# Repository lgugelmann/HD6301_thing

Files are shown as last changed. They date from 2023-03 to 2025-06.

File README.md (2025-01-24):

# Exploring the HD6301V1

I recently received a few samples of a Hitachi `HD6301V1` in a DIP-40
package. It's a 1MHz 8bit CPU derived from the Motorola 6801 with a few extra
instructions. It has an onboard mask-programmed 4k ROM, 128 bytes RAM, and 4 I/O
ports that can be used as some combination of data or address bus, or I/O
lines. It also comes with an onboard serial interface. Overall it's a really
neat chip!

- The datasheet for the HD6301v1 can be found
e.g. [here](https://pdf1.alldatasheet.com/datasheet-pdf/view/87402/HITACHI/HD6301V1.html).
- An _extensive_ handbook for the entire Hitachi 6301/6303 series of CPUs,
including copies of all datasheets, can be found on
[archive.org](https://archive.org/details/bitsavers_hitachidateriesHandbook1989_54281821).

This repository contains schematics and code to build a retro-inspired computer
around this chip. The idea is to build this off of modular components and a
shared bus so we can start small and build up piece by piece.

Currently I have a working device with Arduino-like ease of programmability, PS2
keyboard input, HDMI video output. It's complete enough for a working 'Snake'
clone that can be played over both serial console and video out.

## Getting started on a breadboard

The architecture is quite simple and similar to other 8-bit CPUs like
the 6502. There is one 16-bit address bus, one 8-bit data bus, a clock line, a
read/write line, and an interrupt line.

One way in which this chip departs from e.g. a 6502 is that it has several
different 'modes' that affect the memory layout and external buses. Mode
selection is done at startup using the first 3 lines of port 2. After startup
these lines can be reused for other purposes if desired. Mode 1
(non-multiplexed) breaks out all 16 address and 8 data lines. Mode 5 reduces the
external address bus to 8 lines. Mode 0/2/4/6 multiplex the data bus: at the
beginning of the cycle the 8 low address bits are presented, then an address
latch signal fires, then the 8 data bits are set. This frees up one 8-bit port
for I/O. Mode 7 has no external buses at all. Mode 0/5/6/7 map the internal ROM
to the top of the address space. It's inaccessible in 1/2/4. Mode 0 ('test
mode') has a special handling for the first read of the startup vector addresses
at $FFFE/$FFFF: instead of reading them from ROM (as it would in any subsequent
read) they are read over the external bus. This allows one to override the
ROM-interal startup vector while still keeping it accessible otherwise.

By selecting mode 1 at startup it's easy to get this chip to work on a
breadboard by just adding some external parallel RAM / ROM with a bit of address
decoding to select which one to access.

The chip has an internal 4x clock-divider. To get it to run at the max 1MHz you
need a 4MHz oscillator. I had no stability issues on a breadboard even at max
frequency.

The chip requires a minimum 100kHz to run (400kHz oscillator). Going below makes
it unstable.

## Random hardware notes

This is a collection of random notes about the hardware that are either
well-hidden in the datasheet or not documented at all.

- The IRQ line is not specified to be open-drain. It's likely not.
- The reset and standby pins are drawn with Schmitt-trigger inputs in the
  datasheet.
- The datasheet recommends 74'373 chips to latch the address bits in multiplexed
  mode. The '573 is probably a better choice for layout reasons as it has the
  same functionality but instead of having in/out pins next to each other it has
  all 8 inputs on one side and the 8 outputs on the other.
- P21 is not a general purpose I/O pin (even after mode selection). It is either
  a general input, or timer output.
- The mode selection / P2 multiplexing circuit in the datasheet would probably
  not work with a modern '4053 chip. The one in the datasheet has minimum
  switching times higher than the required hold times on the mode selection
  pins. Modern '4053 are faster.
- Reset and power-up are a bit finicky. The datasheet says reset must be held
  low for at least 20ms at power-on time. That's good advice. Without the wait
  time the MCU seems to start working a hair before the power rail reaches
  3V. The clock and data / address lines have their 'high' bits at that voltage
  too. At that point in time a typical 5V ROM might not even have powered up yet
  and you get all sorts of fun non-deterministic behavior. Something like a
  Diodes Inc. `APX811-46` is a great way to satisfy that requirement as it keeps
  reset low after power-up for 100-200ms.  Alternatively, the datasheet seems to
  suggest that the reset line has a Schmitt-trigger input. That would make an RC
  circuit with a long time constant also workable. Have not tried that.
- Exiting the standby mode requires holding reset low 20ms longer than STBY.

## The mask-programmed ROM

The samples I have come mask-programmed with some unknown code. The
`internal_rom` folder contains a dump of that ROM, some very preliminary
disassembly, and details on how to do such a dump using the 'test mode' of the
chip.

The ROM configures the data direction registers of all 4 I/O ports to a
combination of inputs/outputs. This suggests that it was meant to work in
single-chip mode. The MC6801 was popular in automotive applications - maybe this
one was meant to go into a car too.

## Contents of the repository

### Hardware modules

On the hardware side the repository contains
- The main CPU board. This can be used as a fully functional standalone
  single-board computer with 32kB RAM and ROM.
- A programming board to make programming the main CPU board as easy as
  programming an Arduino. This is a Raspberry Pi Pico-based board for USB
  connectivity to a host computer. It can put the main CPU into standby, take
  over the bus, and read or write to RAM/ROM as needed.
- A "video chip" board with HDMI output. This is another Pi Pico-based board
  that implements various graphical modes like a 100x40 or 100x75 text terminal
  with 6-bit color for each foreground and background. On the HDMI side it's
  800x600 pixel. On the bus it presents 64 write-only registers that implement
  various commands like setting characters, colors, or doing cursor moves.

Currently in progress are:
- An audio board based around the OPL3 FM synthesis chips.

### Software

#### HD6301 programs

The 'asm' folder contains software to run on the HD6301. There is a monitor
program for debugging, running other programs, and to provide some basic
libraries for PS2 keyboard handling and more.

There are also various test programs as well as a 'Snake' clone and a simple
audio sequencer.

See the docs in the 'asm' folder for more details.

#### Supporting software

- Much of the glue logic (address decoding, PS2 serial/parallel decoding, etc.)
  is implemented with GreenPAK SLG46826 programmable logic chips (see
  below). The 'greenpak' folder contains a simple python script to program these
  chips via i2c using an FTDI232h breakout board.
- The 'pico\_programmer' and 'pico\_graphics' folders contain the respective
  software for those those chips. The pico programmer has two parts: one to go
  onto the Pi Pico and a Python program to interface with it via serial port to
  do the actual programming.

## Bus documentation

All modules communicate over the following shared bus.

| Pin number | Function | Notes |
|---|---|---|
| 1..4 | Data bits D0..D3 | Bus users need to coordinate who's driving |
| 5 | 5V | Only one device is allowed to power this |
| 6 | GND | |
| 7..10 | Data bits D4..D7 | Bus users need to coordinate who's driving |
| 11..14 | Address bits A0..A3 | Bus users need to coordinate who's driving |
| 15 | 3.3V | Only one device is allowed to power this, optional |
| 16 | GND | |
| 17..24 | A4..A11 | Bus users need to coordinate who's driving |
| 25 | GND | |
| 26 | 3.3V | Only one device is allowed to power this, optional |
| 27..30 | A12..A15 | Bus users need to coordinate who's driving |
| 31 | RX | Serial receive as seen from a device on the bus |
| 32 | TX | Serial transmit as seen from a device on the bus |
| 33 | CLK | Bus clock |
| 34 | R/WB | Read is high |
| 35 | GND | |
| 36 | 5V | Only one device is allowed to power this |
| 37 | C1 | Control line 1, up to the exact devices on the bus to decide what this does. |
| 38 | C2 | Control line 2, up to the exact devices on the bus to decide what this does. |
| 39 | RESETB | Active low reset. Open drain. Pullup on CPU board. |
| 40 | IRQB | Active low interrupt. Open drain. Pullup on CPU board. |

This is 40 pins as it's easy to find 40pin IDC connectors and ribbon cables. The
power / GND pins are mirrored so that an upside-down connector has them in the
same place.

There are no chip select pins. Additional boards that want to fit into specific
parts of the memory map need to decode the address pins on their board and
coordinate with everyone else. Programmable GreenPAKs make this easy enough.

Pins are all push-pull unless stated otherwise. Any shared use needs to be
coordinated.

Logic levels are assumed 5V CMOS.

This is not how one designs for signal integrity - but it works well enough for
me. The user-friendliness of getting a ribbon cable to a breadboard to prototype
the next module is the overriding concern here.

### Bus details for HD6301 board

| Pin number | Function | Notes |
|---|---|---|
| 38 | STBYB | Active low standby signal. For Pico Programmer to make HD6301 let go of the bus. |

## Work log

This section contains possible projects and the state of the current in-progress
pieces of work.

### Faster SD card reads

The next goal is to get faster SD card reads as described in `asm/README.md`.
This means emulating the schematic in `io_board` in the emulator.

Tasks:

- Emulator:
  - ~~Create basic shift register output support in W65C22~~
  - ~~Figure out how to emulate clock inversion and delay~~
  - ~~Emulate a serial-in, parallel-out shift register like 74'164 series.~~
  - ~~Connect the above two pieces in-between the W65C22 and the current SPI emulation.~~
- ASM
  - ~~Update the code to use SR instead of bit-banging on a port for SPI~~
- Hardware
  - ~~Actually try the approach in real hardware~~ \[done, down to ~10ms\]
  - Write out schematics and design the board

### Documentation and repository cleanup

Any day now! This README file is badly outdated vs the state of the project. It
doesn't mention the emulator at all for example. The various hardware modules
should also be listed and better documented.

Tasks:

- Pick a standard for how to structure the individual module folders and stick to it
  - Put a README.md with each module, and document all known hardware issues.
  - I don't like the catch-all `greenpak` folder. That should go with the modules.
- Get rid of the `ft231x_programmer` stuff. It's an early idea that's now badly
  outdated.
- Rename `board` to something better.
- Add README.md to the `tools` folder.
- Update this file with a better overall description. It's very very out of date.

### General ASM improvements

Tasks:

- Define and implement a standard for error reporting. With FAT16, MIDI decoding
  etc there is some complex logic that could benefit from a standard way to pass
  around errors and refer to standard error strings for them.

### FAT16 improvements

The current FAT16 code is read-only and is limited to using only one sector of
FAT (so only 254 clusters). This is not an actual limitation yet. The APIs are a
bit wonky, the error reporting inconsistent.

Tasks:

- Implement write support
  - Goal: Snake should get persistent high scores.
- Implement support for using more than just the first FAT sector

### Expanding the programmer board to be a runtime monitor thing too

Right now the programmer board has the ability to read almost the entire bus
(data, address, IRQ), but we're not doing anything with that. An idea would be
to also plumb CLK back to the Pico and very quickly sample the bus on clock
edges. Wiring-wise this should be possible on the existing board by changing the
GreenPAK setup - the C1 pin is unused on the Pico side.

It's not clear that we can do this fast enough (easily), but it's worth trying
out. It's probably very much possible to do the hard way as we can bit-bang at
400+MHz for the DVI out using PIO.

Some math:

- The internets claim that Pico interrupt latency can be brought down to
  100-200ns. A busy-loop on the pin state ~70ns.
- The LVC245 in use take 10ns max to go from OE to data available.
- No idea how fast one can read 8 data pins - but probably tens of ns. Say 50 as
  an upper bound.

If we take some upper bounds we get 200 trigger + 3 * (10 + 50) ~= 400ns. We
have 500ns budget between clock edges so this sounds doable. Afterwards we have
500 more ns to do some data processing until the next interesting edge.

Assume we have ~100k of RAM free (total 264k, seems reasonable). If we store 3
bytes per clock cycle we get roughly 30ms of data in a buffer before we run
over. In total we generate 3MB/s. Getting those off the Pico in a continuous
fashion does not seem doable without trickery. The theoretical maximum is
12Mbit/s, or 1.5MB/sec. In practice folks seem to get somewhere between 500 and
850 KiB/sec. The minimum information needed to code the instructions would be:
instruction, address (if needed), data. A 3-byte instruction typically takes 4
cycles and would have 4 bytes of data total (1 instruction, 2 address, 1
data). We'd get a factor 3 compression here if that's the average case. It might
just barely be possible to stream things continuously.

Tasks:

- Rework the GreenPAK setup to get the clock back to a Pico input pin.
- See how fast the IRQ triggers and whether we can sample the bus on time.

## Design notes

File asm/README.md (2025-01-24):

# 6301 Software

This folder contains a monitor program and a number of 'user programs' that can
be launched from the monitor.

The `include/` directory contains a number of utilities like keyboard handling,
ps2 decoding, code to talk to the serial or graphical terminal and more.

## Assembler

The code and Makefiles here are written to use the
[AS](http://john.ccac.rwth-aachen.de:8000/as/) assembler. It's very
feature-packed, in active development, and one of the few that also supports the
4 extra instructions that the HD6301 introduced.

## Basic design

### Monitor program

The "monitor program" is responsible for basic hardware initialization, IRQ
handling, and providing various system-level routines for I/O etc. It also has
a basic [command line interface](#monitor-commands) and basic debugging functionality.

It's still called `monitor.s` because it started out as a traditional monitor
and then extended well past that. It gets to keep the name due to history.

The code is structured as a number of modules which each define
`[module_name]_init`, `[module_name]_irq` etc. as needed. These modules use
ASL's `SECTION` scoping concept that hides everything inside a section, unless
it's `PUBLIC` and/or `SHARED`. Things marked `PUBLIC` are visible to the monitor
code including them. Things that are marked as `SHARED`[^1] are also listed in a
`monitor.inc` file that's created during monitor assembly. Those are available
to "user programs" (as much as that makes sense on hardware that doesn't offer
any sort of support for such a separation).

Some modules are utility functions, some are specifically meant to initialize
various hardware boards (`sound.inc` for the OPL3 board, `midi_uart.inc` for the
MIDI board, etc.).

The `include` folder also contains a number of files defining useful constants
like e.g. register addresses, general midi instrument definitions.

Lastly it also contains a `macros.inc` that contains macros useful to coordinate
memory usage across the monitor and user programs. For example `zp_var name,
size` reserves `size` many bytes in the zero page and gives them the label
`label` guaranteeing that they won't conflict with zero page variables used by
the monitor. See that file for details.

[^1]: there is a `PUBLIC_SHARED` convenience macro that combines the two into
  one.

### User programs

"User programs" are defined in the `programs` directory. They are bundled
together by an auto-generated `programs.s` file created by the
`generate_programs_list.py` utility at build time. That file also sets up the
"program registry" which lists names and start addresses for all programs in the
ROM. That's the structure the monitor programs `list` and `run` use to do their
thing. The set of programs to be built is configurable via CMake variables.
There is also the option to make one program auto-run at reset.

By convention, and to avoid conflicts, each program has a `SECTION` named after
itself, and exports only a `program_name_start` function outside of itself.

The separation between user code and monitor code makes it possible to flash
each part independently of each other and increase iteration speed.

If you're running in a user program you exit back to the monitor via the last
`rts`. You can also issue a software interrupt (the `swi` instruction) or hit
the 'break' key to get back into the monitor at any time.

> [!WARNING] After any change to monitor code it's prudent to reflash both
> monitor and programs. Chances are high that the addresses of monitor function
> have moved around. Existing user programs might jump to the wrong location and
> crash.

## I/O

Output routines of the "standard library" like `putchar`, `putstring` etc. work
both over serial and graphical output. Input can come from both serial and
keyboard. However note that there is no "break" key over serial - that requires
a physical keyboard to be connected.

There is an attempt to keep them roughly in sync, but there are some warts. For
example, commands that move the cursor around exist only in graphics mode. That
being said: look at `programs/snake.s` for how to do cursor movement over serial
too. Maybe at some point we'll put that into the standard library too.

This "dual stack" setup makes I/O a bit slow, but it's also very convenient. To
get back speed (and to make the timings of the emulator and real hardware more
comparable) there is a variable in `include/stdio.inc` called
`__enable_serial_io` to enable or disable serial I/O.

## Monitor commands

- `reset`: Run the monitor init routine, i.e. the code pointed to by the CPU
  reset vector.
- `run [program name]`: runs the named program. Short form: `r`.
- `list`: Lists the available programs.
- `continue`: If a user program is running, get back to it. Short form: `c`.
- `print`: If a user program is running print its current condition code
   register, A, B, X registers, stack pointer, and program counter. Short form: `p`.
- `ls`: If there is a FAT16 formatted SD card available, it lists the contents
  of the current directory.
- `cd [directory]`: change working directory. Only works one directory at a
  time, i.e. `cd foo/bar` doesn't work and needs to be separate `cd foo`, `cd
  bar`.

## Memory map

See the comment at the start of `include/memory_map.inc`.

## Programming the ROM

There are three CMake targets: `monitor_prog`, `programs_prog`, and `prog`.
These will assemble either monitor, program, or both and write it at the
appropriate location in the ROM.

The monitor program goes at the end of the ROM, starting at the latest
4k-aligned block. Currently that's `$d000` (see the `org` directive in
`monitor.s`). This wastes a bit of space between monitor code and the vectors
starting at `$fff0`, but the flash chip has pages of 4k size. Until we start to
run low on storage this makes no difference to programming speed and is easier
to reason about.

The user programs are put at the start of the ROM with the program registry at
`$8000` and the user programs after that.

## TODOs and ideas for improvements

- Add graphics save / restore commands to pico graphics to use for
   entering/exiting the monitor without interfering with user programs.
- Hexdump for memory in the monitor.
- A `help` command for the monitor.
- Make I/O over graphics, serial, keyboard or all of them selectable at compile
  or runtime to avoid any speed penalties.

### Project: Making SD Card reads *fast*

SD card reads are currently relatively slow. Reading a single page currently
takes ~120ms according to the `sdbench.s` program run in the emulator and
assuming 1MHz clock. This is much slower than a theoretical target of
e.g. reading one bit per cycle, which would take 8µs * 512 = 4096µs or ~4ms.

There are multiple ways to address this, from faster software to better hardware
tricks like using a wider bus, offloading some SPI processing etc.

#### Bit-banging approach

For record keeping, the optimizations so far - in `sdbench.s` numbers - are:

- `57058 01`, baseline. That's 57058 + 65536 = 122594 cycles, or ~122ms.
- `51426 01`, saved 6ms by inlining the hot SPI byte reads.
- `30221 01`, saved 21ms by unrolling the 8 bit loop and saving `pushx`/`pulx`
  pairs.
- `22029 01`, saved 8ms by using the fact that CLK is bit 0 and `inc b` / `dec
  b` is 2 cycles shorter than two `eor b,#CLK` to raise / lower the clock.
- `25884 01`, lost 4ms again by choosing to not inline the `spi_receive_byte`
  but moving the above optimizations there. Cleaner code wins over a small speed
  bump. Total now at ~91ms, or a 25% improvement.

The current bitbang code for each bit is this:

```asm
        inc b                   ; 1 cycle
        stb IO_ORA              ; 4 cycles, raise clock
        asl a                   ; 1 cycle
        tst IO_IRA              ; 4 cycles, sets N to PA7
        bpl +                   ; 3 cycles, On 0 we don't need the 'inc a'
        inc a                   ; 1 cycle
+       dec b                   ; 1 cycle
        stb IO_ORA              ; 4 cycles, Lower clock
```

It doesn't look like it can be simplified much, and it's 19 cycles long. With a
few extra instructions for setup that's 160 cycles per byte. Assuming no extra
cost that works out to ~81ms per sector as a hard limit.

#### Shift-register approach

The W65C22 has a shift register that can work as fast as half the system
clock. That's potentially 16 cycles per byte plus code to read them. CB1 outputs
a clock signal, CB2 receives input data. The clock is high when idle, data is
supposed to be prepared on the falling edge, and the W65C22 samples it on the
rising clock edge.

The issue is that SD Cards speak SPI mode 0, which requires a clock that's low
when idle, and samples on the rising edge. Inverting the '22 clock makes it low
on idle, but the sampling happens on the wrong edge.

For communication from the '22 to the SD card one can invert the clock and delay
it by ~1 cycle to make it work.

For communication from the SD card to the '22 we can use a 74xx595 shift
register for serial to parallel conversion and connect the 8 bits to a full
port. It's clocked the same way as the write side and with a bit of glue logic
the register latch on the 595 can be triggered only once every 8 clock pulses.
This allows the previously shifted-in data to persist on a '22 port while the
next transfer is already in progress.

The CS line can be handled with CA2 for example to avoid using up an additional
pin on a port.

Sending data is then a write into the SR, and 18 cycles to clock it out (2 per
bit, and 2 cycles setup delay). Receiving data requires a write into the SR to
get the clock going, an 18 cycles delay, then a read on the port. With the '595
trick above it's possible to read the previous data *after* starting the next
transfer by ensuring that no interrupt can get in-between the write and the read
(as otherwise the previous data would be overwritten). The current code does
this in 19 cycles per byte (plus a bit of amortized overhead), which works out
to ~10ms per 512 bytes.

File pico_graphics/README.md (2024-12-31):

# Pico Graphics

## TODOs for next revision

- reset button for the pico
- figure out the powerup problems
- R/W interface + interrupts

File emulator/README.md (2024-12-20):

# HD6301-thing emulator

The goal of this emulator is to be able to run the asm code in the `asm` folder
with a reasonable degree of accuracy, including graphics, sound, and I/O.

## Features

The emulator has code for all hardware boards in the rest of this repository
with enough accuracy that it can run all current code. In particular:

- A CPU core emulating most of the HD6301V1 processor
  - I/O ports 1 and 2 are available. Port 2 is actually 8 bits instead of 5, and
    it doesn't share pins with the SCI.
  - Mode selection doesn't happen. The CPU is always in mode 2/4.
  - The SCI only implements internal clock sources, and basic rx/tx. It doesn't
    do overrun and framing checks. It doesn't implement wake-up either.
  - The timer only supports counting / overflow and none of the P2 modes.
  - Only reset, irq, SCI, and timer interrupt vectors are used.
  - A few instructions aren't implemented yet: `daa`, `slp`, `wai` and `swi`.
- A PS2 keyboard emulation. Ish, it's one way only, and it's 8 bit parallel
  connected to port1 of the CPU instead of serial (like the actual hardware).
- Full emulation for the `pico_graphics` graphics board
  - Some timing might be off. All operations in the emulator complete in one
    tick, the real hardware is a bit slower in some cases (though I never spent
    time characterizing this exactly, so who knows?)
- OPL3 chip emulation courtesy of the Nuked-OPL3 emulator.
  - Due to the way sound is generated in batches, the OPL3 commands might be
    slightly misaligned vs actual hardware.
- TL16C2550 emulation for the MIDI board. This one is really basic still and
  most of the features aren't there. Proper baud rate, buffers, etc. are not
  implemented. The second UART isn't implemented either.
- Incomplete WD65C22 VIA emulation
  - Ports A/B, some shift register output support.
- Bare-bones emulation of an SD card SPI interface attached to WD65C22 port A.

The serial interfaces can be interacted with by reading/writing on the PTYs
printed on the console when the emulator starts.

There is an optional dependency on RtMidi. If it's available, then a virtual
MIDI input port is created that makes it easier to talk to the emulated MIDI
board.

## How to compile

The emulator has a hard dependency on SDL2, and an optional one on RtMidi. It
can be built using CMake. Create a build directory somewhere, e.g.
`emulator/build`. Then in that directory run `cmake [path to CMakeList.txt]`. In
the example before that's `cmake ..`. After successfully configuring, run `make`
(or `ninja` if that's what your CMake does) to create the `emulator` binary.

Alternatively, open the project in VSCode and hit F7 (assuming you have the
CMake extensions installed - which is very likely).

NOTE: The CMake setup is not particularly great. For example it doesn't set up
  minimum versions for any libraries used.

## Creating a ROM file to run

In the `/asm` directory run `make rom` to create a combined monitor / programs
rom (called `/asm/rom.bin`). You can also create just the monitor ROM (`make
monitor`), or the programs ROM. However note that the latter can't run without
the monitor one though.

See the documentation there for the prerequisites for assembling a ROM image.

## Running the emulator

```sh
./emulator --rom_file=[rom file] --sd_image_file=[sd card image]
```

The `--sd_image_file` part is optional. The current ROM will just throw an
SD-related error at startup if you don't pass one. You can generate an image by
running the `make_fat16_sd_image.sh` command in the `../tools/` directory.

There are a few extra command line options. To see them, run `./emulator
--helpfull`. There are somewhat verbose `VLOG()` statements sprinkled in the
codebase for some debugging help, level 3 and above prints every instruction
that's being run for example. For that, add `-v 3 --stderrthreshold 0` to the
command line for example.

## Things to try

After you start the ROM file you'll see the monitor prompt like this:

```text

>
```

Try `list` to see a list of available programs. You can run them with `run` or
`r` followed by the program name. For example:

```text
> list
edi 94B7
graphics_test 9A5E
hello 9B21
keyboard_test 9B5D
midi_synth 9B80
opl3_test 9EAC
random A055
sci_echo A071
seq A2ED
serial_opl3 A5FF
snake A664
test AA2C
volume_test AA4D

> run graphics_test
```

runs a basic graphics test and drops you back into the monitor.

To get back to the monitor from any program, hit the 'Pause / Break' key on your
keyboard. You'll see a dump of the status register flags, the A, B, X registers,
the program counter, and the stack pointer, and then the familiar monitor prompt.

```text
--HINZVC  A  B    X   PC   SP
11000100 00 00 100B F89B 7DF2
>
```

To get back to the running program use the `continue` or `c` command.

Other available commands are `reset` which starts the system fresh, and `clear`
which resets the graphics. That last command may also bring back the cursor.
Some programs disable it and don't turn it back on on exit :-).

There are also basic implementations of the file system commands `ls`, `cd`, and
`cat`. They work on the SD card image.

## Profiling & sanitizer runs

### Profiling

There is some support for profiling using
[gperftools](https://github.com/gperftools/gperftools). To do so turn on the
`GPERFTOOLS_BUILD` option (e.g. by using `ccmake .` in the build folder) and
recompile.

To get a profile run the emulator with:

```sh
CPUPROFILE=cpu.profile ./emulator --rom_file=../asm/rom.bin
```

You can then examine the profile with e.g. `pprof` using:

```sh
pprof -http localhost:8080 ./emulator cpu.profile
```

### Sanitizers

To run a ThreadSanitizer build enable the `TSAN_BUILD` option (see above for
how) and rebuild.

Running the binary now prints warnings about potential threading issues.

Note: On my system TSan flags a false positive with audio buffers passing
  between SDL and Pulseaudio.

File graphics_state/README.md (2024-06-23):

# Graphics state library

This is a small library that allows sharing most of the graphics code (command
parsing, etc) between the emulator and the pico_graphics firmware.

It's heavily geared towards being easy to use in the Pico code. That's why the
color formats are weird and there are a few `inline` hints.

If the library is included in a project which also has the Pico SDK loaded and
the `PICO_COPY_TO_RAM` option set, then all functions are decorated with the
`__not_in_flash()` hint to make sure they run from RAM. Without these hints the
code is too slow.

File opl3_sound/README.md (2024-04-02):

# OPL3 sound board

## Hardware

This board contains OPL3 chips: YMF262 (the digital FM sound chip) and its
compainon YAC512 digital-analog-converter. It also has a mono amplifier for a
small speaker and a stereo one for headphones. Plugging headphones in/out
switches from spaker to headphones or back.

### Quirks and possible gotchas

- Writes are triggered on the *rising* edge of WR/CS (whichever is first)

#### Timer interrupts

The OPL3 datasheet omits to mention that when writing a 1 to the `RST` bit in
register `$04`, all other bits are ignored.

This is convenient as it allows IRQ routines to clear the interrupt without
needing to keep track of the rest of the register.

#### Hardware notes / bugs in v2

- Volume doesn't go all the way down
- Forgot pullups for i2c on GreenPAK

## Software

There is a small utility `opl3.py` to interface with the OPL3 board via serial
port. This requires the `serial_opl3` program to be running on the 6301 thing.

The most interesting functionality is probably `opl3.py play [vgm file]` which
plays a VGM file intended for OPL3 on the sound board.

The rest of the functionality is probably in various states of disrepair. It was
used for board bring-up and early testing and not maintained since.

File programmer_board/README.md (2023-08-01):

# Pi Pico programmer board

> ***WARNING***
> the 1.0 version of the board is buggy. At a minimum it requires adding
> pullups on all OE pins. The Pico does not start quickly enough to put them into
> a good state. The resulting bus contention uses enough power to render the Pico
> unable to start. For any sane current limit the '5V' rail gets drawn down to
> less than the ~1.8V needed for the Pico boost converter to start working. The
> Schematic & PCB have not been updated to fix this bug yet. It's not hard to fix
> the v1.0 board by reworking some extra resistors onto it.

A common way to program ROMs for 8-bit hobby projects are ZIF sockets. Take ROM
out, put it into programmer, program it, put it back into the ZIF socket,
run. That works, but it gets tedious _really fast_. It's also getting harder and
harder to find parallel ROMs in DIP packages at reasonable prices. The solution
is to bite the bullet and use soldered-down ROMs in smaller packages and figure
out in-circuit programming.

The goal here is to make programming the HD6301 board as easy as programming an
Arduino from a modern computer, while at the same time keeping the HD6301 board
able to work independently without this development companion.

This is accomplished by having a Pi Pico expose a serial console to receive
commands from a computer. To program the HD6301 board the Pico puts the CPU into
standby mode, takes over the bus, reads or writes to arbitrary memory locations
(which allows it to program the ROM among other things), and wakes the HD6301
back up.

This technique makes for a fairly generic interface to many 8-bit era
devices. It could work easily for a 6502-based computer as well (at least for
versions with a bus-enable line).

Programming 8k (2 sectors) of ROM takes just a few seconds.

The board itself is pretty simple. The main issue is that the Pico does not have
enough I/O lines, and that it's not 5V tolerant. This means we need both
multiplexing and voltage translation. The address and data pins are all
connected in groups of 8 pins to a pair of 74LVC245 bus buffers and 74HCT573
latches. The latch holds the output data, while the '245 does voltage
translation for inputs. It's up to the software on the Pico to correctly juggle
the various output enable pins to avoid bus contention. The remaining lines are
voltage-translated by a GreenPAK programmable logic chip that can do 3.3V on
some GPIOs and 5V, tri-state on others.

The Pico was chosen here because it's trivial to prototype with it and it makes
it easy to expose 2 serial lines on the USB side. One is used for programming,
and one to communicate with the HD6301's own serial interface.

The initial plan was to use a much dumber chip like FTDI USB interfaces and put
all the logic on the other side of the serial interface. USB latency(!) made
that plan unworkable. See below for the details.

## TODOs for the next revision

- Add pull-ups on all OE pins and D0..D7 to guarantee safe initial state
- Jumpers for all power rails to isolate the Pico
- Some solution for power rail filtering. My desktop's USB ports are
  _NOISY_. Not a problem for digital work - but the OPL3 audio board suffers
  from bad filtering here.

## In-circuit programming via USB - the gory details

## FT231x solution

At first I explored using an FTDI FT231x. It's 5V compatible and conveniently
also gets us USB serial. It has an 8-pin bitbang mode and 4 additional 'CBUS'
lines. Those can be programmed to be GPIOs, write strobes, and more.

The first solution was to use the 8bit GPIOs for data and CBUS for control
lines. Unfortunately the CBUS GPIO mode can't be used concurrently with the
bitbang mode and switching between bitbang and CBUS takes a _long_ time (think
hundreds of ms). Switching between the two for every byte makes things
unworkably slow.

Next up I turned to putting glue logic on a GreenPAK chip and using the
write-strobe mode. This works really nicely: first write puts the chip in
standby, subsequent writes latch data, address low, address high onto '74xx573
latches, and after that the GreenPAK automatically strobes clock & R/W. After a
few hundred ms without activity everything resets and the 6301 wakes back up.

This works really nicely for a write-only in-circuit programmer. There is a
tested working python-based programmer and the necessary GreenPAK glue logic in
this repo. I didn't push for performance but got to ~15 seconds to write a 32K
ROM.

Next up I tried to figure out how to implement a read-mode as well. In theory it
should be easy: put a 74'245 on the data bus, do the same latching trick as
before, but instead at the end bring OE low on the '245 and read the FT231x I/O
pins. A CBUS line can be used to put the GreenPAK into a read-mode with
different strobes / timings, but because that needs to be done only once at the
start it should be fast enough.

I got this to work - but it's sloooow because of USB latency, se below for
why. Tl;dr: switching between reading / writing on the FT231x for every byte
takes >1ms each time. This means 1 minute to read the whole address space at a
minimum. The fastest I could manage is ~3ms per byte before I gave up.

There could be possible solutions that do not require switching between reading
and writing at each byte. One option is to use a CBUS line for a read strobe and
discrete logic to increment an address counter at each strobe. You could set up
the counter at the start, then put the chip into read mode, and stream the data
back. This starts to get a bit silly and would also require futzing around with
the FT231x read buffers which seem to be particularly tricky to synchronize to
anything.

Another option is to use a synchronous bit-bang mode where a read is done on
every write and streamed back. The catch here is that you have to decide ahead
of time which pins are inputs and which are outputs. I could split the 8 bits
into 4 in / 4 out but that would also require extra glue logic that I didn't
feel like building.

### USB latency ruins the party

USB communication (before 3.0) is _always_ host-initiated. No usb device can
just decide to send data. It needs to be asked by the host whether there is
anything that it might want to send first. The fastest polling rate available
from the host side is 1ms.

This means that if switching between reading and writing requires a control
packet there is a mandatory 1ms latency hit: 1 packet with the writes (which can
be all sent bunched up into one), then a second packet with the command to
switch from read to write, then another packet to poll for the read data. On the
ft231x that's 2ms latency / byte at a minimum as we need to wait out the polling
interval twice.

### Pi Pico programmer

To avoid USB latency I need something capable of receiving a "read x bytes
starting at address y" command and then stream the data back. I have a spare Pi
Pico laying around so I went with that. It has enough I/O, has support for
multiple UARTs (so one for programming, one for comms with the HD6301), and
comes with both 5V and 3.3V rail which can be convenient. Downside: not 5V
tolerant.

The 5V issue is easy to solve: for the data output from the Pico I use
TTL-compatible '74xxT573 latches, for the data input to the Pico 3.3V '74LVHC245
buffers which are 5V tolerant. For the control lines I make use of the dual
supply feature of the _really really cool_ SLG46826 GreenPAK to have 3.3V I/O on
the Pico side and tri-state 5V I/O on the HD6301 bus side.

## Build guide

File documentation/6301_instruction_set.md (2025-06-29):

### HD6301/HD6303 Instruction Set Reference

This table provides a concise overview of the HD6301/HD6303 instruction set. It details each instruction's mnemonic, syntax, addressing mode, byte length, machine code, CPU cycles, affected condition code bits, symbolic operation, and a brief description of its function.

NOTE: The table is AI-Generated from code and other documentation. Not yet validated for correctness!

**Abbreviations and Symbols Used:**

* **Registers:**
  * `A`, `B`: Accumulator A, B.
  * `X`: Index register (16-bit).
  * `PC`: Program Counter (16-bit).
  * `SP`: Stack Pointer (16-bit).
  * `SR`: Status Register (Condition Code Register - CCR).
  * `ACCD`: Double accumulator (ACCA + ACCB, 16 bits).
  * `IXH`, `IXL`: MSB 8 bits and LSB 8 bits of the Index register, respectively.
  * `PCH`, `PCL`: MSB 8 bits and LSB 8 bits of the Program Counter, respectively.
  * `SPH`, `SPL`: MSB 8 bits and LSB 8 bits of the Stack Pointer, respectively.
* **Condition Code Register (CCR) Statuses:**
  * `C`: Carry status (Carry and borrow; bit 0).
  * `Z`: Zero status (Zero; bit 2).
  * `S`: Sign status (Negative; bit 3).
  * `O`: Overflow status (Overflow for 2's complement; bit 1).
  * `Ac`: Auxiliary Carry status (Half carry from bit 3 to bit 4; bit 5).
  * `I`: Interrupt Mask status (Interrupt mask; bit 4).
* **Symbols in the STATUSES column:**
  * **(blank) / -**: Operation does not affect status.
  * **x**: Operation affects status (sets or clears based on result).
  * **0**: Flag is cleared by the operation.
  * **1**: Flag is set by the operation.
* **Operands/Addresses:**
  * `data8`: 8-bit immediate data.
  * `data16`: 16-bit immediate data.
  * `addr8`: 8-bit direct address.
  * `addr16`: 16-bit extended address.
  * `Disp`: 8-bit signed address displacement.
  * `Rel`: 8-bit signed relative address (offset).
  * `M`: Memory address.
  * `MH`, `ML`: MSB 8 bits and LSB 8 bits of memory address.
* **Symbolic Operations:**
  * `[ ]`: Content of...
  * `[[ ]]`: Implied addressing (content of [content of...]).
  * `←`: Data is transferred in the direction of the arrow.
  * `∧`: Logical AND operation.
  * `∨`: Logical OR operation.
  * `⊻`: Logical Exclusive-OR operation.
  * `¬`: Logical NOT operation.
  * `Mi`: Bit `i` of memory location `M`.
  * `Xn`: Bit `n` of Accumulator X (A or B).

---

| MNEMO | SYNTAX | MODE | BYTES | CODE (Hex) | CYCLES | C | Z | S | O | Ac | I | SYMBOLIC OPERATION | DESCRIPTION |
| :---- | :--- | :--- | :---- | :--- | :----- | :-: | :-: | :-: | :-: | :--: | :-: | :--- | :--- |
| ABA | `ABA` | INH | 1 | `1B` | 1 | x | x | x | x | x | - | `[A] ← [A] + [B]` | **Add Accumulator B to Accumulator A.** Adds the contents of Accumulator B to Accumulator A and stores the result in Accumulator A. |
| ABX | `ABX` | INH | 1 | `3A` | 1 | - | - | - | - | - | - | `[X] ← [X] + [B]` | **Add Accumulator B to Index Register.** Adds the unsigned contents of Accumulator B to the Index Register, taking into account a carry from the low-order byte of the Index Register, and stores the result in the Index Register. |
| ADC | `A #data8` | IMM | 2 | `89 data8` | 2 | x | x | x | x | x | - | `[A] ← [A] + data8 + C` | **Add with Carry.** Adds the contents of Accumulator A, immediate data, and the Carry bit C, storing the result in Accumulator A. |
| ADC | `A addr8` | DIR | 2 | `99 addr8` | 3 | x | x | x | x | x | - | `[A] ← [A] + [addr8] + C`  | Adds the contents of Accumulator A, memory at `addr8`, and the Carry bit C, storing the result in Accumulator A. |
| ADC | `A Disp,X` | IDX | 2 | `A9 Disp`  | 4 | x | x | x | x | x | - | `[A] ← [A] + [Disp+[X]] + C` | Adds the contents of Accumulator A, memory at `Disp + [X]`, and the Carry bit C, storing the result in Accumulator A. |
| ADC | `A addr16` | EXT | 3 | `B9 MH ML` | 4 | x | x | x | x | x | - | `[A] ← [A] + [addr16] + C` | Adds the contents of Accumulator A, memory at `addr16`, and the Carry bit C, storing the result in Accumulator A. |
| ADC | `B #data8` | IMM | 2 | `C9 data8` | 2 | x | x | x | x | x | - | `[B] ← [B] + data8 + C` | Adds the contents of Accumulator B, immediate data, and the Carry bit C, storing the result in Accumulator B. |
| ADC | `B addr8` | DIR | 2 | `D9 addr8` | 3 | x | x | x | x | x | - | `[B] ← [B] + [addr8] + C`  | Adds the contents of Accumulator B, memory at `addr8`, and the Carry bit C, storing the result in Accumulator B. |
| ADC | `B Disp,X` | IDX | 2 | `E9 Disp`  | 4 | x | x | x | x | x | - | `[B] ← [B] + [Disp+[X]] + C` | Adds the contents of Accumulator B, memory at `Disp + [X]`, and the Carry bit C, storing the result in Accumulator B. |
| ADC | `B addr16` | EXT | 3 | `F9 MH ML` | 4 | x | x | x | x | x | - | `[B] ← [B] + [addr16] + C` | Adds the contents of Accumulator B, memory at `addr16`, and the Carry bit C, storing the result in Accumulator B. |
| ADD | `A #data8` | IMM | 2 | `8B data8` | 2 | x | x | x | x | x | - | `[A] ← [A] + data8` | **Add without Carry.** Adds immediate data to Accumulator A, storing the result in Accumulator A. |
| ADD | `A addr8` | DIR | 2 | `9B addr8` | 3 | x | x | x | x | x | - | `[A] ← [A] + [addr8]` | Adds contents of memory at `addr8` to Accumulator A, storing the result in Accumulator A. |
| ADD | `A Disp,X` | IDX | 2 | `AB Disp`  | 4 | x | x | x | x | x | - | `[A] ← [A] + [Disp+[X]]` | Adds contents of memory at `Disp + [X]` to Accumulator A, storing the result in Accumulator A. |
| ADD | `A addr16` | EXT | 3 | `BB MH ML` | 4 | x | x | x | x | x | - | `[A] ← [A] + [addr16]` | Adds contents of memory at `addr16` to Accumulator A, storing the result in Accumulator A. |
| ADD | `B #data8` | IMM | 2 | `CB data8` | 2 | x | x | x | x | x | - | `[B] ← [B] + data8` | Adds immediate data to Accumulator B, storing the result in Accumulator B. |
| ADD | `B addr8` | DIR | 2 | `DB addr8` | 3 | x | x | x | x | x | - | `[B] ← [B] + [addr8]` | Adds contents of memory at `addr8` to Accumulator B, storing the result in Accumulator B. |
| ADD | `B Disp,X` | IDX | 2 | `EB Disp`  | 4 | x | x | x | x | x | - | `[B] ← [B] + [Disp+[X]]` | Adds contents of memory at `Disp + [X]` to Accumulator B, storing the result in Accumulator B. |
| ADD | `B addr16` | EXT | 3 | `FB MH ML` | 4 | x | x | x | x | x | - | `[B] ← [B] + [addr16]` | Adds contents of memory at `addr16` to Accumulator B, storing the result in Accumulator B. |
| ADDD  | `#data16` | IMM | 3 | `C3 ImmH ImmL` | 3 | x | x | x | x | - | - | `[ACCD] ← [ACCD] + data16` | **Double Add without Carry.** (HD6301/HD6303 Enhancement) Adds 16-bit immediate data to the Double Accumulator (ACCD), storing the result in ACCD. |
| ADDD  | `addr8` | DIR | 2 | `D3 addr8` | 4 | x | x | x | x | - | - | `[ACCD] ← [ACCD] + [addr8:addr8+1]` | (HD6301/HD6303 Enhancement) Adds contents of memory at `addr8` and `addr8+1` (16-bit) to ACCD, storing the result in ACCD. |
| ADDD  | `Disp,X` | IDX | 2 | `E3 Disp`  | 5 | x | x | x | x | - | - | `[ACCD] ← [ACCD] + [Disp+[X]:Disp+[X]+1]` | (HD6301/HD6303 Enhancement) Adds contents of memory (16-bit) addressed by `Disp + [X]` to ACCD, storing the result in ACCD. |
| ADDD  | `addr16` | EXT | 3 | `F3 MH ML` | 5 | x | x | x | x | - | - | `[ACCD] ← [ACCD] + [addr16:addr16+1]` | (HD6301/HD6303 Enhancement) Adds contents of memory (16-bit) at `addr16` to ACCD, storing the result in ACCD. |
| AIM | `data8, addr8` | DIR | 3 | `71 data8 addr8` | 6 | - | x | x | 0 | - | - | `[addr8] ← data8 ∧ [addr8]` | **And Immediate.** (HD6301/HD6303 Enhancement) Performs a logical AND operation between immediate data and the contents of a memory location, storing the result in the memory location. |
| AIM | `data8, Disp,X`  | IDX | 3 | `61 data8 Disp` | 7 | - | x | x | 0 | - | - | `[Disp+[X]] ← data8 ∧ [Disp+[X]]` | (HD6301/HD6303 Enhancement) Performs a logical AND operation between immediate data and the contents of a memory location addressed by `Disp + [X]`, storing the result in the memory location. |
| AND | `A #data8` | IMM | 2 | `84 data8` | 2 | - | x | x | 0 | - | - | `[A] ← [A] ∧ data8` | **Logical AND.** Performs a logical AND operation between Accumulator A and immediate data, storing the result in Accumulator A. |
| AND | `A addr8` | DIR | 2 | `94 addr8` | 3 | - | x | x | 0 | - | - | `[A] ← [A] ∧ [addr8]` | Performs a logical AND operation between Accumulator A and the contents of memory at `addr8`, storing the result in Accumulator A. |
| AND | `A Disp,X` | IDX | 2 | `A4 Disp`  | 4 | - | x | x | 0 | - | - | `[A] ← [A] ∧ [Disp+[X]]` | Performs a logical AND operation between Accumulator A and the contents of memory at `Disp + [X]`, storing the result in Accumulator A. |
| AND | `A addr16` | EXT | 3 | `B4 MH ML` | 4 | - | x | x | 0 | - | - | `[A] ← [A] ∧ [addr16]` | Performs a logical AND operation between Accumulator A and the contents of memory at `addr16`, storing the result in Accumulator A. |
| AND | `B #data8` | IMM | 2 | `C4 data8` | 2 | - | x | x | 0 | - | - | `[B] ← [B] ∧ data8` | Performs a logical AND operation between Accumulator B and immediate data, storing the result in Accumulator B. |
| AND | `B addr8` | DIR | 2 | `D4 addr8` | 3 | - | x | x | 0 | - | - | `[B] ← [B] ∧ [addr8]` | Performs a logical AND operation between Accumulator B and the contents of memory at `addr8`, storing the result in Accumulator B. |
| AND | `B Disp,X` | IDX | 2 | `E4 Disp`  | 4 | - | x | x | 0 | - | - | `[B] ← [B] ∧ [Disp+[X]]` | Performs a logical AND operation between Accumulator B and the contents of memory at `Disp + [X]`, storing the result in Accumulator B. |
| AND | `B addr16` | EXT | 3 | `F4 MH ML` | 4 | - | x | x | 0 | - | - | `[B] ← [B] ∧ [addr16]` | Performs a logical AND operation between Accumulator B and the contents of memory at `addr16`, storing the result in Accumulator B. |
| ASL | `A` | ACC | 1 | `48` | 1 | x | x | x | x | - | - | `C ← [A7]; [A] ← [A] << 1; A0 ← 0` | **Arithmetic Shift Left.** Shifts Accumulator A one bit left. Bit 0 becomes 0, and Bit 7 moves into the Carry bit C. |
| ASL | `B` | ACC | 1 | `58` | 1 | x | x | x | x | - | - | `C ← [B7]; [B] ← [B] << 1; B0 ← 0` | Shifts Accumulator B one bit left. Bit 0 becomes 0, and Bit 7 moves into the Carry bit C. |
| ASL | `Disp,X` | IDX | 2 | `68 Disp`  | 6 | x | x | x | x | - | - | `C ← [M7]; [M] ← [M] << 1; M0 ← 0` | Shifts memory at `Disp + [X]` one bit left. Bit 0 becomes 0, and Bit 7 moves into the Carry bit C. |
| ASL | `addr16` | EXT | 3 | `78 MH ML` | 6 | x | x | x | x | - | - | `C ← [M7]; [M] ← [M] << 1; M0 ← 0` | Shifts memory at `addr16` one bit left. Bit 0 becomes 0, and Bit 7 moves into the Carry bit C. |
| ASLD  | `ASLD` | INH | 1 | `05` | 1 | x | x | x | x | - | - | `C ← [D15]; [ACCD] ← [ACCD] << 1; D0 ← 0` | **Arithmetic Double Shift Left.** (HD6301/HD6303 Enhancement) Shifts the Double Accumulator (ACCD) one bit left. Bit 0 becomes 0, and Bit 15 moves into the Carry bit C. |
| ASR | `A` | ACC | 1 | `47` | 1 | x | x | x | x | - | - | `C ← [A0]; A7 stays; [A] ← [A] >> 1` | **Arithmetic Shift Right.** Shifts Accumulator A one bit right. Bit 7 is unchanged, and Bit 0 moves into the Carry bit C. |
| ASR | `B` | ACC | 1 | `57` | 1 | x | x | x | x | - | - | `C ← [B0]; B7 stays; [B] ← [B] >> 1` | Shifts Accumulator B one bit right. Bit 7 is unchanged, and Bit 0 moves into the Carry bit C. |
| ASR | `Disp,X` | IDX | 2 | `67 Disp`  | 6 | x | x | x | x | - | - | `C ← [M0]; M7 stays; [M] ← [M] >> 1` | Shifts memory at `Disp + [X]` one bit right. Bit 7 is unchanged, and Bit 0 moves into the Carry bit C. |
| ASR | `addr16` | EXT | 3 | `77 MH ML` | 6 | x | x | x | x | - | - | `C ← [M0]; M7 stays; [M] ← [M] >> 1` | Shifts memory at `addr16` one bit right. Bit 7 is unchanged, and Bit 0 moves into the Carry bit C. |
| BCC | `Rel` | REL | 2 | `24 Rel` | 3/4 | - | - | - | - | - | - | `(C == 0) ? [PC] ← [PC] + Rel + 2` | **Branch if Carry Clear.** Branches if the Carry bit C is 0. (4 cycles if branch taken, 3 if not; this is a common characteristic for branches not explicitly stated for all, but typically implied). |
| BCLR  | `bit_no, addr8`  | DIR | 3 | `71 mask`  | 6 | - | x | x | 0 | - | - | `Mi ← 0` | **Bit Clear.** (HD6301/HD6303 Enhancement) Clears a specific bit (`Mi`, where `i` is `bit_no` from 0 to 7) within a memory location `addr8`. The `mask` value in the second byte is determined by `bit_no` (see Bit Mask table). |
| BCLR  | `bit_no, Disp,X` | IDX | 3 | `61 mask`  | 7 | - | x | x | 0 | - | - | `Mi ← 0` | (HD6301/HD6303 Enhancement) Clears a specific bit (`Mi`, where `i` is `bit_no` from 0 to 7) within a memory location addressed by `Disp + [X]`. The `mask` value in the second byte is determined by `bit_no` (see Bit Mask table). |
| BCS | `Rel` | REL | 2 | `25 Rel` | 3/4 | - | - | - | - | - | - | `(C == 1) ? [PC] ← [PC] + Rel + 2` | **Branch if Carry Set.** Branches if the Carry bit C is 1. |
| BEQ | `Rel` | REL | 2 | `27 Rel` | 3/4 | - | - | - | - | - | - | `(Z == 1) ? [PC] ← [PC] + Rel + 2` | **Branch if Equal.** Branches if the Zero bit Z is 1. |
| BGE | `Rel` | REL | 2 | `2C Rel` | 3/4 | - | - | - | - | - | - | `(S ⊻ O == 0) ? [PC] ← [PC] + Rel + 2` | **Branch if Greater than or Equal to Zero.** Branches if N=V (no overflow or sign change) after a signed comparison, meaning the minuend is greater than or equal to the subtracter. |
| BGT | `Rel` | REL | 2 | `2E Rel` | 3/4 | - | - | - | - | - | - | `(Z ∨ (S ⊻ O) == 0) ? [PC] ← [PC] + Rel + 2` | **Branch if Greater Than Zero.** Branches if Z=0 and N=V (not zero and no overflow or sign change) after a signed comparison, meaning the minuend is strictly greater than the subtracter. |
| BHI | `Rel` | REL | 2 | `22 Rel` | 3/4 | - | - | - | - | - | - | `(C ∨ Z == 0) ? [PC] ← [PC] + Rel + 2` | **Branch if Higher.** Branches if C=0 and Z=0 (no carry and not zero) after an unsigned comparison, meaning the minuend is strictly greater than the subtracter. |
| BIT | `A #data8` | IMM | 2 | `85 data8` | 2 | - | x | x | 0 | - | - | `[A] ∧ data8` | **Bit Test.** Performs a logical AND operation between Accumulator A and immediate data, affecting only the Condition Code Register. The operands remain unchanged. |
| BIT | `A addr8` | DIR | 2 | `95 addr8` | 3 | - | x | x | 0 | - | - | `[A] ∧ [addr8]` | Performs a logical AND operation between Accumulator A and the contents of memory at `addr8`, affecting only the Condition Code Register. The operands remain unchanged. |
| BIT | `A Disp,X` | IDX | 2 | `A5 Disp`  | 4 | - | x | x | 0 | - | - | `[A] ∧ [Disp+[X]]` | Performs a logical AND operation between Accumulator A and the contents of memory at `Disp + [X]`, affecting only the Condition Code Register. The operands remain unchanged. |
| BIT | `A addr16` | EXT | 3 | `B5 MH ML` | 4 | - | x | x | 0 | - | - | `[A] ∧ [addr16]` | Performs a logical AND operation between Accumulator A and the contents of memory at `addr16`, affecting only the Condition Code Register. The operands remain unchanged. |
| BIT | `B #data8` | IMM | 2 | `C5 data8` | 2 | - | x | x | 0 | - | - | `[B] ∧ data8` | Performs a logical AND operation between Accumulator B and immediate data, affecting only the Condition Code Register. The operands remain unchanged. |
| BIT | `B addr8` | DIR | 2 | `D5 addr8` | 3 | - | x | x | 0 | - | - | `[B] ∧ [addr8]` | Performs a logical AND operation between Accumulator B and the contents of memory at `addr8`, affecting only the Condition Code Register. The operands remain unchanged. |
| BIT | `B Disp,X` | IDX | 2 | `E5 Disp`  | 4 | - | x | x | 0 | - | - | `[B] ∧ [Disp+[X]]` | Performs a logical AND operation between Accumulator B and the contents of memory at `Disp + [X]`, affecting only the Condition Code Register. The operands remain unchanged. |
| BIT | `B addr16` | EXT | 3 | `F5 MH ML` | 4 | - | x | x | 0 | - | - | `[B] ∧ [addr16]` | Performs a logical AND operation between Accumulator B and the contents of memory at `addr16`, affecting only the Condition Code Register. The operands remain unchanged. |
| BLE | `Rel` | REL | 2 | `2F Rel` | 3/4 | - | - | - | - | - | - | `(Z ∨ (S ⊻ O) == 1) ? [PC] ← [PC] + Rel + 2` | **Branch if Less than or Equal to Zero.** Branches if Z=1 or N≠V (zero or overflow/sign change) after a signed comparison, meaning the minuend is less than or equal to the subtracter. |
| BLS | `Rel` | REL | 2 | `23 Rel` | 3/4 | - | - | - | - | - | - | `(C ∨ Z == 1) ? [PC] ← [PC] + Rel + 2` | **Branch if Lower or Same.** Branches if C=1 or Z=1 (carry or zero) after an unsigned comparison, meaning the minuend is less than or equal to the subtracter. |
| BLT | `Rel` | REL | 2 | `2D Rel` | 3/4 | - | - | - | - | - | - | `(S ⊻ O == 1) ? [PC] ← [PC] + Rel + 2` | **Branch if Less Than Zero.** Branches if N≠V (overflow or sign change) after a signed comparison, meaning the minuend is strictly less than the subtracter. |
| BMI | `Rel` | REL | 2 | `2B Rel` | 3/4 | - | - | - | - | - | - | `(S == 1) ? [PC] ← [PC] + Rel + 2` | **Branch if Minus.** Branches if the Sign (Negative) bit S is 1. |
| BNE | `Rel` | REL | 2 | `26 Rel` | 3/4 | - | - | - | - | - | - | `(Z == 0) ? [PC] ← [PC] + Rel + 2` | **Branch if Not Equal.** Branches if the Zero bit Z is 0. |
| BPL | `Rel` | REL | 2 | `2A Rel` | 3/4 | - | - | - | - | - | - | `(S == 0) ? [PC] ← [PC] + Rel + 2` | **Branch if Plus.** Branches if the Sign (Negative) bit S is 0. |
| BRA | `Rel` | REL | 2 | `20 Rel` | 3 | - | - | - | - | - | - | `[PC] ← [PC] + Rel + 2` | **Branch Always.** Unconditional branch to an address relative to the present Program Counter contents. |
| BRN | `Rel` | REL | 2 | `21 Rel` | 3 | - | - | - | - | - | - | `[PC] ← [PC] + 2` | **Branch Never.** (HD6301/HD6303 Enhancement) A two-byte, three-cycle instruction equivalent to NOP. It provides a function opposite to BRA. The second byte is arbitrary. |
| BSET  | `bit_no, addr8`  | DIR | 3 | `72 mask`  | 6 | - | x | x | 0 | - | - | `Mi ← 1` | **Bit Set.** (HD6301/HD6303 Enhancement) Sets a specific bit (`Mi`, where `i` is `bit_no` from 0 to 7) within a memory location `addr8`. The `mask` value in the second byte is determined by `bit_no` (see Bit Mask table). |
| BSET  | `bit_no, Disp,X` | IDX | 3 | `62 mask`  | 7 | - | x | x | 0 | - | - | `Mi ← 1` | (HD6301/HD6303 Enhancement) Sets a specific bit (`Mi`, where `i` is `bit_no` from 0 to 7) within a memory location addressed by `Disp + [X]`. The `mask` value in the second byte is determined by `bit_no` (see Bit Mask table). |
| BSR | `Rel` | REL | 2 | `8D Rel` | 5 | - | - | - | - | - | - | `[[SP]] ← [PC(LO)]; [[SP]-1] ← [PC(HI)]; [SP] ← [SP]-2; [PC] ← [PC] + Rel + 2` | **Branch to Subroutine.** Increments PC, saves the return address (PC) onto the stack, decrements SP, and branches to the subroutine located relative to the present Program Counter contents. Cycle count from. (Note: The symbolic operation in source shows SP decrementing by 2 after both bytes are pushed, source lists three decrements which logically means SP is decremented after each byte push). |
| BTGL  | `bit_no, addr8`  | DIR | 3 | `75 mask`  | 6 | - | x | x | 0 | - | - | `Mi ← ¬Mi` | **Bit Toggle.** (HD6301/HD6303 Enhancement) Inverts a specific bit (`Mi`, where `i` is `bit_no` from 0 to 7) within a memory location `addr8`. The `mask` value in the second byte is determined by `bit_no` (see Bit Mask table). |
| BTGL  | `bit_no, Disp,X` | IDX | 3 | `65 mask`  | 7 | - | x | x | 0 | - | - | `Mi ← ¬Mi` | (HD6301/HD6303 Enhancement) Inverts a specific bit (`Mi`, where `i` is `bit_no` from 0 to 7) within a memory location addressed by `Disp + [X]`. The `mask` value in the second byte is determined by `bit_no` (see Bit Mask table). |
| BTST  | `bit_no, addr8`  | DIR | 3 | `7B mask`  | 4 | - | x | x | 0 | - | - | `Mi ∧ 1` | **Bit Test.** (HD6301/HD6303 Enhancement) Performs a logical AND operation between a specific bit (`Mi`, where `i` is `bit_no` from 0 to 7) of a memory location `addr8` and the value "1", affecting only the Condition Code Register. The memory contents remain unchanged. The `mask` value in the second byte is determined by `bit_no` (see Bit Mask table). |
| BTST  | `bit_no, Disp,X` | IDX | 3 | `6B mask`  | 5 | - | x | x | 0 | - | - | `Mi ∧ 1` | (HD6301/HD6303 Enhancement) Performs a logical AND operation between a specific bit (`Mi`, where `i` is `bit_no` from 0 to 7) of a memory location addressed by `Disp + [X]` and the value "1", affecting only the Condition Code Register. The memory contents remain unchanged. The `mask` value in the second byte is determined by `bit_no` (see Bit Mask table). |
| BVC | `Rel` | REL | 2 | `28 Rel` | 3/4 | - | - | - | 0 | - | - | `(O == 0) ? [PC] ← [PC] + Rel + 2` | **Branch if Overflow Clear.** Branches if the Overflow bit O is 0. |
| BVS | `Rel` | REL | 2 | `29 Rel` | 3/4 | - | - | - | 1 | - | - | `(O == 1) ? [PC] ← [PC] + Rel + 2` | **Branch if Overflow Set.** Branches if the Overflow bit O is 1. |
| CBA | `CBA` | INH | 1 | `11` | 1 | x | x | x | x | - | - | `[A] - [B]` | **Compare Accumulators.** Compares the contents of Accumulator A to Accumulator B, setting condition codes. Neither accumulator is affected. |
| CLC | `CLC` | INH | 1 | `0C` | 1 | 0 | - | - | - | - | - | `C ← 0` | **Clear Carry.** Clears the Carry bit C. |
| CLI | `CLI` | INH | 1 | `0E` | 1 | - | - | - | - | - | 0 | `I ← 0` | **Clear Interrupt Mask.** Clears the Interrupt Mask bit I in the CCR, enabling maskable interrupts. |
| CLR | `A` | ACC | 1 | `4F` | 1 | 0 | 1 | 0 | 0 | - | - | `[A] ← 0` | **Clear.** Clears the contents of Accumulator A to zero. |
| CLR | `B` | ACC | 1 | `5F` | 1 | 0 | 1 | 0 | 0 | - | - | `[B] ← 0` | Clears the contents of Accumulator B to zero. |
| CLR | `Disp,X` | IDX | 2 | `6F Disp`  | 5 | 0 | 1 | 0 | 0 | - | - | `[Disp+[X]] ← 0` | Clears the contents of the memory location addressed by `Disp + [X]` to zero. |
| CLR | `addr16` | EXT | 3 | `7F MH ML` | 5 | 0 | 1 | 0 | 0 | - | - | `[addr16] ← 0` | Clears the contents of the memory location at `addr16` to zero. |
| CLV | `CLV` | INH | 1 | `0A` | 1 | - | - | - | 0 | - | - | `O ← 0` | **Clear Overflow.** Clears the Overflow bit O in the CCR. |
| CMP | `A #data8` | IMM | 2 | `81 data8` | 2 | x | x | x | x | - | - | `[A] - data8` | **Compare.** Compares Accumulator A with immediate data, setting condition codes. Neither operand is affected. |
| CMP | `A addr8` | DIR | 2 | `91 addr8` | 3 | x | x | x | x | - | - | `[A] - [addr8]` | Compares Accumulator A with the contents of memory at `addr8`, setting condition codes. Neither operand is affected. |
| CMP | `A Disp,X` | IDX | 2 | `A1 Disp`  | 4 | x | x | x | x | - | - | `[A] - [Disp+[X]]` | Compares Accumulator A with the contents of memory at `Disp + [X]`, setting condition codes. Neither operand is affected. |
| CMP | `A addr16` | EXT | 3 | `B1 MH ML` | 4 | x | x | x | x | - | - | `[A] - [addr16]` | Compares Accumulator A with the contents of memory at `addr16`, setting condition codes. Neither operand is affected. |
| CMP | `B #data8` | IMM | 2 | `C1 data8` | 2 | x | x | x | x | - | - | `[B] - data8` | Compares Accumulator B with immediate data, setting condition codes. Neither operand is affected. |
| CMP | `B addr8` | DIR | 2 | `D1 addr8` | 3 | x | x | x | x | - | - | `[B] - [addr8]` | Compares Accumulator B with the contents of memory at `addr8`, setting condition codes. Neither operand is affected. |
| CMP | `B Disp,X` | IDX | 2 | `E1 Disp`  | 4 | x | x | x | x | - | - | `[B] - [Disp+[X]]` | Compares Accumulator B with the contents of memory at `Disp + [X]`, setting condition codes. Neither operand is affected. |
| CMP | `B addr16` | EXT | 3 | `F1 MH ML` | 4 | x | x | x | x | - | - | `[B] - [addr16]` | Compares Accumulator B with the contents of memory at `addr16`, setting condition codes. Neither operand is affected. |
| COM | `A` | ACC | 1 | `43` | 1 | 1 | x | x | 0 | - | - | `[A] ← ¬[A]` | **Complement.** Takes the one's complement of each bit in Accumulator A. |
| COM | `B` | ACC | 1 | `53` | 1 | 1 | x | x | 0 | - | - | `[B] ← ¬[B]` | Takes the one's complement of each bit in Accumulator B. |
| COM | `Disp,X` | IDX | 2 | `63 Disp`  | 6 | 1 | x | x | 0 | - | - | `[Disp+[X]] ← ¬[Disp+[X]]` | Takes the one's complement of each bit in the memory location addressed by `Disp + [X]`. |
| COM | `addr16` | EXT | 3 | `73 MH ML` | 6 | 1 | x | x | 0 | - | - | `[addr16] ← ¬[addr16]` | Takes the one's complement of each bit in the memory location at `addr16`. |
| CPX | `#data16` | IMM | 3 | `8C ImmH ImmL` | 3 | x | x | x | x | - | - | `[X] - data16` | **Compare Index Register.** Compares the 16-bit Index Register with 16-bit immediate data, setting condition codes. Index Register is not affected. (Note: `CPX #data16` is used for 16-bit immediate data, not `CPX #data8` as per). |
| CPX | `addr8` | DIR | 2 | `9C addr8` | 4 | x | x | x | x | - | - | `[X] - [addr8:addr8+1]` | Compares the 16-bit Index Register with the 16-bit contents of memory at `addr8` and `addr8+1`, setting condition codes. Index Register is not affected. |
| CPX | `Disp,X` | IDX | 2 | `AC Disp`  | 5 | x | x | x | x | - | - | `[X] - [Disp+[X]:Disp+[X]+1]` | Compares the 16-bit Index Register with the 16-bit contents of memory addressed by `Disp + [X]`, setting condition codes. Index Register is not affected. |
| CPX | `addr16` | EXT | 3 | `BC MH ML` | 5 | x | x | x | x | - | - | `[X] - [addr16:addr16+1]`  | Compares the 16-bit Index Register with the 16-bit contents of memory at `addr16` and `addr16+1`, setting condition codes. Index Register is not affected. |
| DAA | `DAA` | INH | 1 | `19` | 2 | x | x | x | - | - | - | `[A] ← Decimal Adjust` | **Decimal Adjust Accumulator A.** Adjusts the contents of Accumulator A for BCD (Binary Coded Decimal) arithmetic after an addition operation. |
| DEC | `A` | ACC | 1 | `4A` | 1 | - | x | x | x | - | - | `[A] ← [A] - 1` | **Decrement.** Subtracts 1 from the contents of Accumulator A. |
| DEC | `B` | ACC | 1 | `5A` | 1 | - | x | x | x | - | - | `[B] ← [B] - 1` | Subtracts 1 from the contents of Accumulator B. |
| DEC | `Disp,X` | IDX | 2 | `6A Disp`  | 6 | - | x | x | x | - | - | `[Disp+[X]] ← [Disp+[X]] - 1` | Subtracts 1 from the contents of the memory location addressed by `Disp + [X]`. |
| DEC | `addr16` | EXT | 3 | `7A MH ML` | 6 | - | x | x | x | - | - | `[addr16] ← [addr16] - 1`  | Subtracts 1 from the contents of the memory location at `addr16`. |
| DES | `DES` | INH | 1 | `34` | 1 | - | - | - | - | - | - | `[SP] ← [SP] - 1` | **Decrement Stack Pointer.** Subtracts 1 from the Stack Pointer. |
| DEX | `DEX` | INH | 1 | `09` | 1 | - | x | - | - | - | - | `[X] ← [X] - 1` | **Decrement Index Register.** Subtracts 1 from the Index Register X. |
| EIM | `data8, addr8` | DIR | 3 | `75 data8 addr8` | 6 | - | x | x | 0 | - | - | `[addr8] ← data8 ⊻ [addr8]` | **Exclusive-OR Immediate.** (HD6301/HD6303 Enhancement) Performs a logical Exclusive-OR operation between immediate data and the contents of a memory location, storing the result in the memory location. |
| EIM | `data8, Disp,X`  | IDX | 3 | `65 data8 Disp` | 7 | - | x | x | 0 | - | - | `[Disp+[X]] ← data8 ⊻ [Disp+[X]]` | (HD6301/HD6303 Enhancement) Performs a logical Exclusive-OR operation between immediate data and the contents of a memory location addressed by `Disp + [X]`, storing the result in the memory location. |
| EOR | `A #data8` | IMM | 2 | `88 data8` | 2 | - | x | x | 0 | - | - | `[A] ← [A] ⊻ data8` | **Exclusive OR.** Performs a logical Exclusive-OR operation between Accumulator A and immediate data, storing the result in Accumulator A. |
| EOR | `A addr8` | DIR | 2 | `98 addr8` | 3 | - | x | x | 0 | - | - | `[A] ← [A] ⊻ [addr8]` | Performs a logical Exclusive-OR operation between Accumulator A and the contents of memory at `addr8`, storing the result in Accumulator A. |
| EOR | `A Disp,X` | IDX | 2 | `A8 Disp`  | 4 | - | x | x | 0 | - | - | `[A] ← [A] ⊻ [Disp+[X]]` | Performs a logical Exclusive-OR operation between Accumulator A and the contents of memory at `Disp + [X]`, storing the result in Accumulator A. |
| EOR | `A addr16` | EXT | 3 | `B8 MH ML` | 4 | - | x | x | 0 | - | - | `[A] ← [A] ⊻ [addr16]` | Performs a logical Exclusive-OR operation between Accumulator A and the contents of memory at `addr16`, storing the result in Accumulator A. |
| EOR | `B #data8` | IMM | 2 | `C8 data8` | 2 | - | x | x | 0 | - | - | `[B] ← [B] ⊻ data8` | Performs a logical Exclusive-OR operation between Accumulator B and immediate data, storing the result in Accumulator B. |
| EOR | `B addr8` | DIR | 2 | `D8 addr8` | 3 | - | x | x | 0 | - | - | `[B] ← [B] ⊻ [addr8]` | Performs a logical Exclusive-OR operation between Accumulator B and the contents of memory at `addr8`, storing the result in Accumulator B. |
| EOR | `B Disp,X` | IDX | 2 | `E8 Disp`  | 4 | - | x | x | 0 | - | - | `[B] ← [B] ⊻ [Disp+[X]]` | Performs a logical Exclusive-OR operation between Accumulator B and the contents of memory at `Disp + [X]`, storing the result in Accumulator B. |
| EOR | `B addr16` | EXT | 3 | `F8 MH ML` | 4 | - | x | x | 0 | - | - | `[B] ← [B] ⊻ [addr16]` | Performs a logical Exclusive-OR operation between Accumulator B and the contents of memory at `addr16`, storing the result in Accumulator B. |
| INC | `A` | ACC | 1 | `4C` | 1 | - | x | x | x | - | - | `[A] ← [A] + 1` | **Increment.** Adds 1 to the contents of Accumulator A. |
| INC | `B` | ACC | 1 | `5C` | 1 | - | x | x | x | - | - | `[B] ← [B] + 1` | Adds 1 to the contents of Accumulator B. |
| INC | `Disp,X` | IDX | 2 | `6C Disp`  | 6 | - | x | x | x | - | - | `[Disp+[X]] ← [Disp+[X]] + 1` | Adds 1 to the contents of the memory location addressed by `Disp + [X]`. |
| INC | `addr16` | EXT | 3 | `7C MH ML` | 6 | - | x | x | x | - | - | `[addr16] ← [addr16] + 1`  | Adds 1 to the contents of the memory location at `addr16`. |
| INS | `INS` | INH | 1 | `31` | 1 | - | - | - | - | - | - | `[SP] ← [SP] + 1` | **Increment Stack Pointer.** Adds 1 to the Stack Pointer. |
| INX | `INX` | INH | 1 | `08` | 1 | - | x | - | - | - | - | `[X] ← [X] + 1` | **Increment Index Register.** Adds 1 to the Index Register X. |
| JMP | `Disp,X` | IDX | 2 | `6E Disp`  | 3 | - | - | - | - | - | - | `[PC] ← Disp + [X]` | **Jump.** Branches to the instruction at the address specified by `Disp + [X]`. |
| JMP | `addr16` | EXT | 3 | `7E MH ML` | 3 | - | - | - | - | - | - | `[PC] ← addr16` | Branches to the instruction at the absolute address `addr16`. |
| JSR | `Disp,X` | IDX | 2 | `AD Disp`  | 5 | - | - | - | - | - | - | `[[SP]] ← [PC(LO)]; [[SP]-1] ← [PC(HI)]; [SP] ← [SP]-2; [PC] ← Disp + [X]` | **Jump to Subroutine.** Increments PC, saves the return address onto the stack, decrements SP, and branches to the subroutine located by `Disp + [X]`. |
| JSR | `addr16` | EXT | 3 | `BD MH ML` | 6 | - | - | - | - | - | - | `[[SP]] ← [PC(LO)]; [[SP]-1] ← [PC(HI)]; [SP] ← [SP]-2; [PC] ← addr16` | Increments PC, saves the return address onto the stack, decrements SP, and branches to the subroutine located at `addr16`. |
| JSR | `addr8` | DIR | 2 | `9D addr8` | 5 | - | - | - | - | - | - | `[[SP]] ← [PC(LO)]; [[SP]-1] ← [PC(HI)]; [SP] ← [SP]-2; [PC] ← addr8` | Increments PC, saves the return address onto the stack, decrements SP, and branches to the subroutine located at `addr8`. This is specific to HD6301/HD6303 as the original 6800 doesn't have JSR Direct. |
| LDA | `A #data8` | IMM | 2 | `86 data8` | 2 | - | x | x | 0 | - | - | `[A] ← data8` | **Load Accumulator.** Loads 8-bit immediate data into Accumulator A. |
| LDA | `A addr8` | DIR | 2 | `96 addr8` | 3 | - | x | x | 0 | - | - | `[A] ← [addr8]` | Loads the contents of memory at `addr8` into Accumulator A. |
| LDA | `A Disp,X` | IDX | 2 | `A6 Disp`  | 4 | - | x | x | 0 | - | - | `[A] ← [Disp+[X]]` | Loads the contents of memory addressed by `Disp + [X]` into Accumulator A. |
| LDA | `A addr16` | EXT | 3 | `B6 MH ML` | 4 | - | x | x | 0 | - | - | `[A] ← [addr16]` | Loads the contents of memory at `addr16` into Accumulator A. |
| LDA | `B #data8` | IMM | 2 | `C6 data8` | 2 | - | x | x | 0 | - | - | `[B] ← data8` | Loads 8-bit immediate data into Accumulator B. |
| LDA | `B addr8` | DIR | 2 | `D6 addr8` | 3 | - | x | x | 0 | - | - | `[B] ← [addr8]` | Loads the contents of memory at `addr8` into Accumulator B. |
| LDA | `B Disp,X` | IDX | 2 | `E6 Disp`  | 4 | - | x | x | 0 | - | - | `[B] ← [Disp+[X]]` | Loads the contents of memory addressed by `Disp + [X]` into Accumulator B. |
| LDA | `B addr16` | EXT | 3 | `F6 MH ML` | 4 | - | x | x | 0 | - | - | `[B] ← [addr16]` | Loads the contents of memory at `addr16` into Accumulator B. |
| LDD | `#data16` | IMM | 3 | `CC ImmH ImmL` | 3 | - | x | x | 0 | - | - | `[ACCD] ← data16` | **Double Load Accumulator A:B.** (HD6301/HD6303 Enhancement) Loads 16-bit immediate data into the Double Accumulator (ACCD). |
| LDD | `addr8` | DIR | 2 | `DC addr8` | 4 | - | x | x | 0 | - | - | `[ACCD] ← [addr8:addr8+1]` | (HD6301/HD6303 Enhancement) Loads the 16-bit contents of memory at `addr8` and `addr8+1` into ACCD. |
| LDD | `Disp,X` | IDX | 2 | `EC Disp`  | 5 | - | x | x | 0 | - | - | `[ACCD] ← [Disp+[X]:Disp+[X]+1]` | (HD6301/HD6303 Enhancement) Loads the 16-bit contents of memory addressed by `Disp + [X]` into ACCD. |
| LDD | `addr16` | EXT | 3 | `FC MH ML` | 5 | - | x | x | 0 | - | - | `[ACCD] ← [addr16:addr16+1]` | (HD6301/HD6303 Enhancement) Loads the 16-bit contents of memory at `addr16` and `addr16+1` into ACCD. |
| LDS | `#data16` | IMM | 3 | `8E ImmH ImmL` | 3 | - | x | x | 0 | - | - | `[SP] ← data16` | **Load Stack Pointer.** Loads 16-bit immediate data into the Stack Pointer. |
| LDS | `addr8` | DIR | 2 | `9E addr8` | 4 | - | x | x | 0 | - | - | `[SP] ← [addr8:addr8+1]` | Loads the 16-bit contents of memory at `addr8` and `addr8+1` into the Stack Pointer. |
| LDS | `Disp,X` | IDX | 2 | `AE Disp`  | 5 | - | x | x | 0 | - | - | `[SP] ← [Disp+[X]:Disp+[X]+1]` | Loads the 16-bit contents of memory addressed by `Disp + [X]` into the Stack Pointer. |
| LDS | `addr16` | EXT | 3 | `BE MH ML` | 5 | - | x | x | 0 | - | - | `[SP] ← [addr16:addr16+1]` | Loads the 16-bit contents of memory at `addr16` and `addr16+1` into the Stack Pointer. |
| LDX | `#data16` | IMM | 3 | `CE ImmH ImmL` | 3 | - | x | x | 0 | - | - | `[X] ← data16` | **Load Index Register.** Loads 16-bit immediate data into the Index Register. |
| LDX | `addr8` | DIR | 2 | `DE addr8` | 4 | - | x | x | 0 | - | - | `[X] ← [addr8:addr8+1]` | Loads the 16-bit contents of memory at `addr8` and `addr8+1` into the Index Register. |
| LDX | `Disp,X` | IDX | 2 | `EE Disp`  | 5 | - | x | x | 0 | - | - | `[X] ← [Disp+[X]:Disp+[X]+1]` | Loads the 16-bit contents of memory addressed by `Disp + [X]` into the Index Register. |
| LDX | `addr16` | EXT | 3 | `FE MH ML` | 5 | - | x | x | 0 | - | - | `[X] ← [addr16:addr16+1]`  | Loads the 16-bit contents of memory at `addr16` and `addr16+1` into the Index Register. |
| LSR | `A` | ACC | 1 | `44` | 1 | x | x | 0 | x | - | - | `C ← [A0]; A7 ← 0; [A] ← [A] >> 1` | **Logical Shift Right.** Shifts Accumulator A one bit right. Bit 7 becomes 0, and Bit 0 moves into the Carry bit C. |
| LSR | `B` | ACC | 1 | `54` | 1 | x | x | 0 | x | - | - | `C ← [B0]; B7 ← 0; [B] ← [B] >> 1` | Shifts Accumulator B one bit right. Bit 7 becomes 0, and Bit 0 moves into the Carry bit C. |
| LSR | `Disp,X` | IDX | 2 | `64 Disp`  | 6 | x | x | 0 | x | - | - | `C ← [M0]; M7 ← 0; [M] ← [M] >> 1` | Shifts memory at `Disp + [X]` one bit right. Bit 7 becomes 0, and Bit 0 moves into the Carry bit C. |
| LSR | `addr16` | EXT | 3 | `74 MH ML` | 6 | x | x | 0 | x | - | - | `C ← [M0]; M7 ← 0; [M] ← [M] >> 1` | Shifts memory at `addr16` one bit right. Bit 7 becomes 0, and Bit 0 moves into the Carry bit C. |
| LSRD  | `LSRD` | INH | 1 | `04` | 1 | x | x | 0 | x | - | - | `C ← [D0]; D15 ← 0; [ACCD] ← [ACCD] >> 1` | **Logical Double Shift Right A:B.** (HD6301/HD6303 Enhancement) Shifts the Double Accumulator (ACCD) one bit right. Bit 15 becomes 0, and Bit 0 moves into the Carry bit C. |
| MUL | `MUL` | INH | 1 | `3D` | 7 | - | x | x | - | - | - | `[ACCD] ← [A] * [B]` | **Multiply Unsigned.** (HD6301/HD6303 Enhancement) Multiplies the unsigned contents of Accumulator A by Accumulator B, storing the 16-bit result in the Double Accumulator (ACCD). |
| NEG | `A` | ACC | 1 | `40` | 1 | x | x | x | x | - | - | `[A] ← 0 - [A]` | **Negate.** Takes the two's complement of the contents of Accumulator A. |
| NEG | `B` | ACC | 1 | `50` | 1 | x | x | x | x | - | - | `[B] ← 0 - [B]` | Takes the two's complement of the contents of Accumulator B. |
| NEG | `Disp,X` | IDX | 2 | `60 Disp`  | 6 | x | x | x | x | - | - | `[Disp+[X]] ← 0 - [Disp+[X]]` | Takes the two's complement of the contents of the memory location addressed by `Disp + [X]`. |
| NEG | `addr16` | EXT | 3 | `70 MH ML` | 6 | x | x | x | x | - | - | `[addr16] ← 0 - [addr16]`  | Takes the two's complement of the contents of the memory location at `addr16`. |
| NOP | `NOP` | INH | 1 | `01` | 1 | - | - | - | - | - | - | `No Operation` | **No Operation.** Updates the Program Counter only and has no effect on other registers. |
| OIM | `data8, addr8` | DIR | 3 | `72 data8 addr8` | 6 | - | x | x | 0 | - | - | `[addr8] ← data8 ∨ [addr8]` | **Or Immediate.** (HD6301/HD6303 Enhancement) Performs a logical OR operation between immediate data and the contents of a memory location, storing the result in the memory location. |
| OIM | `data8, Disp,X`  | IDX | 3 | `62 data8 Disp` | 7 | - | x | x | 0 | - | - | `[Disp+[X]] ← data8 ∨ [Disp+[X]]` | (HD6301/HD6303 Enhancement) Performs a logical OR operation between immediate data and the contents of a memory location addressed by `Disp + [X]`, storing the result in the memory location. |
| ORA | `A #data8` | IMM | 2 | `8A data8` | 2 | - | x | x | 0 | - | - | `[A] ← [A] ∨ data8` | **Inclusive OR.** Performs a logical OR operation between Accumulator A and immediate data, storing the result in Accumulator A. |
| ORA | `A addr8` | DIR | 2 | `9A addr8` | 3 | - | x | x | 0 | - | - | `[A] ← [A] ∨ [addr8]` | Performs a logical OR operation between Accumulator A and the contents of memory at `addr8`, storing the result in Accumulator A. |
| ORA | `A Disp,X` | IDX | 2 | `AA Disp`  | 4 | - | x | x | 0 | - | - | `[A] ← [A] ∨ [Disp+[X]]` | Performs a logical OR operation between Accumulator A and the contents of memory at `Disp + [X]`, storing the result in Accumulator A. |
| ORA | `A addr16` | EXT | 3 | `BA MH ML` | 4 | - | x | x | 0 | - | - | `[A] ← [A] ∨ [addr16]` | Performs a logical OR operation between Accumulator A and the contents of memory at `addr16`, storing the result in Accumulator A. |
| ORA | `B #data8` | IMM | 2 | `CA data8` | 2 | - | x | x | 0 | - | - | `[B] ← [B] ∨ data8` | Performs a logical OR operation between Accumulator B and immediate data, storing the result in Accumulator B. |
| ORA | `B addr8` | DIR | 2 | `DA addr8` | 3 | - | x | x | 0 | - | - | `[B] ← [B] ∨ [addr8]` | Performs a logical OR operation between Accumulator B and the contents of memory at `addr8`, storing the result in Accumulator B. |
| ORA | `B Disp,X` | IDX | 2 | `EA Disp`  | 4 | - | x | x | 0 | - | - | `[B] ← [B] ∨ [Disp+[X]]` | Performs a logical OR operation between Accumulator B and the contents of memory at `Disp + [X]`, storing the result in Accumulator B. |
| ORA | `B addr16` | EXT | 3 | `FA MH ML` | 4 | - | x | x | 0 | - | - | `[B] ← [B] ∨ [addr16]` | Performs a logical OR operation between Accumulator B and the contents of memory at `addr16`, storing the result in Accumulator B. |
| PSH | `A` | ACC | 1 | `36` | 4 | - | - | - | - | - | - | `[[SP]] ← [A]; [SP] ← [SP] - 1` | **Push Data onto Stack.** Pushes the contents of Accumulator A onto the stack and decrements the Stack Pointer by one. |
| PSH | `B` | ACC | 1 | `37` | 4 | - | - | - | - | - | - | `[[SP]] ← [B]; [SP] ← [SP] - 1` | Pushes the contents of Accumulator B onto the stack and decrements the Stack Pointer by one. |
| PSHX  | `PSHX` | INH | 1 | `3C` | 5 | - | - | - | - | - | - | `[[SP]] ← [IXL]; [[SP]-1] ← [IXH]; [SP] ← [SP] - 2` | **Push Index Register onto Stack.** (HD6301/HD6303 Enhancement) Pushes the 16-bit Index Register onto the stack, decrementing the Stack Pointer by two. |
| PUL | `A` | ACC | 1 | `32` | 3 | - | - | - | - | - | - | `[SP] ← [SP] + 1; [A] ← [[SP]]` | **Pull Data from Stack.** Increments the Stack Pointer by one and pulls data from the stack into Accumulator A. |
| PUL | `B` | ACC | 1 | `33` | 3 | - | - | - | - | - | - | `[SP] ← [SP] + 1; [B] ← [[SP]]` | Increments the Stack Pointer by one and pulls data from the stack into Accumulator B. |
| PULX  | `PULX` | INH | 1 | `38` | 4 | - | - | - | - | - | - | `[SP] ← [SP] + 1; [IXH] ← [[SP]]; [SP] ← [SP] + 1; [IXL] ← [[SP]]` | **Pull Index Register from Stack.** (HD6301/HD6303 Enhancement) Pulls the 16-bit Index Register from the stack, incrementing the Stack Pointer by two in total. |
| ROL | `A` | ACC | 1 | `49` | 1 | x | x | x | x | - | - | `C ← [A7]; [A0] ← C; [A] ← [A] << 1` | **Rotate Left.** Rotates Accumulator A left through the Carry bit C. Bit 0 takes the value of C, and Bit 7 moves into C. |
| ROL | `B` | ACC | 1 | `59` | 1 | x | x | x | x | - | - | `C ← [B7]; [B0] ← C; [B] ← [B] << 1` | Rotates Accumulator B left through the Carry bit C. Bit 0 takes the value of C, and Bit 7 moves into C. |
| ROL | `Disp,X` | IDX | 2 | `69 Disp`  | 6 | x | x | x | x | - | - | `C ← [M7]; [M0] ← C; [M] ← [M] << 1` | Rotates memory at `Disp + [X]` left through the Carry bit C. Bit 0 takes the value of C, and Bit 7 moves into C. |
| ROL | `addr16` | EXT | 3 | `79 MH ML` | 6 | x | x | x | x | - | - | `C ← [M7]; [M0] ← C; [M] ← [M] << 1` | Rotates memory at `addr16` left through the Carry bit C. Bit 0 takes the value of C, and Bit 7 moves into C. |
| ROR | `A` | ACC | 1 | `46` | 1 | x | x | x | x | - | - | `C ← [A0]; [A7] ← C; [A] ← [A] >> 1` | **Rotate Right.** Rotates Accumulator A right through the Carry bit C. Bit 7 takes the value of C, and Bit 0 moves into C. |
| ROR | `B` | ACC | 1 | `56` | 1 | x | x | x | x | - | - | `C ← [B0]; [B7] ← C; [B] ← [B] >> 1` | Rotates Accumulator B right through the Carry bit C. Bit 7 takes the value of C, and Bit 0 moves into C. |
| ROR | `Disp,X` | IDX | 2 | `66 Disp`  | 6 | x | x | x | x | - | - | `C ← [M0]; [M7] ← C; [M] ← [M] >> 1` | Rotates memory at `Disp + [X]` right through the Carry bit C. Bit 7 takes the value of C, and Bit 0 moves into C. |
| ROR | `addr16` | EXT | 3 | `76 MH ML` | 6 | x | x | x | x | - | - | `C ← [M0]; [M7] ← C; [M] ← [M] >> 1` | Rotates memory at `addr16` right through the Carry bit C. Bit 7 takes the value of C, and Bit 0 moves into C. |
| RTI | `RTI` | INH | 1 | `3B` | 10 | x | x | x | x | x | x | `[SR] ← [[SP]+1]; [B] ← [[SP]+2]; [A] ← [[SP]+3]; [IXH] ← [[SP]+4]; [IXL] ← [[SP]+5]; [PCH] ← [[SP]+6]; [PCL] ← [[SP]+7]; [SP] ← [SP] + 7` | **Return from Interrupt.** Pulls Condition Code Register, Accumulator B, Accumulator A, Index Register (high/low), and Program Counter (high/low) from the stack, restoring processor state, and increments the Stack Pointer. (Note: SP is incremented after each byte is pulled). |
| RTS | `RTS` | INH | 1 | `39` | 5 | - | - | - | - | - | - | `[PCH] ← [[SP]+1]; [PCL] ← [[SP]+2]; [SP] ← [SP] + 2` | **Return from Subroutine.** Pulls the Program Counter (return address) from the stack and increments the Stack Pointer. |
| SBA | `SBA` | INH | 1 | `10` | 1 | x | x | x | x | - | - | `[A] ← [A] - [B]` | **Subtract Accumulators.** Subtracts the contents of Accumulator B from Accumulator A, storing the result in Accumulator A. Accumulator B is not affected. |
| SBC | `A #data8` | IMM | 2 | `82 data8` | 2 | x | x | x | x | - | - | `[A] ← [A] - data8 - C` | **Subtract with Carry.** Subtracts immediate data and the Carry bit C from Accumulator A, storing the result in Accumulator A. |
| SBC | `A addr8` | DIR | 2 | `92 addr8` | 3 | x | x | x | x | - | - | `[A] ← [A] - [addr8] - C`  | Subtracts the contents of memory at `addr8` and the Carry bit C from Accumulator A, storing the result in Accumulator A. |
| SBC | `A Disp,X` | IDX | 2 | `A2 Disp`  | 4 | x | x | x | x | - | - | `[A] ← [A] - [Disp+[X]] - C` | Subtracts the contents of memory at `Disp + [X]` and the Carry bit C from Accumulator A, storing the result in Accumulator A. |
| SBC | `A addr16` | EXT | 3 | `B2 MH ML` | 4 | x | x | x | x | - | - | `[A] ← [A] - [addr16] - C` | Subtracts the contents of memory at `addr16` and the Carry bit C from Accumulator A, storing the result in Accumulator A. |
| SBC | `B #data8` | IMM | 2 | `C2 data8` | 2 | x | x | x | x | - | - | `[B] ← [B] - data8 - C` | Subtracts immediate data and the Carry bit C from Accumulator B, storing the result in Accumulator B. |
| SBC | `B addr8` | DIR | 2 | `D2 addr8` | 3 | x | x | x | x | - | - | `[B] ← [B] - [addr8] - C`  | Subtracts the contents of memory at `addr8` and the Carry bit C from Accumulator B, storing the result in Accumulator B. |
| SBC | `B Disp,X` | IDX | 2 | `E2 Disp`  | 4 | x | x | x | x | - | - | `[B] ← [B] - [Disp+[X]] - C` | Subtracts the contents of memory at `Disp + [X]` and the Carry bit C from Accumulator B, storing the result in Accumulator B. |
| SBC | `B addr16` | EXT | 3 | `F2 MH ML` | 4 | x | x | x | x | - | - | `[B] ← [B] - [addr16] - C` | Subtracts the contents of memory at `addr16` and the Carry bit C from Accumulator B, storing the result in Accumulator B. |
| SEC | `SEC` | INH | 1 | `0D` | 1 | 1 | - | - | - | - | - | `C ← 1` | **Set Carry.** Sets the Carry bit C in the CCR. |
| SEI | `SEI` | INH | 1 | `0F` | 1 | - | - | - | - | - | 1 | `I ← 1` | **Set Interrupt Mask.** Sets the Interrupt Mask bit I in the CCR, inhibiting maskable interrupts. |
| SEV | `SEV` | INH | 1 | `0B` | 1 | - | - | - | 1 | - | - | `O ← 1` | **Set Overflow.** Sets the Overflow bit O in the CCR. |
| SLP | `SLP` | INH | 1 | `1A` | 4 | - | - | - | - | - | - | `CPU Halt` | **Sleep.** (HD6301/HD6303 Enhancement) Halts the CPU to reduce power consumption, maintaining internal register states. The CPU resumes execution upon an interrupt request. |
| STA | `A addr8` | DIR | 2 | `97 addr8` | 3 | - | x | x | 0 | - | - | `[addr8] ← [A]` | **Store Accumulator.** Stores the contents of Accumulator A into memory at `addr8`. Accumulator A is not affected. |
| STA | `A Disp,X` | IDX | 2 | `A7 Disp`  | 4 | - | x | x | 0 | - | - | `[Disp+[X]] ← [A]` | Stores the contents of Accumulator A into memory addressed by `Disp + [X]`. Accumulator A is not affected. |
| STA | `A addr16` | EXT | 3 | `B7 MH ML` | 4 | - | x | x | 0 | - | - | `[addr16] ← [A]` | Stores the contents of Accumulator A into memory at `addr16`. Accumulator A is not affected. |
| STA | `B addr8` | DIR | 2 | `D7 addr8` | 3 | - | x | x | 0 | - | - | `[addr8] ← [B]` | Stores the contents of Accumulator B into memory at `addr8`. Accumulator B is not affected. |
| STA | `B Disp,X` | IDX | 2 | `E7 Disp`  | 4 | - | x | x | 0 | - | - | `[Disp+[X]] ← [B]` | Stores the contents of Accumulator B into memory addressed by `Disp + [X]`. Accumulator B is not affected. |
| STA | `B addr16` | EXT | 3 | `F7 MH ML` | 4 | - | x | x | 0 | - | - | `[addr16] ← [B]` | Stores the contents of Accumulator B into memory at `addr16`. Accumulator B is not affected. |
| STD | `addr8` | DIR | 2 | `DD addr8` | 4 | - | x | x | 0 | - | - | `[addr8:addr8+1] ← [ACCD]` | **Double Store Accumulator A:B.** (HD6301/HD6303 Enhancement) Stores the 16-bit contents of the Double Accumulator (ACCD) into memory at `addr8` and `addr8+1`. ACCD is not affected. |
| STD | `Disp,X` | IDX | 2 | `ED Disp`  | 5 | - | x | x | 0 | - | - | `[Disp+[X]:Disp+[X]+1] ← [ACCD]` | (HD6301/HD6303 Enhancement) Stores the 16-bit contents of ACCD into memory addressed by `Disp + [X]`. ACCD is not affected. |
| STD | `addr16` | EXT | 3 | `FD MH ML` | 5 | - | x | x | 0 | - | - | `[addr16:addr16+1] ← [ACCD]` | (HD6301/HD6303 Enhancement) Stores the 16-bit contents of ACCD into memory at `addr16` and `addr16+1`. ACCD is not affected. |
| STS | `addr8` | DIR | 2 | `9F addr8` | 4 | - | x | x | 0 | - | - | `[addr8] ← [SP(HI)]; [addr8+1] ← [SP(LO)]` | **Store Stack Pointer.** Stores the 16-bit Stack Pointer into memory at `addr8` and `addr8+1`. Stack Pointer is not affected. |
| STS | `Disp,X` | IDX | 2 | `AF Disp`  | 5 | - | x | x | 0 | - | - | `[Disp+[X]] ← [SP(HI)]; [Disp+[X]+1] ← [SP(LO)]` | Stores the 16-bit Stack Pointer into memory addressed by `Disp + [X]`. Stack Pointer is not affected. |
| STS | `addr16` | EXT | 3 | `BF MH ML` | 5 | - | x | x | 0 | - | - | `[addr16] ← [SP(HI)]; [addr16+1] ← [SP(LO)]` | Stores the 16-bit Stack Pointer into memory at `addr16`. Stack Pointer is not affected. |
| STX | `addr8` | DIR | 2 | `DF addr8` | 4 | - | x | x | 0 | - | - | `[addr8] ← [X(HI)]; [addr8+1] ← [X(LO)]` | **Store Index Register.** Stores the 16-bit Index Register into memory at `addr8` and `addr8+1`. Index Register is not affected. |
| STX | `Disp,X` | IDX | 2 | `EF Disp`  | 5 | - | x | x | 0 | - | - | `[Disp+[X]] ← [X(HI)]; [Disp+[X]+1] ← [X(LO)]` | Stores the 16-bit Index Register into memory addressed by `Disp + [X]`. Index Register is not affected. |
| STX | `addr16` | EXT | 3 | `FF MH ML` | 5 | - | x | x | 0 | - | - | `[addr16] ← [X(HI)]; [addr16+1] ← [X(LO)]` | Stores the 16-bit Index Register into memory at `addr16`. Index Register is not affected. |
| SUB | `A #data8` | IMM | 2 | `80 data8` | 2 | x | x | x | x | - | - | `[A] ← [A] - data8` | **Subtract.** Subtracts immediate data from Accumulator A, storing the result in Accumulator A. |
| SUB | `A addr8` | DIR | 2 | `90 addr8` | 3 | x | x | x | x | - | - | `[A] ← [A] - [addr8]` | Subtracts the contents of memory at `addr8` from Accumulator A, storing the result in Accumulator A. |
| SUB | `A Disp,X` | IDX | 2 | `A0 Disp`  | 4 | x | x | x | x | - | - | `[A] ← [A] - [Disp+[X]]` | Subtracts the contents of memory at `Disp + [X]` from Accumulator A, storing the result in Accumulator A. |
| SUB | `A addr16` | EXT | 3 | `B0 MH ML` | 4 | x | x | x | x | - | - | `[A] ← [A] - [addr16]` | Subtracts the contents of memory at `addr16` from Accumulator A, storing the result in Accumulator A. |
| SUB | `B #data8` | IMM | 2 | `C0 data8` | 2 | x | x | x | x | - | - | `[B] ← [B] - data8` | Subtracts immediate data from Accumulator B, storing the result in Accumulator B. |
| SUB | `B addr8` | DIR | 2 | `D0 addr8` | 3 | x | x | x | x | - | - | `[B] ← [B] - [addr8]` | Subtracts the contents of memory at `addr8` from Accumulator B, storing the result in Accumulator B. |
| SUB | `B Disp,X` | IDX | 2 | `E0 Disp`  | 4 | x | x | x | x | - | - | `[B] ← [B] - [Disp+[X]]` | Subtracts the contents of memory at `Disp + [X]` from Accumulator B, storing the result in Accumulator B. |
| SUB | `B addr16` | EXT | 3 | `F0 MH ML` | 4 | x | x | x | x | - | - | `[B] ← [B] - [addr16]` | Subtracts the contents of memory at `addr16` from Accumulator B, storing the result in Accumulator B. |
| SUBD  | `#data16` | IMM | 3 | `83 ImmH ImmL` | 3 | x | x | x | x | - | - | `[ACCD] ← [ACCD] - data16` | **Double Subtract without Carry.** (HD6301/HD6303 Enhancement) Subtracts 16-bit immediate data from the Double Accumulator (ACCD), storing the result in ACCD. |
| SUBD  | `addr8` | DIR | 2 | `93 addr8` | 4 | x | x | x | x | - | - | `[ACCD] ← [ACCD] - [addr8:addr8+1]` | (HD6301/HD6303 Enhancement) Subtracts the contents of memory at `addr8` and `addr8+1` (16-bit) from ACCD, storing the result in ACCD. |
| SUBD  | `Disp,X` | IDX | 2 | `A3 Disp`  | 5 | x | x | x | x | - | - | `[ACCD] ← [ACCD] - [Disp+[X]:Disp+[X]+1]` | (HD6301/HD6303 Enhancement) Subtracts the contents of memory (16-bit) addressed by `Disp + [X]` from ACCD, storing the result in ACCD. |
| SUBD  | `addr16` | EXT | 3 | `B3 MH ML` | 5 | x | x | x | x | - | - | `[ACCD] ← [ACCD] - [addr16:addr16+1]` | (HD6301/HD6303 Enhancement) Subtracts the contents of memory (16-bit) at `addr16` from ACCD, storing the result in ACCD. |
| SWI | `SWI` | INH | 1 | `3F` | 12 | - | - | - | - | - | 1 | `Push PC, X, A, B, SR to stack; [SP] ← [SP]-7; [PC] ← [$FFFA]` | **Software Interrupt.** Increments PC, pushes processor registers (PC, X, A, B, SR) onto the stack, decrements SP, sets Interrupt Mask (I) bit, and loads the interrupt vector address (from $FFFA/$FFFB) into PC. (Note: PC is incremented by 1 before being pushed, SP is decremented by 1 after each byte push for a total of 7 bytes). |
| TAB | `TAB` | INH | 1 | `16` | 1 | - | x | x | 0 | - | - | `[B] ← [A]` | **Transfer A to B.** Transfers the contents of Accumulator A to Accumulator B. Accumulator A is not affected. |
| TAP | `TAP` | INH | 1 | `06` | 1 | x | x | x | x | x | x | `[SR] ← [A]` | **Transfer A to Processor Condition Codes Register.** Transfers bits 0 through 5 of Accumulator A to the corresponding bits of the Condition Code Register. Accumulator A is not affected. |
| TBA | `TBA` | INH | 1 | `17` | 1 | - | x | x | 0 | - | - | `[A] ← [B]` | **Transfer B to A.** Transfers the contents of Accumulator B to Accumulator A. Accumulator B is not affected. |
| TIM | `data8, addr8` | DIR | 3 | `7B data8 addr8` | 4 | - | x | x | 0 | - | - | `data8 ∧ [addr8]` | **Test Immediate.** (HD6301/HD6303 Enhancement) Performs a logical AND operation between immediate data and the contents of a memory location, affecting only the Condition Code Register. Both operands remain unchanged. |
| TIM | `data8, Disp,X`  | IDX | 3 | `6B data8 Disp` | 5 | - | x | x | 0 | - | - | `data8 ∧ [Disp+[X]]` | (HD6301/HD6303 Enhancement) Performs a logical AND operation between immediate data and the contents of a memory location addressed by `Disp + [X]`, affecting only the Condition Code Register. Both operands remain unchanged. |
| TPA | `TPA` | INH | 1 | `07` | 1 | - | - | - | - | - | - | `[A] ← [SR]` | **Transfer Processor Condition Codes Register to A.** Transfers bits 0 through 5 of the Condition Code Register to the corresponding bits of Accumulator A. The CCR is not affected. |
| TST | `A` | ACC | 1 | `4D` | 1 | 0 | x | x | 0 | - | - | `[A] - 0` | **Test.** Sets the Zero (Z) and Sign (S/N) bits of the CCR according to the contents of Accumulator A. Accumulator A is not affected. |
| TST | `B` | ACC | 1 | `5D` | 1 | 0 | x | x | 0 | - | - | `[B] - 0` | Sets the Zero (Z) and Sign (S/N) bits of the CCR according to the contents of Accumulator B. Accumulator B is not affected. |
| TST | `Disp,X` | IDX | 2 | `6D Disp`  | 4 | 0 | x | x | 0 | - | - | `[Disp+[X]] - 0` | Sets the Zero (Z) and Sign (S/N) bits of the CCR according to the contents of the memory location addressed by `Disp + [X]`. The memory location is not affected. |
| TST | `addr16` | EXT | 3 | `7D MH ML` | 4 | 0 | x | x | 0 | - | - | `[addr16] - 0` | Sets the Zero (Z) and Sign (S/N) bits of the CCR according to the contents of the memory location at `addr16`. The memory location is not affected. |
| TSX | `TSX` | INH | 1 | `30` | 1 | - | - | - | - | - | - | `[X] ← [SP] + 1` | **Transfer Stack Pointer to Index Register.** Increments the contents of the Stack Pointer by one and loads the result into the Index Register. The Stack Pointer is not affected. |
| TXS | `TXS` | INH | 1 | `35` | 1 | - | - | - | - | - | - | `[SP] ← [X] - 1` | **Transfer Index Register to Stack Pointer.** Decrements the contents of the Index Register by one and loads the result into the Stack Pointer. The Index Register is not affected. |
| WAI | `WAI` | INH | 1 | `3E` | 9 | - | - | - | - | - | x | `Push PC, X, A, B, SR to stack; [SP] ← [SP]-7; Wait for Interrupt` | **Wait for Interrupt.** Increments PC, pushes processor registers (PC, X, A, B, SR) onto the stack, decrements SP, and then halts

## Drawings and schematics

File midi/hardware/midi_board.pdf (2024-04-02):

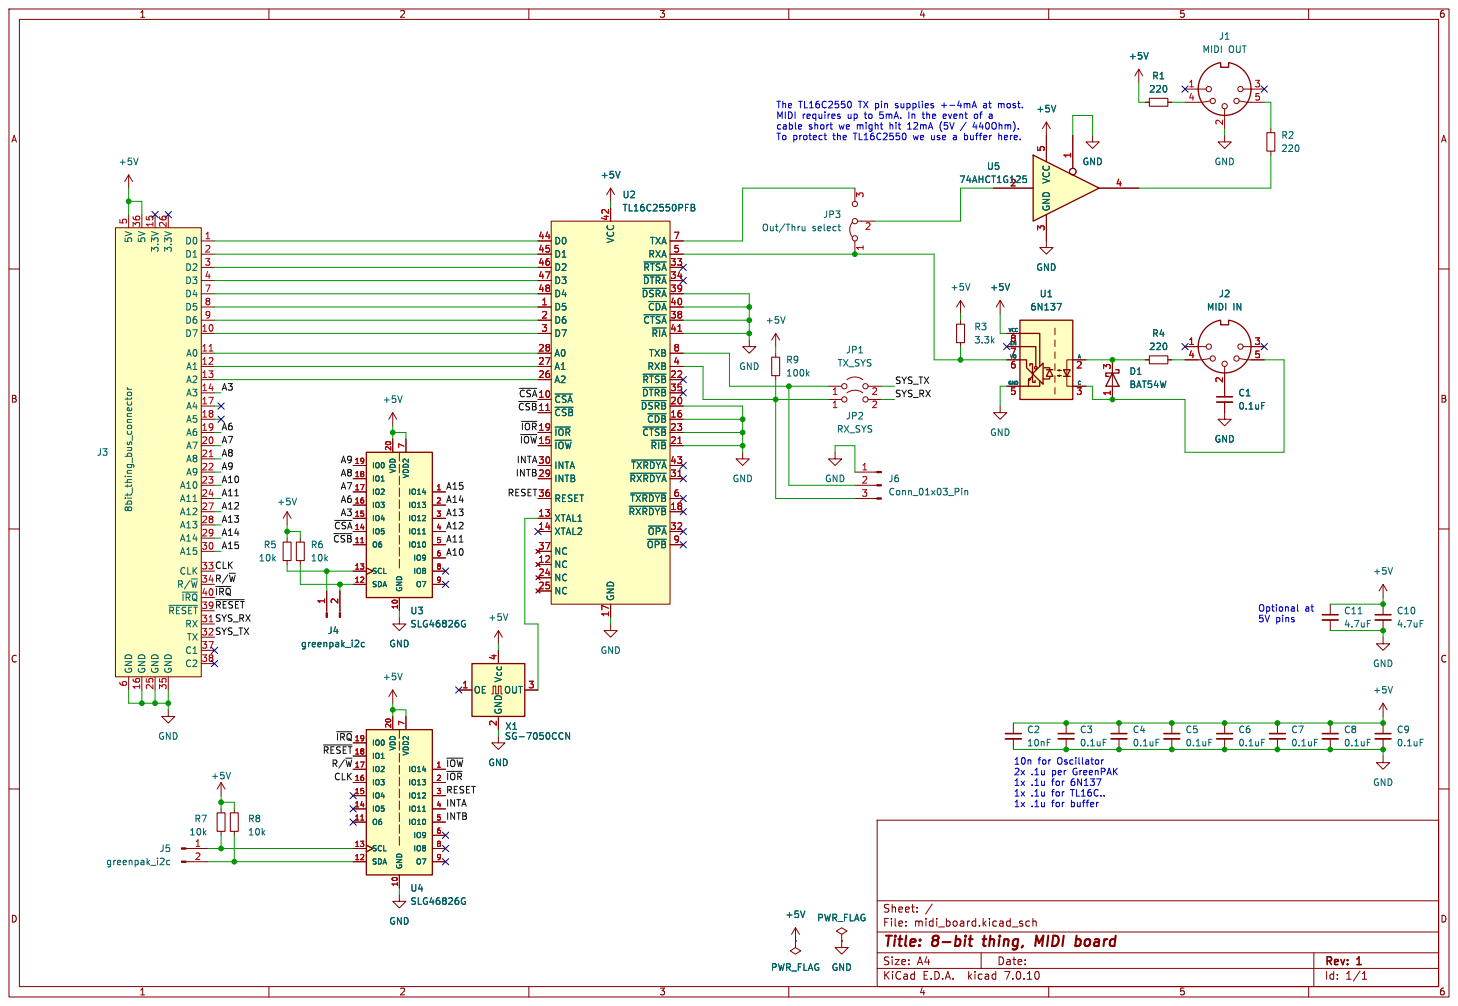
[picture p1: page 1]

cable short we might hit 12mA (5V / 440Ohm). To protect the TL16C2550 we use a buffer here.
INTB 29 D7 3

2 OUT 3 Vcc 4 X1SG-7050CCN GND GND

10n for Oscillator 2x .1u per GreenPAK

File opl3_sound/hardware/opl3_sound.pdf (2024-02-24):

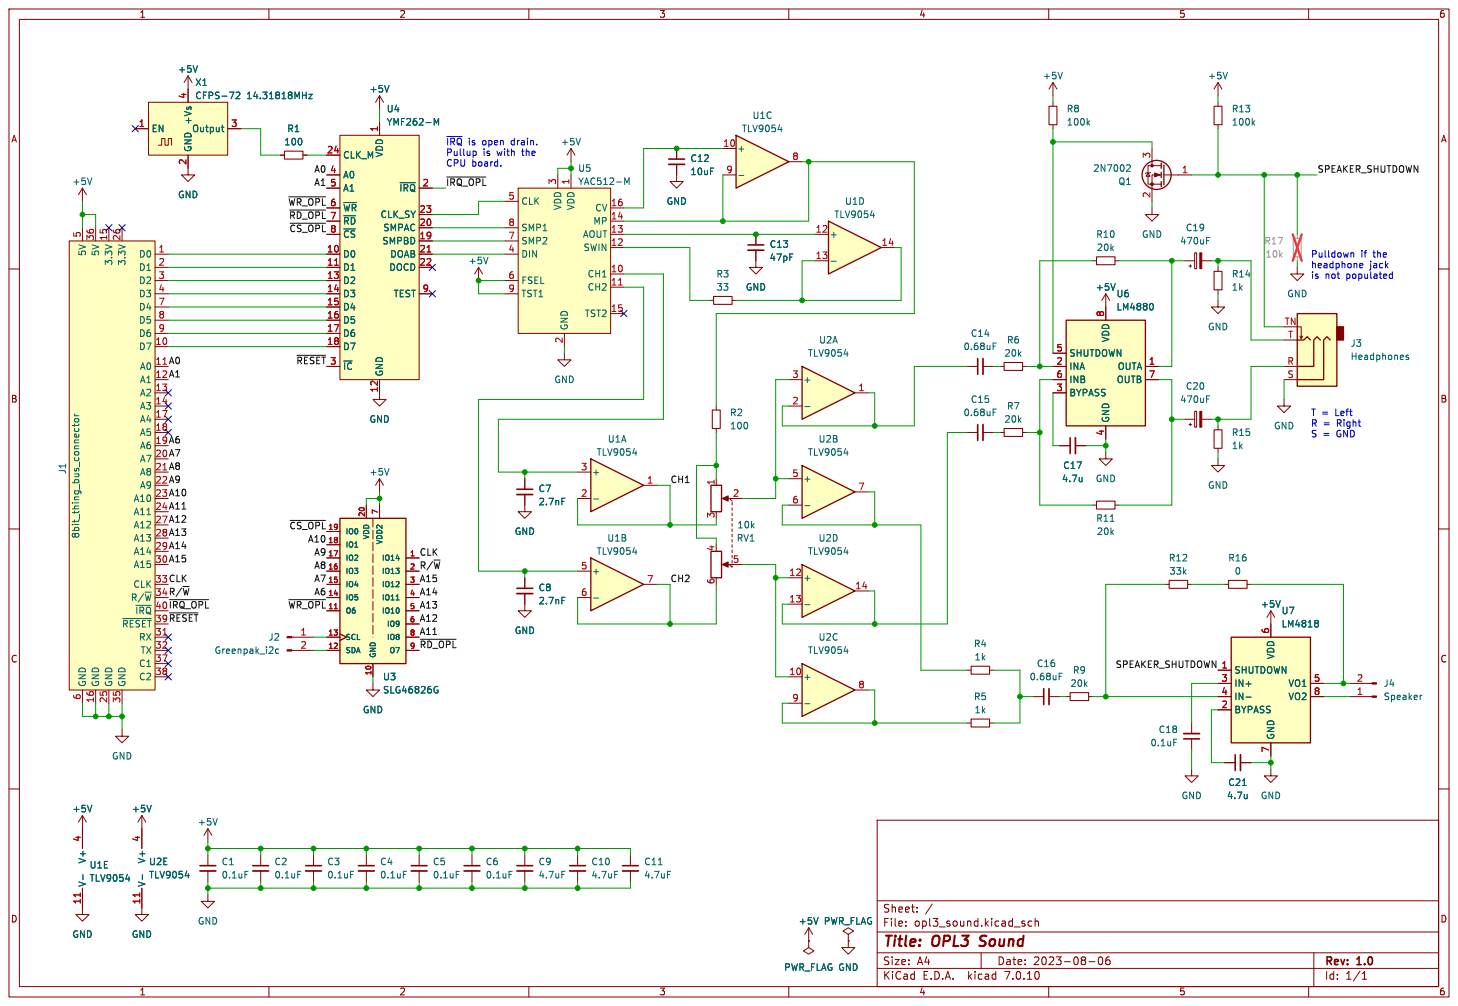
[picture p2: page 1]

1 D0 10 D1 11 GND 12 D2 13 D3 14 D4 15 D5 16 D6 17 D7 18 SMPBD 19 ~{IRQ}2 SMPAC 20 DOAB 21 DOCD 22 CLK_SY 23 CLK_M 24 ~{IC} 3 A0 4 A1 5 ~{WR} 6 ~{RD} 7 ~{CS} 8 TEST 9 U4YMF262-M

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

1 CH1 10 CH2 11 SWIN 12 AOUT 13 MP 14 TST2 15 CV 16 GND

is not populated GND

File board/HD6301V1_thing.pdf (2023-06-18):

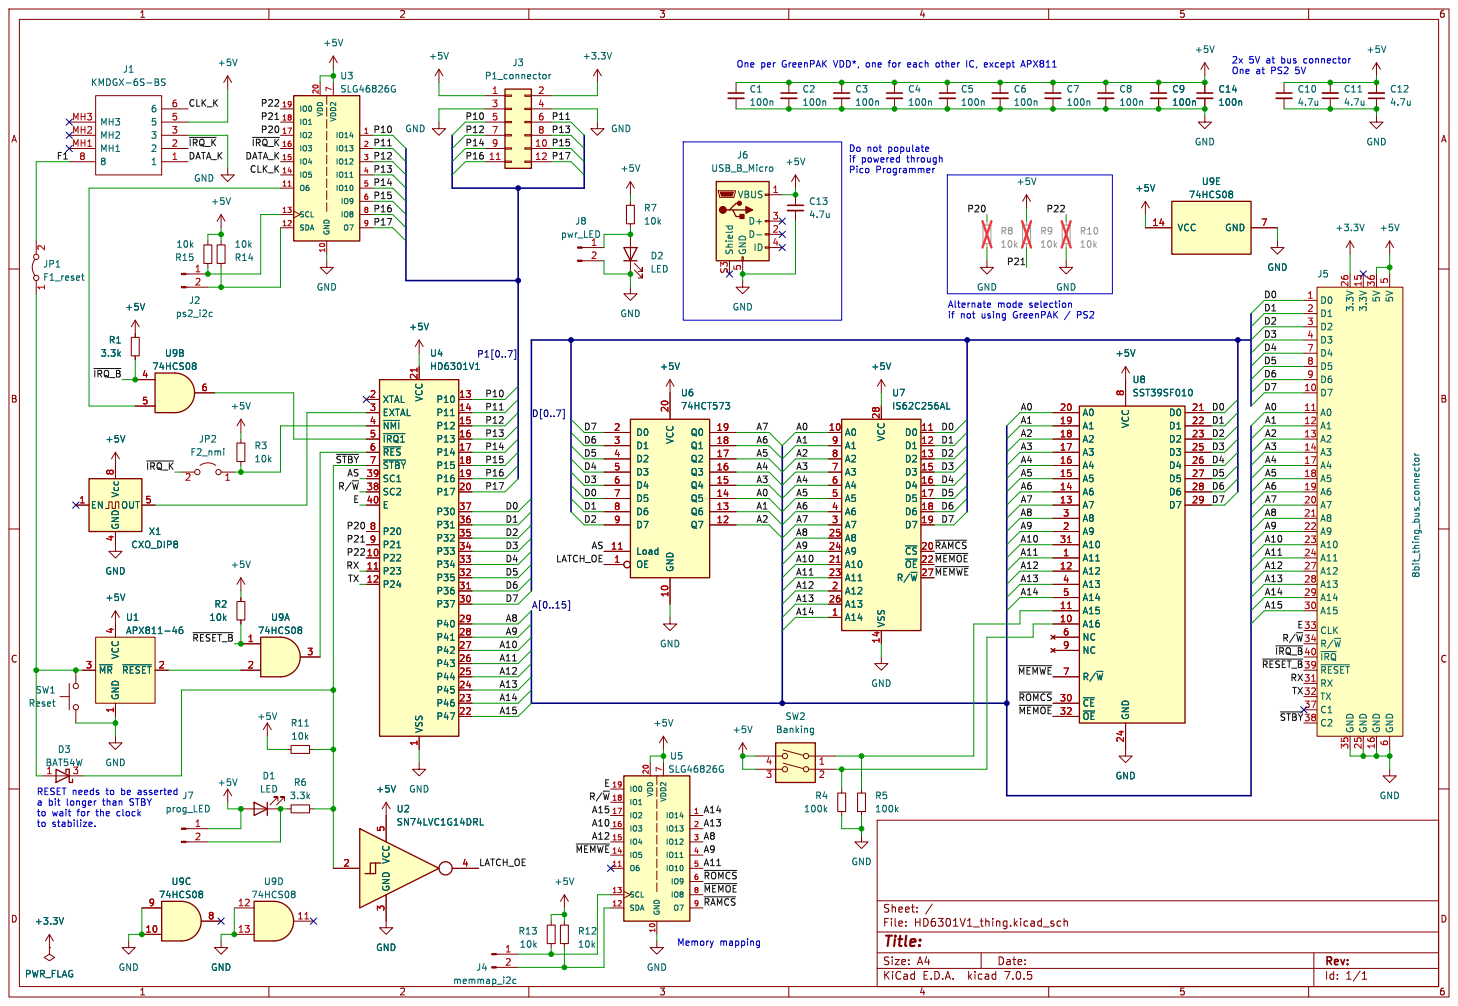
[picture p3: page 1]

2x 5V at bus connector One at PS2 5V

1 P22 10 P23 11 P24 12 P10 13 P11 14 P12 15 P13 16 P14 17 P15 18 P16 19 XTAL 2 P17 20 VCC 21 P47 22 P46 23 P45 24 P44 25 P43 26 P42 27 P41 28 P40 29 EXTAL 3 P37 30 P36 31 P35 32 P34 33 P33 34 P32 35 P31 36 P30 37 SC2 38 SC1 39 ~{NMI} 4 E

Memory mapping RESET needs to be asserted
a bit longer than STBY
to wait for the clock
to stabilize.

Id: 1/1 Title: File: HD6301V1_thing.kicad_sch Sheet: / R4

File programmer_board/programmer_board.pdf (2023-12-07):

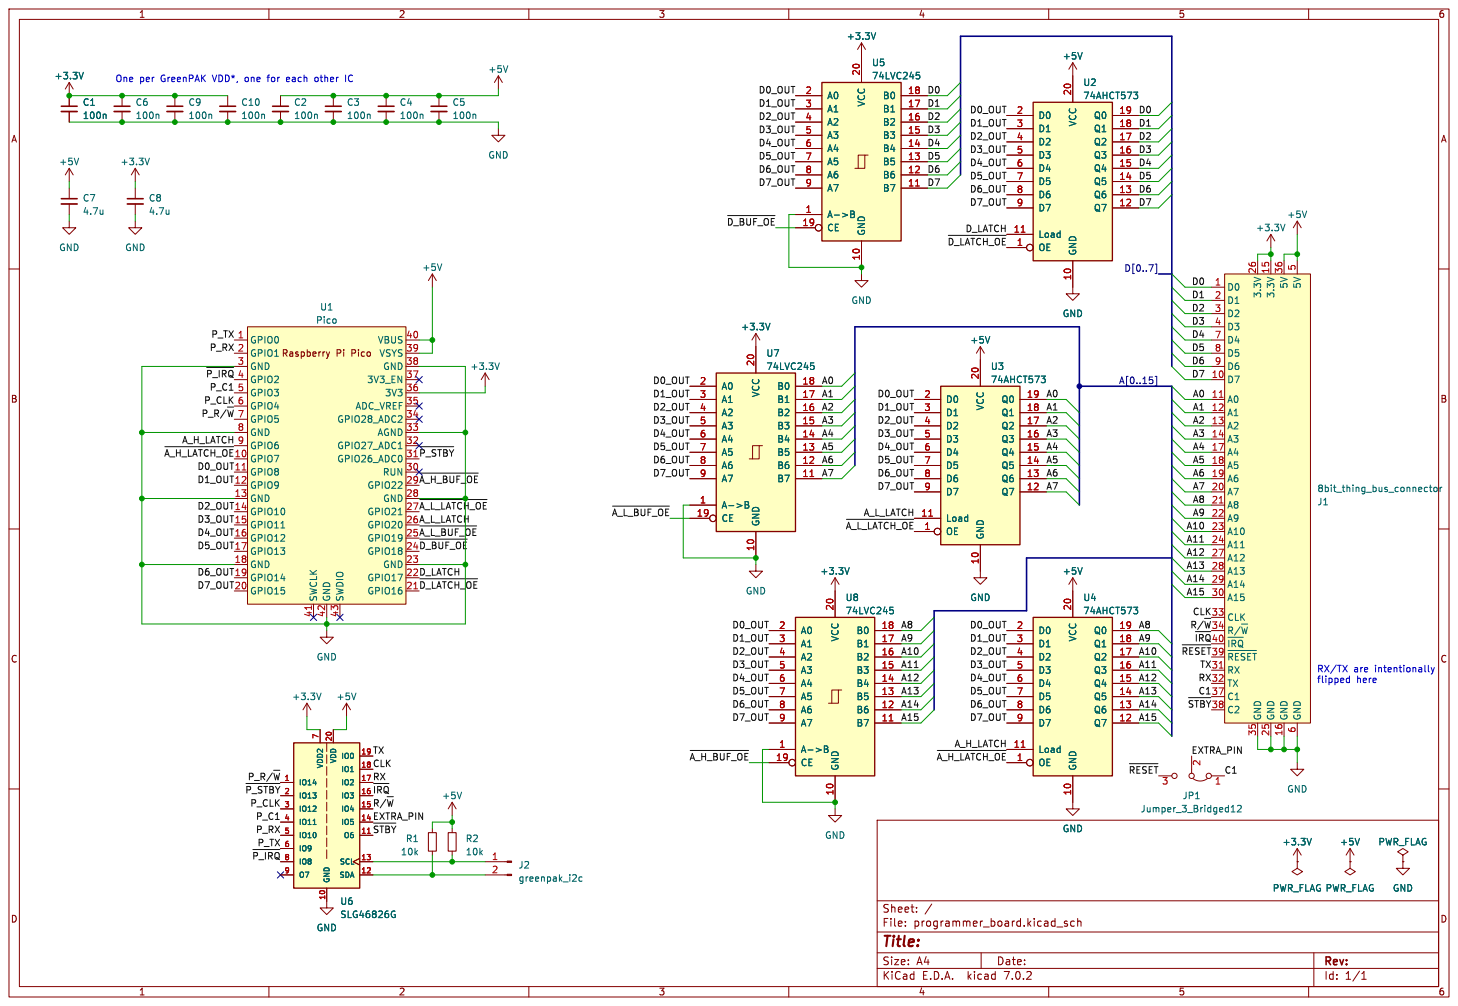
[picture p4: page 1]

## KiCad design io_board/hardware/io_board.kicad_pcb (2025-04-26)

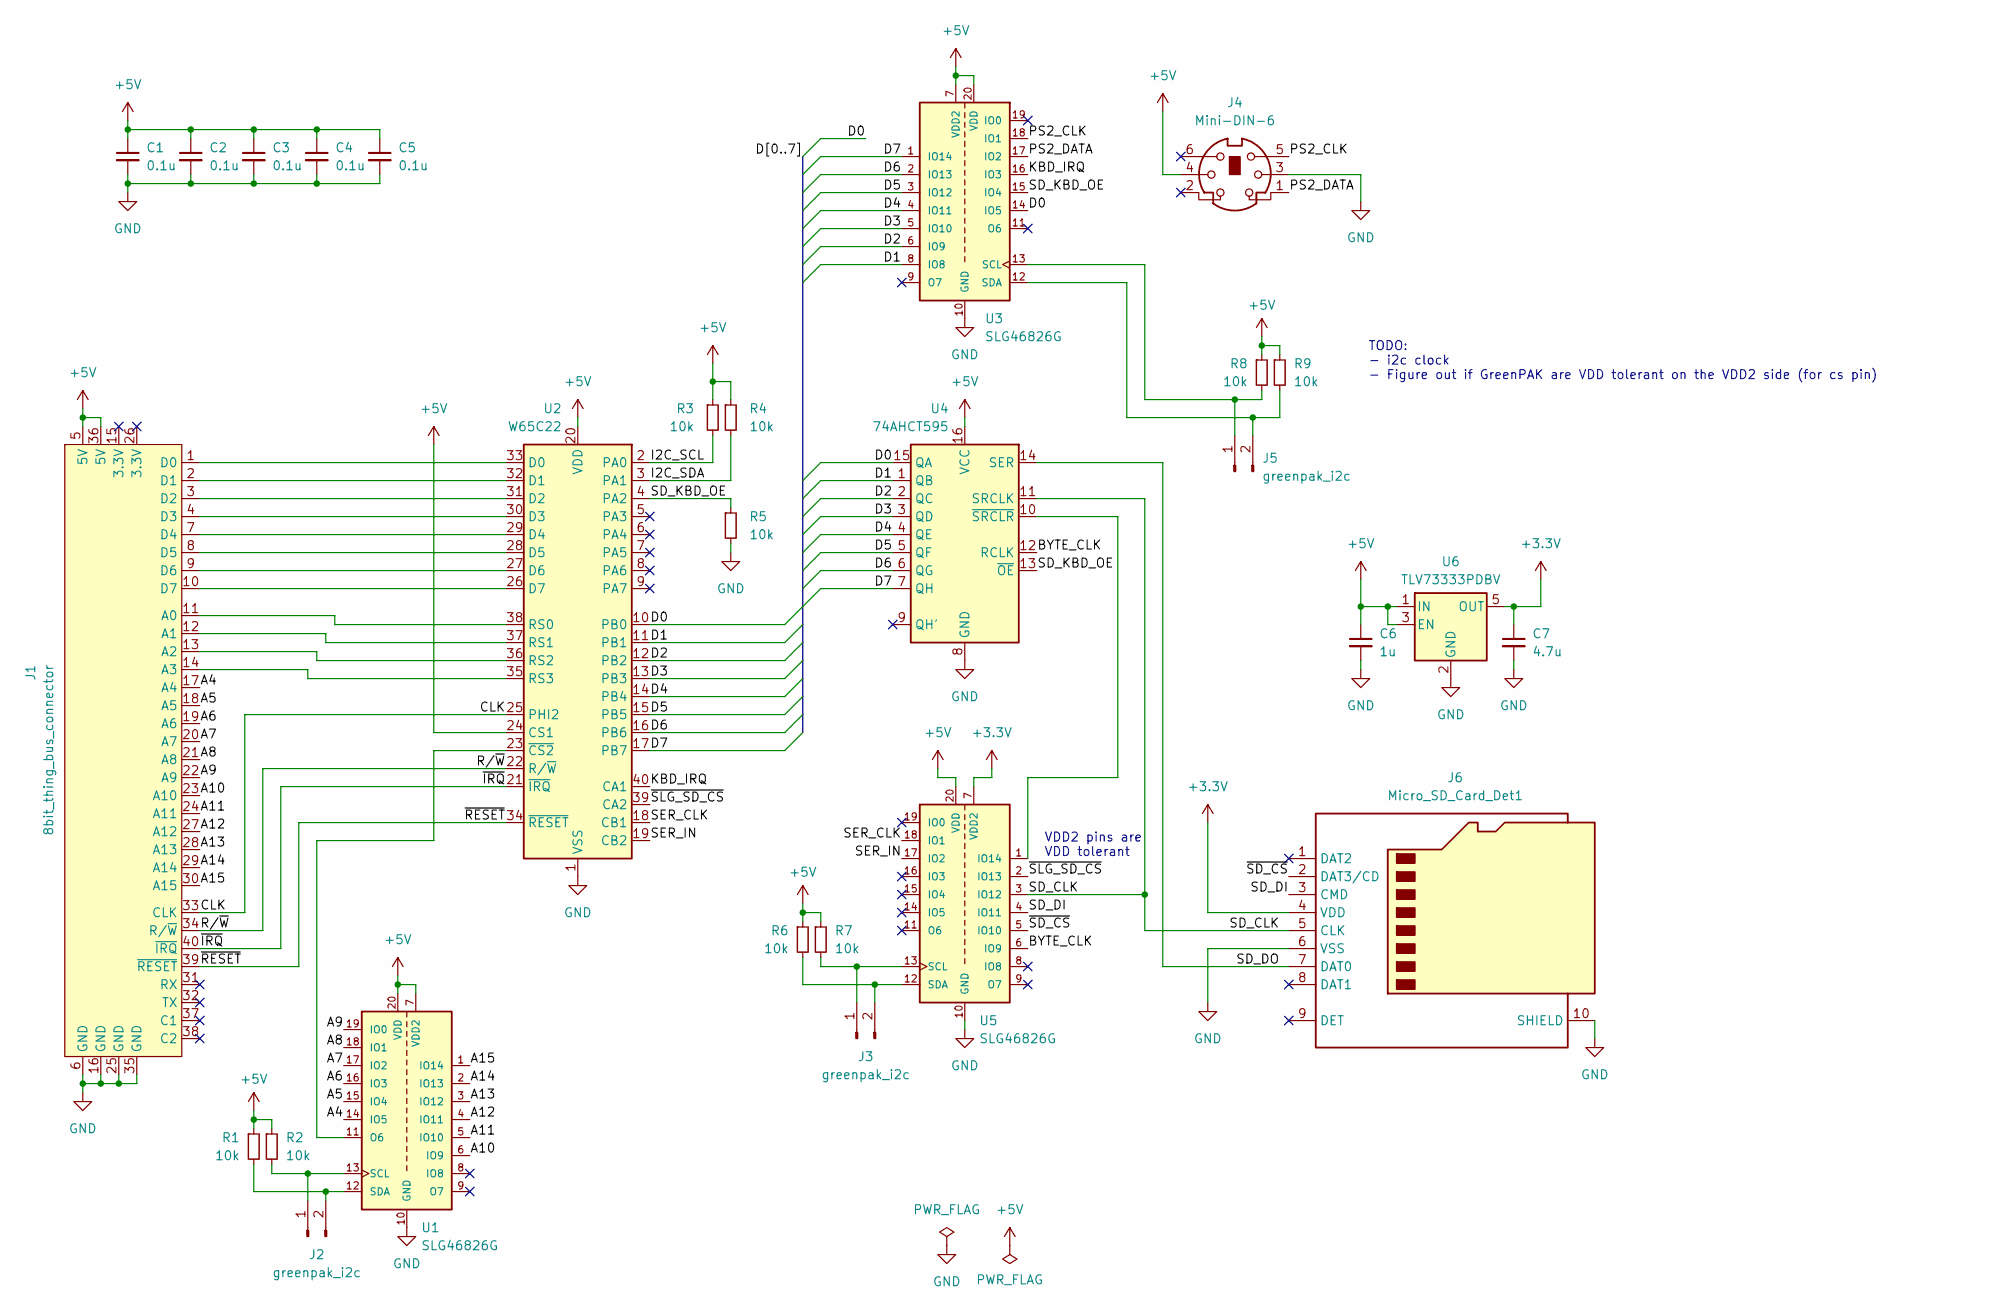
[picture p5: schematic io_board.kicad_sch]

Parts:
C1, C2, C3, C4, C5: 0.1u; C_0805_2012Metric_Pad1.18x1.45mm_HandSolder
C6: 1u; C_0805_2012Metric_Pad1.18x1.45mm_HandSolder
C7: 4.7u; C_0805_2012Metric_Pad1.18x1.45mm_HandSolder
J1: 8bit_thing_bus_connector; IDC-Header_2x20_P2.54mm_Horizontal
J2, J3, J5: greenpak_i2c; PinHeader_1x02_P2.54mm_Vertical_minimal
J4: Mini-DIN-6; KMDGX6SBS
J6: Micro_SD_Card_Det1; microSD_HC_Hirose_DM3D-SF
R1, R2, R3, R4, R5, R6, R7, R8, R9: 10k; R_0805_2012Metric_Pad1.20x1.40mm_HandSolder
U1, U3, U5: SLG46826G; SOP65P640X120-20N; PARTREV 3.10
U2: W65C22; DIP-40_W15.24mm
U4: 74AHCT595; TSSOP-16_4.4x5mm_P0.65mm
U6: TLV73333PDBV; SOT-23-5

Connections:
+3.3V: C7.1, J6.4 (VDD), U5.7 (VDD2), U6.5 (OUT)
+5V: C1.1, C2.1, C3.1, C4.1, C5.1, C6.1, J1.5 (5V), J1.36 (5V), J4.4, R1.1, R2.1, R3.1, R4.1, R6.1, R7.1, R8.1, R9.1, U1.7 (VDD2), U1.20 (VDD), U2.20 (VDD), U2.24 (CS1), U3.7 (VDD2), U3.20 (VDD), U4.16 (VCC), U5.20 (VDD), U6.1 (IN), U6.3 (EN)
/A4: J1.17 (A4), U1.14 (IO5)
/A5: J1.18 (A5), U1.15 (IO4)
/A6: J1.19 (A6), U1.16 (IO3)
/A7: J1.20 (A7), U1.17 (IO2)
/A8: J1.21 (A8), U1.18 (IO1)
/A9: J1.22 (A9), U1.19 (IO0)
/A10: J1.23 (A10), U1.6 (IO9)
/A11: J1.24 (A11), U1.5 (IO10)
/A12: J1.27 (A12), U1.4 (IO11)
/A13: J1.28 (A13), U1.3 (IO12)
/A14: J1.29 (A14), U1.2 (IO13)
/A15: J1.30 (A15), U1.1 (IO14)
/BYTE_CLK: U4.12 (RCLK), U5.6 (IO9)
/CLK: J1.33 (CLK), U2.25 (PHI2)
/D0: U2.10 (PB0), U3.14 (IO5), U4.15 (QA)
/D1: U2.11 (PB1), U3.8 (IO8), U4.1 (QB)
/D2: U2.12 (PB2), U3.6 (IO9), U4.2 (QC)
/D3: U2.13 (PB3), U3.5 (IO10), U4.3 (QD)
/D4: U2.14 (PB4), U3.4 (IO11), U4.4 (QE)
/D5: U2.15 (PB5), U3.3 (IO12), U4.5 (QF)
/D6: U2.16 (PB6), U3.2 (IO13), U4.6 (QG)
/D7: U2.17 (PB7), U3.1 (IO14), U4.7 (QH)
/I2C_SCL: R3.2, U2.2 (PA0)
/I2C_SDA: R4.2, U2.3 (PA1)
/KBD_IRQ: U2.40 (CA1), U3.16 (IO3)
/PS2_CLK: J4.5, U3.18 (IO1)
/PS2_DATA: J4.1, U3.17 (IO2)
/R/~W: J1.34 (R/~W), U2.22 (R/~W)
/SD_CLK: J6.5 (CLK), U4.11 (SRCLK), U5.3 (IO12)
/SD_DI: J6.3 (CMD), U5.4 (IO11)
/SD_DO: J6.7 (DAT0), U4.14 (SER)
/SD_KBD_OE: R5.1, U2.4 (PA2), U3.15 (IO4), U4.13 (~OE)
/SER_CLK: U2.18 (CB1), U5.18 (IO1)
/SER_IN: U2.19 (CB2), U5.17 (IO2)
/~IRQ: J1.40 (~IRQ), U2.21 (~IRQ)
/~RESET: J1.39 (~RESET), U2.34 (~RESET)
/~SD_CS: J6.2 (DAT3/CD), U5.5 (IO10)
/~SLG_SD_CS: U2.39 (CA2), U5.2 (IO13)
GND: C1.2, C2.2, C3.2, C4.2, C5.2, C6.2, C7.2, J1.6 (GND), J1.16 (GND), J1.25 (GND), J1.35 (GND), J4.3, J6.6 (VSS), J6.10 (SHIELD), R5.2, U1.10 (GND), U2.1 (VSS), U3.10 (GND), U4.8 (GND), U5.10 (GND), U6.2 (GND)
unnamed: J1.11 (A0), U2.38 (RS0)
unnamed: J1.12 (A1), U2.37 (RS1)
unnamed: J1.13 (A2), U2.36 (RS2)
unnamed: J1.14 (A3), U2.35 (RS3)
unnamed: J1.1 (D0), U2.33 (D0)
unnamed: J1.2 (D1), U2.32 (D1)
unnamed: J1.3 (D2), U2.31 (D2)
unnamed: J1.4 (D3), U2.30 (D3)
unnamed: J1.7 (D4), U2.29 (D4)
unnamed: J1.8 (D5), U2.28 (D5)
unnamed: J1.9 (D6), U2.27 (D6)
unnamed: J1.10 (D7), U2.26 (D7)
unnamed: J2.1, R2.2, U1.13 (SCL)
unnamed: J2.2, R1.2, U1.12 (SDA)
unnamed: J3.1, R7.2, U5.13 (SCL)
unnamed: J3.2, R6.2, U5.12 (SDA)
unnamed: J5.1, R8.2, U3.13 (SCL)
unnamed: J5.2, R9.2, U3.12 (SDA)
unnamed: U1.11 (O6), U2.23 (~CS2)
unnamed: U4.10 (~SRCLR), U5.1 (IO14)

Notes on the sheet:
TODO: - i2c clock - Figure out if GreenPAK are VDD tolerant on the VDD2 side (for cs pin)
VDD2 pins are VDD tolerant

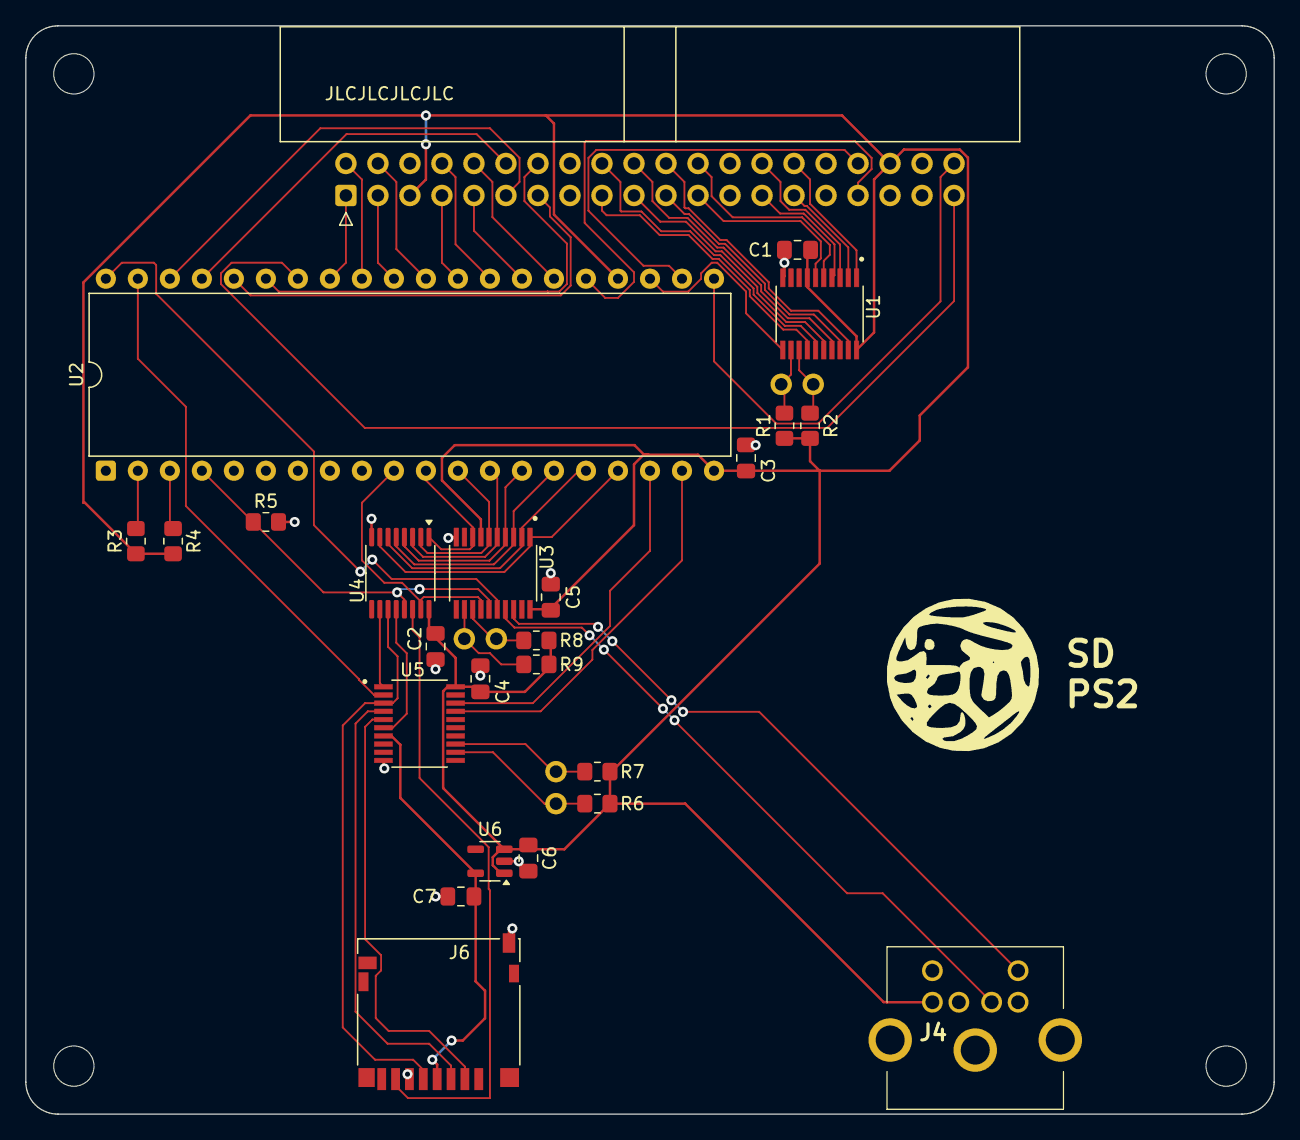
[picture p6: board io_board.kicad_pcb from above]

Board: 2 copper layers, 99.1 x 86.4 mm, 28 parts (0 on the bottom side), 61 nets.

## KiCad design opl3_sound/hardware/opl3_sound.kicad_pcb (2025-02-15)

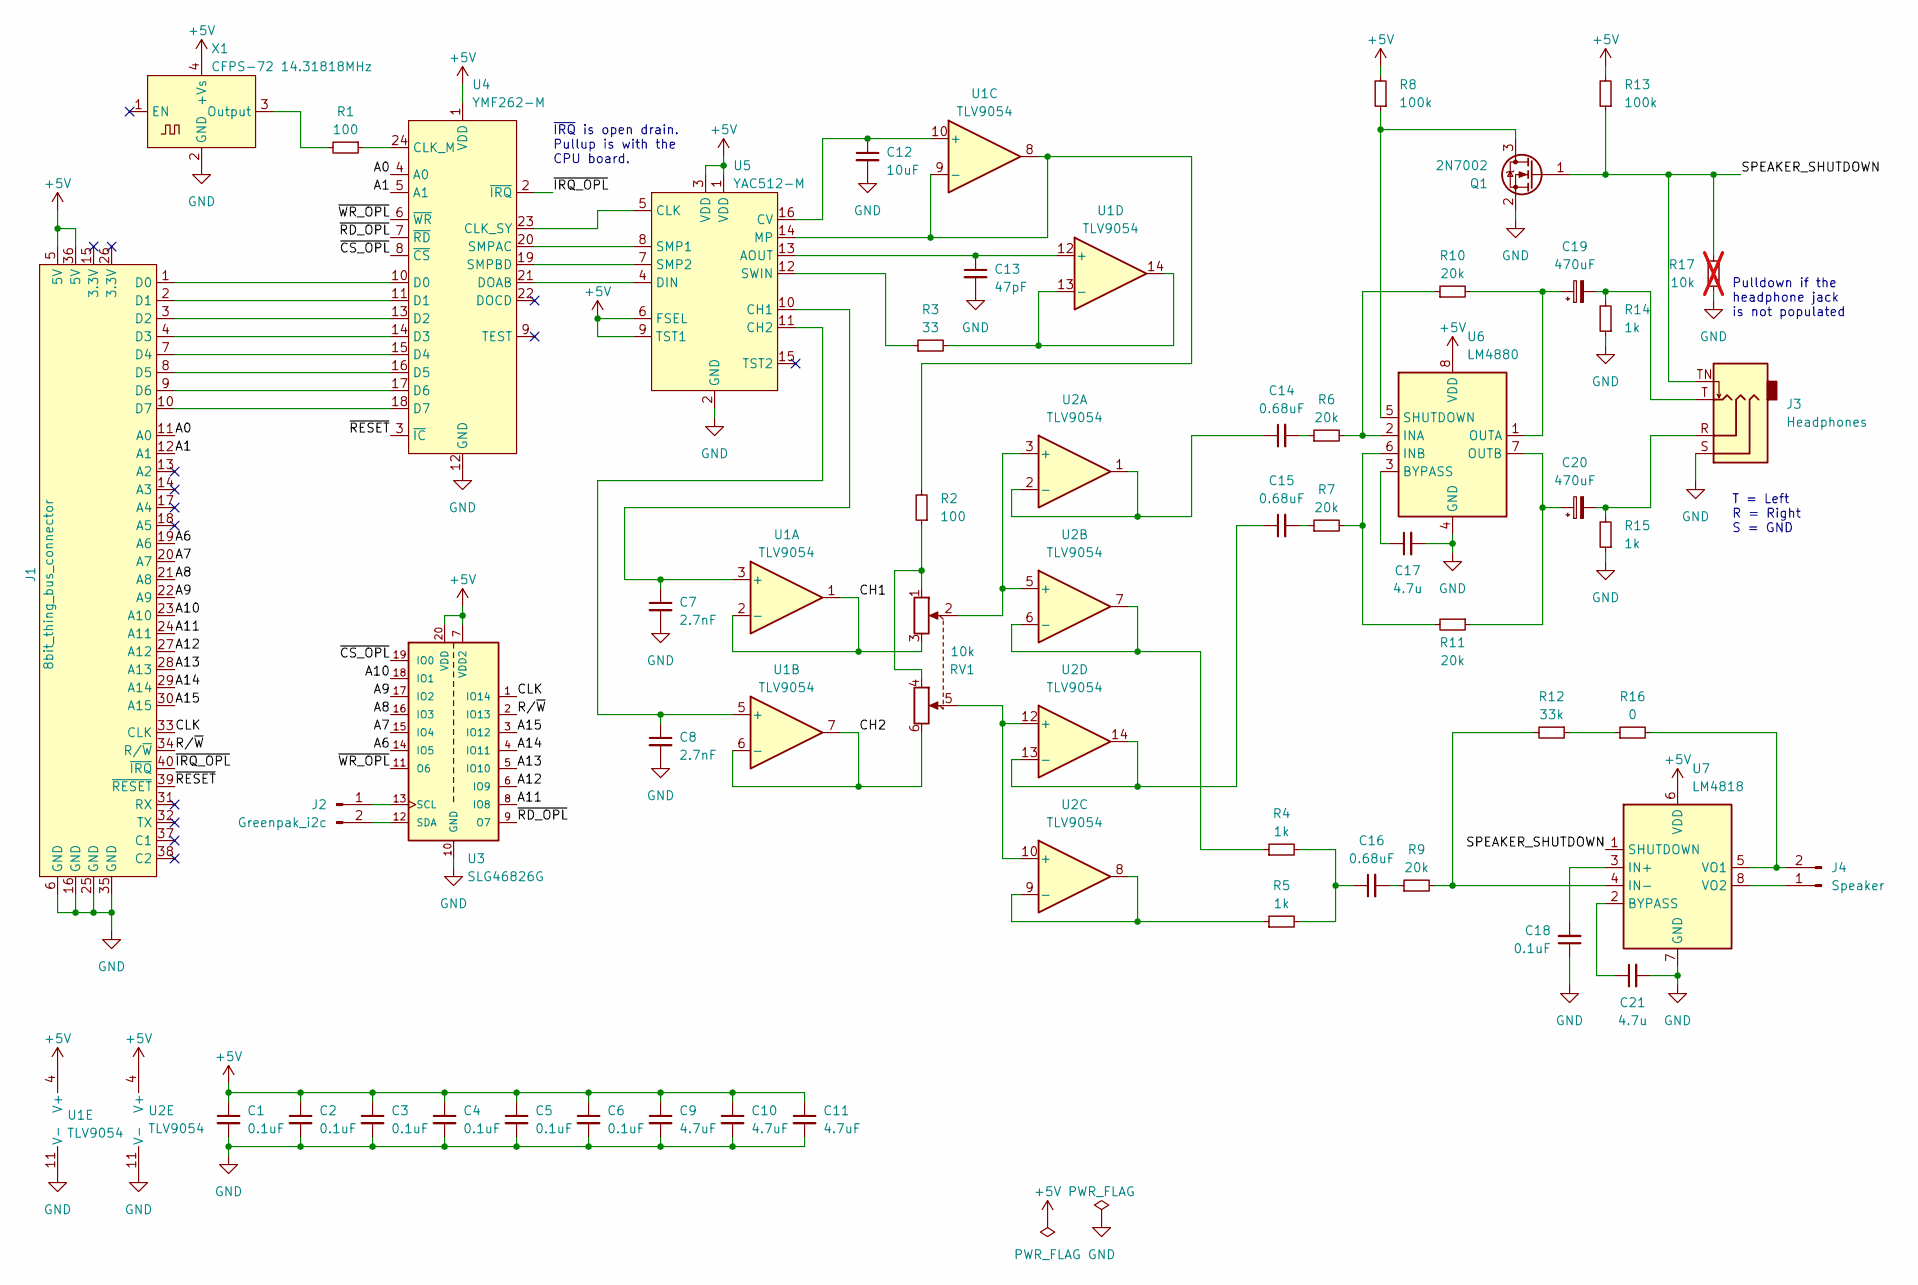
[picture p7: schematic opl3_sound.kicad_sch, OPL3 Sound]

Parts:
C1, C2, C3, C4, C5, C6, C18: 0.1uF; C_0805_2012Metric_Pad1.18x1.45mm_HandSolder
C7, C8: 2.7nF; C_0805_2012Metric_Pad1.18x1.45mm_HandSolder
C9, C10, C11: 4.7uF; C_0805_2012Metric_Pad1.18x1.45mm_HandSolder
C12: 10uF; C_0805_2012Metric_Pad1.18x1.45mm_HandSolder
C13: 47pF; C_0805_2012Metric_Pad1.18x1.45mm_HandSolder
C14, C15, C16: 0.68uF; C_Rect_L7.2mm_W4.5mm_P5.00mm_FKS2_FKP2_MKS2_MKP2
C17, C21: 4.7u; C_0805_2012Metric_Pad1.18x1.45mm_HandSolder
C19, C20: 470uF; CP_Radial_D8.0mm_P3.50mm
J1: 8bit_thing_bus_connector; IDC-Header_2x20_P2.54mm_Horizontal
J2: Greenpak_i2c; PinHeader_1x02_P2.54mm_Vertical_minimal
J3: Headphones; Jack_3.5mm_CUI_SJ-3524-SMT_Horizontal
J4: Speaker; PinHeader_1x02_P2.54mm_Horizontal
Q1: 2N7002; SOT-23_Handsoldering
R1, R2: 100; R_0805_2012Metric_Pad1.20x1.40mm_HandSolder
R3: 33; R_0805_2012Metric_Pad1.20x1.40mm_HandSolder
R4, R5, R14, R15: 1k; R_0805_2012Metric_Pad1.20x1.40mm_HandSolder
R6, R7, R9, R10, R11: 20k; R_0805_2012Metric_Pad1.20x1.40mm_HandSolder
R8, R13: 100k; R_0805_2012Metric_Pad1.20x1.40mm_HandSolder
R12: 33k; R_0805_2012Metric_Pad1.20x1.40mm_HandSolder
R16: 0; R_0805_2012Metric_Pad1.20x1.40mm_HandSolder
R17: 10k; R_0805_2012Metric_Pad1.20x1.40mm_HandSolder; not fitted
RV1: 10k; PTD9022015KA104
U1, U2: TLV9054; SOIC-14_3.9x8.7mm_P1.27mm
U3: SLG46826G; SOP65P640X120-20N; PARTREV 3.10
U4: YMF262-M; SOP-24_8.4x15.5mm_P1.27mm
U5: YAC512-M; SOIC-16W_5.3x10.2mm_P1.27mm
U6: LM4880; SOIC-8_3.9x4.9mm_P1.27mm
U7: LM4818; SOIC-8_3.9x4.9mm_P1.27mm
X1: CFPS-72 14.31818MHz; Oscillator_SMD_IQD_IQXO70-4Pin_7.5x5.0mm_HandSoldering

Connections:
+5V: C1.1, C2.1, C3.1, C4.1, C5.1, C6.1, C9.1, C10.1, C11.1, J1.5 (5V), J1.36 (5V), R8.2, R13.2, U1.4 (V+), U2.4 (V+), U3.7 (VDD2), U3.20 (VDD), U4.1 (VDD), U5.1 (VDD), U5.3 (VDD), U5.6 (FSEL), U5.9 (TST1), U6.8 (VDD), U7.6 (VDD), X1.4 (+Vs)
/A0: J1.11 (A0), U4.4 (A0)
/A1: J1.12 (A1), U4.5 (A1)
/A6: J1.19 (A6), U3.14 (IO5)
/A7: J1.20 (A7), U3.15 (IO4)
/A8: J1.21 (A8), U3.16 (IO3)
/A9: J1.22 (A9), U3.17 (IO2)
/A10: J1.23 (A10), U3.18 (IO1)
/A11: J1.24 (A11), U3.8 (IO8)
/A12: J1.27 (A12), U3.6 (IO9)
/A13: J1.28 (A13), U3.5 (IO10)
/A14: J1.29 (A14), U3.4 (IO11)
/A15: J1.30 (A15), U3.3 (IO12)
/CH1: RV1.3, U1.1, U1.2 (-)
/CH2: RV1.6, U1.6 (-), U1.7
/CLK: J1.33 (CLK), U3.1 (IO14)
/R/~W: J1.34 (R/~W), U3.2 (IO13)
/SPEAKER_SHUTDOWN: J3.TN, Q1.1 (G), R13.1, R17.1, U7.1 (SHUTDOWN)
/~CS_OPL: U3.19 (IO0), U4.8 (~CS)
/~IRQ_OPL: J1.40 (~IRQ), U4.2 (~IRQ)
/~RD_OPL: U3.9 (O7), U4.7 (~RD)
/~RESET: J1.39 (~RESET), U4.3 (~IC)
/~WR_OPL: U3.11 (O6), U4.6 (~WR)
GND: C1.2, C2.2, C3.2, C4.2, C5.2, C6.2, C7.2, C8.2, C9.2, C10.2, C11.2, C12.2, C13.2, C17.2, C18.1, C21.2, J1.6 (GND), J1.16 (GND), J1.25 (GND), J1.35 (GND), J3.S, Q1.2 (S), R14.1, R15.1, R17.2, U1.11 (V-), U2.11 (V-), U3.10 (GND), U4.12 (GND), U5.2 (GND), U6.4 (GND), U7.7 (GND), X1.2 (GND)
unnamed: C14.2, R6.1
unnamed: C15.2, R7.1
unnamed: C16.1, R4.2, R5.2
unnamed: C16.2, R9.1
unnamed: C19.2, J3.T, R14.2
unnamed: C20.2, J3.R, R15.2
unnamed: J1.1 (D0), U4.10 (D0)
unnamed: J1.2 (D1), U4.11 (D1)
unnamed: J1.3 (D2), U4.13 (D2)
unnamed: J1.4 (D3), U4.14 (D3)
unnamed: J1.7 (D4), U4.15 (D4)
unnamed: J1.8 (D5), U4.16 (D5)
unnamed: J1.9 (D6), U4.17 (D6)
unnamed: J1.10 (D7), U4.18 (D7)
unnamed: J2.1, U3.13 (SCL)
unnamed: J2.2, U3.12 (SDA)
unnamed: J4.1, U7.8 (VO2)
unnamed: J4.2, R16.2, U7.5 (VO1)
unnamed: Q1.3 (D), R8.1, U6.5 (SHUTDOWN)
unnamed: R2.1, RV1.1, RV1.4
unnamed: R12.1, R16.1
unnamed: C7.1, U1.3 (+), U5.10 (CH1)
unnamed: C8.1, U1.5 (+), U5.11 (CH2)
unnamed: C12.1, U1.10 (+), U5.16 (CV)
unnamed: R2.2, U1.8, U1.9 (-), U5.14 (MP)
unnamed: C13.1, U1.12 (+), U5.13 (AOUT)
unnamed: R3.2, U1.13 (-), U1.14
unnamed: RV1.2, U2.3 (+), U2.5 (+)
unnamed: C14.1, U2.1, U2.2 (-)
unnamed: R4.1, U2.6 (-), U2.7
unnamed: RV1.5, U2.10 (+), U2.12 (+)
unnamed: R5.1, U2.8, U2.9 (-)
unnamed: C15.1, U2.13 (-), U2.14
unnamed: R1.1, U4.24 (CLK_M)
unnamed: U4.23 (CLK_SY), U5.5 (CLK)
unnamed: U4.21 (DOAB), U5.4 (DIN)
unnamed: U4.20 (SMPAC), U5.8 (SMP1)
unnamed: U4.19 (SMPBD), U5.7 (SMP2)
unnamed: R3.1, U5.12 (SWIN)
unnamed: C17.1, U6.3 (BYPASS)
unnamed: R6.2, R10.1, U6.2 (INA)
unnamed: R7.2, R11.2, U6.6 (INB)
unnamed: C19.1, R10.2, U6.1 (OUTA)
unnamed: C20.1, R11.1, U6.7 (OUTB)
unnamed: C21.1, U7.2 (BYPASS)
unnamed: C18.2, U7.3 (IN+)
unnamed: R9.2, R12.2, U7.4 (IN-)
unnamed: R1.2, X1.3 (Output)

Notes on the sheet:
Pulldown if the headphone jack is not populated
~{IRQ} is open drain. Pullup is with the CPU board.
T = Left R = Right S = GND

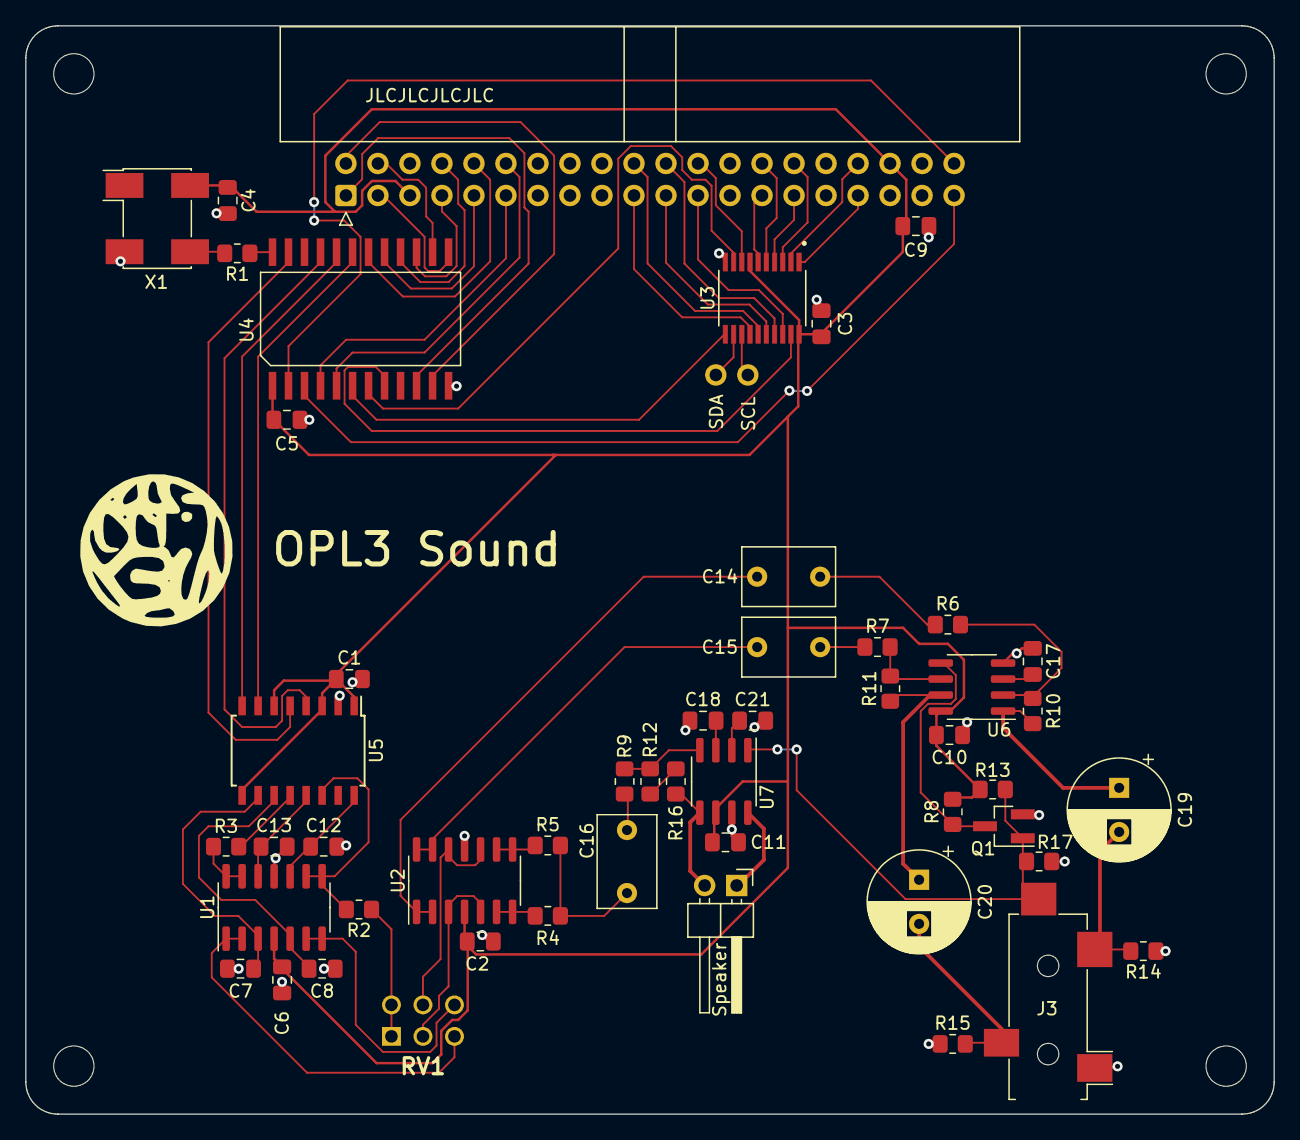
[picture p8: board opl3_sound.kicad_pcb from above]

Board: 2 copper layers, 99.1 x 86.4 mm, 52 parts (0 on the bottom side), 72 nets.

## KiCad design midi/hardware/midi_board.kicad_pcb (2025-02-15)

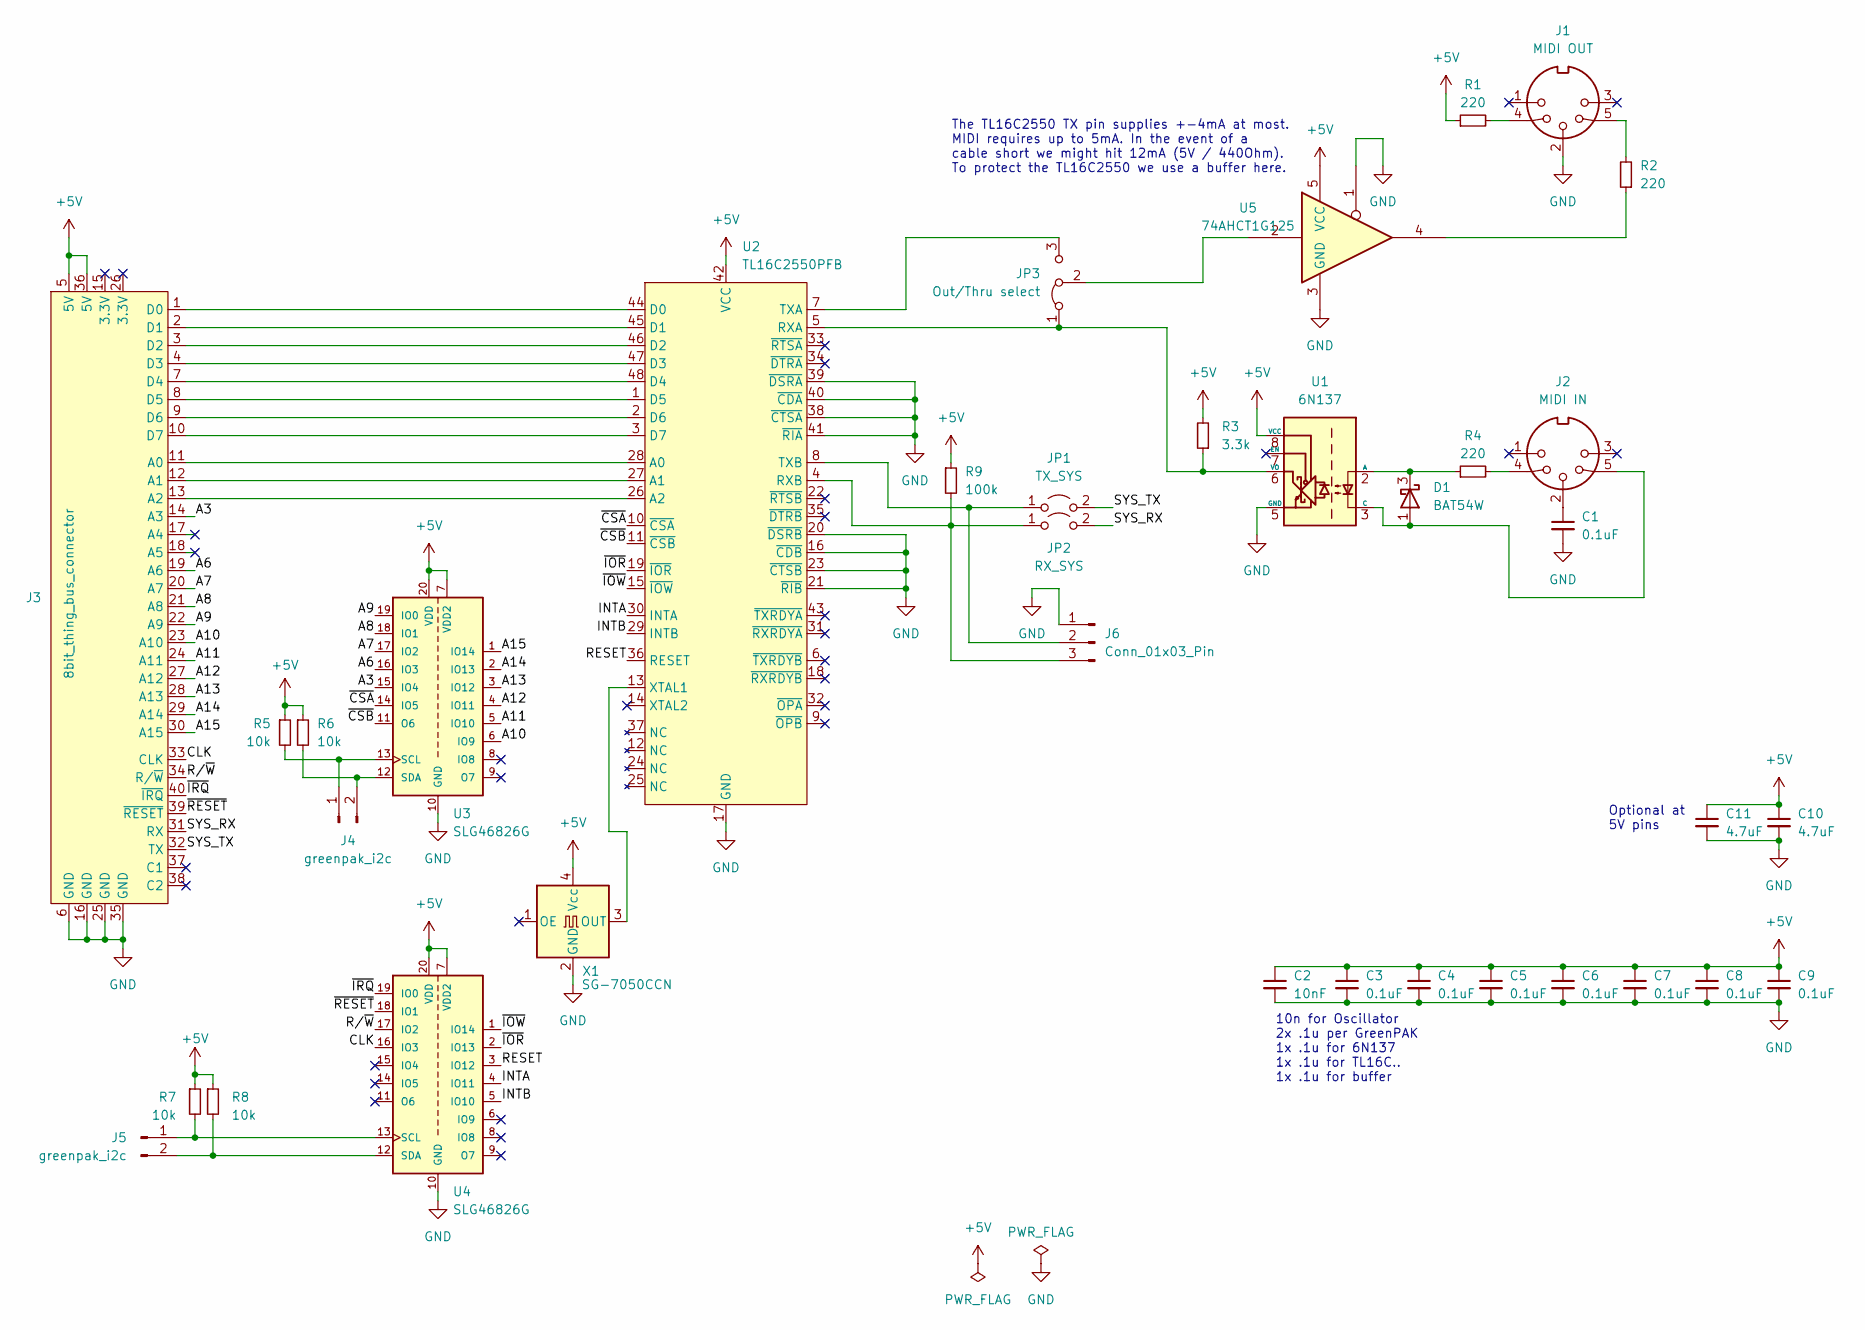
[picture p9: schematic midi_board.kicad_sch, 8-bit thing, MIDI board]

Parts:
C1, C3, C4, C5, C6, C7, C8, C9: 0.1uF; C_0805_2012Metric_Pad1.18x1.45mm_HandSolder
C2: 10nF; C_0805_2012Metric_Pad1.18x1.45mm_HandSolder
C10, C11: 4.7uF; C_0805_2012Metric_Pad1.18x1.45mm_HandSolder
D1: BAT54W; SOT-323_SC-70_Handsoldering
J1: MIDI OUT; Kycon-KCDX-5S-N
J2: MIDI IN; Kycon-KCDX-5S-N
J3: 8bit_thing_bus_connector; IDC-Header_2x20_P2.54mm_Horizontal
J4, J5: greenpak_i2c; PinHeader_1x02_P2.54mm_Vertical_minimal
J6: Conn_01x03_Pin; PinHeader_1x03_P2.54mm_Horizontal
JP1: TX_SYS; PinHeader_1x02_P2.54mm_Vertical_minimal
JP2: RX_SYS; PinHeader_1x02_P2.54mm_Vertical_minimal
JP3: Out/Thru select; PinHeader_1x03_P2.54mm_2_options_jumper_reverse
R1, R2: 220; R_0805_2012Metric_Pad1.20x1.40mm_HandSolder
R3: 3.3k; R_0805_2012Metric_Pad1.20x1.40mm_HandSolder
R4: 220; C_0805_2012Metric_Pad1.18x1.45mm_HandSolder
R5, R6, R7, R8: 10k; R_0805_2012Metric_Pad1.20x1.40mm_HandSolder
R9: 100k; R_0805_2012Metric_Pad1.20x1.40mm_HandSolder
U1: 6N137; DIP-8_W7.62mm
U2: TL16C2550PFB; TQFP-48_7x7mm_P0.5mm
U3, U4: SLG46826G; SOP65P640X120-20N; PARTREV 3.10
U5: 74AHCT1G125; SOT-353_SC-70-5_Handsoldering
X1: SG-7050CCN; Oscillator_SMD_SeikoEpson_SG8002CA-4Pin_7.0x5.0mm

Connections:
+5V: C2.1, C3.1, C4.1, C5.1, C6.1, C7.1, C8.1, C9.1, C10.1, C11.1, J3.5 (5V), J3.36 (5V), R1.1, R3.2, R5.1, R6.1, R7.1, R8.1, R9.1, U1.8 (VCC), U2.42 (VCC), U3.7 (VDD2), U3.20 (VDD), U4.7 (VDD2), U4.20 (VDD), U5.5 (VCC), X1.4 (Vcc)
/A3: J3.14 (A3), U3.15 (IO4)
/A6: J3.19 (A6), U3.16 (IO3)
/A7: J3.20 (A7), U3.17 (IO2)
/A8: J3.21 (A8), U3.18 (IO1)
/A9: J3.22 (A9), U3.19 (IO0)
/A10: J3.23 (A10), U3.6 (IO9)
/A11: J3.24 (A11), U3.5 (IO10)
/A12: J3.27 (A12), U3.4 (IO11)
/A13: J3.28 (A13), U3.3 (IO12)
/A14: J3.29 (A14), U3.2 (IO13)
/A15: J3.30 (A15), U3.1 (IO14)
/CLK: J3.33 (CLK), U4.16 (IO3)
/INTA: U2.30 (INTA), U4.4 (IO11)
/INTB: U2.29 (INTB), U4.5 (IO10)
/RESET: U2.36 (RESET), U4.3 (IO12)
/R/~W: J3.34 (R/~W), U4.17 (IO2)
/SYS_RX: J3.31 (RX), JP2.2 (B)
/SYS_TX: J3.32 (TX), JP1.2 (B)
/~CSA: U2.10 (~CSA), U3.14 (IO5)
/~CSB: U2.11 (~CSB), U3.11 (O6)
/~IOR: U2.19 (~IOR), U4.2 (IO13)
/~IOW: U2.15 (~IOW), U4.1 (IO14)
/~IRQ: J3.40 (~IRQ), U4.19 (IO0)
/~RESET: J3.39 (~RESET), U4.18 (IO1)
GND: C1.2, C2.2, C3.2, C4.2, C5.2, C6.2, C7.2, C8.2, C9.2, C10.2, C11.2, J1.2, J3.6 (GND), J3.16 (GND), J3.25 (GND), J3.35 (GND), J6.1, U1.5 (GND), U2.16 (~CDB), U2.17 (GND), U2.20 (~DSRB), U2.21 (~RIB), U2.23 (~CTSB), U2.38 (~CTSA), U2.39 (~DSRA), U2.40 (~CDA), U2.41 (~RIA), U3.10 (GND), U4.10 (GND), U5.1, U5.3 (GND), X1.2 (GND)
unnamed: C1.1, J2.2
unnamed: D1.1 (A), J2.5, U1.3 (C)
unnamed: D1.3 (K), R4.1, U1.2 (A)
unnamed: J1.4, R1.2
unnamed: J1.5, R2.2
unnamed: J2.4, R4.2
unnamed: J3.11 (A0), U2.28 (A0)
unnamed: J3.12 (A1), U2.27 (A1)
unnamed: J3.13 (A2), U2.26 (A2)
unnamed: J3.1 (D0), U2.44 (D0)
unnamed: J3.2 (D1), U2.45 (D1)
unnamed: J3.3 (D2), U2.46 (D2)
unnamed: J3.4 (D3), U2.47 (D3)
unnamed: J3.7 (D4), U2.48 (D4)
unnamed: J3.8 (D5), U2.1 (D5)
unnamed: J3.9 (D6), U2.2 (D6)
unnamed: J3.10 (D7), U2.3 (D7)
unnamed: J4.1, R5.2, U3.13 (SCL)
unnamed: J4.2, R6.2, U3.12 (SDA)
unnamed: J5.1, R7.2, U4.13 (SCL)
unnamed: J5.2, R8.2, U4.12 (SDA)
unnamed: J6.2, JP1.1 (A), U2.8 (TXB)
unnamed: J6.3, JP2.1 (A), R9.2, U2.4 (RXB)
unnamed: JP3.1 (A), R3.1, U1.6 (VO), U2.5 (RXA)
unnamed: JP3.3 (B), U2.7 (TXA)
unnamed: JP3.2 (C), U5.2
unnamed: R2.1, U5.4
unnamed: U2.13 (XTAL1), X1.3 (OUT)

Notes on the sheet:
The TL16C2550 TX pin supplies +-4mA at most. MIDI requires up to 5mA. In the event of a cable short we might hit 12mA (5V / 440Ohm). To protect the TL16C2550 we use a buffer here.
10n for Oscillator 2x .1u per GreenPAK 1x .1u for 6N137 1x .1u for TL16C.. 1x .1u for buffer
Optional at 5V pins

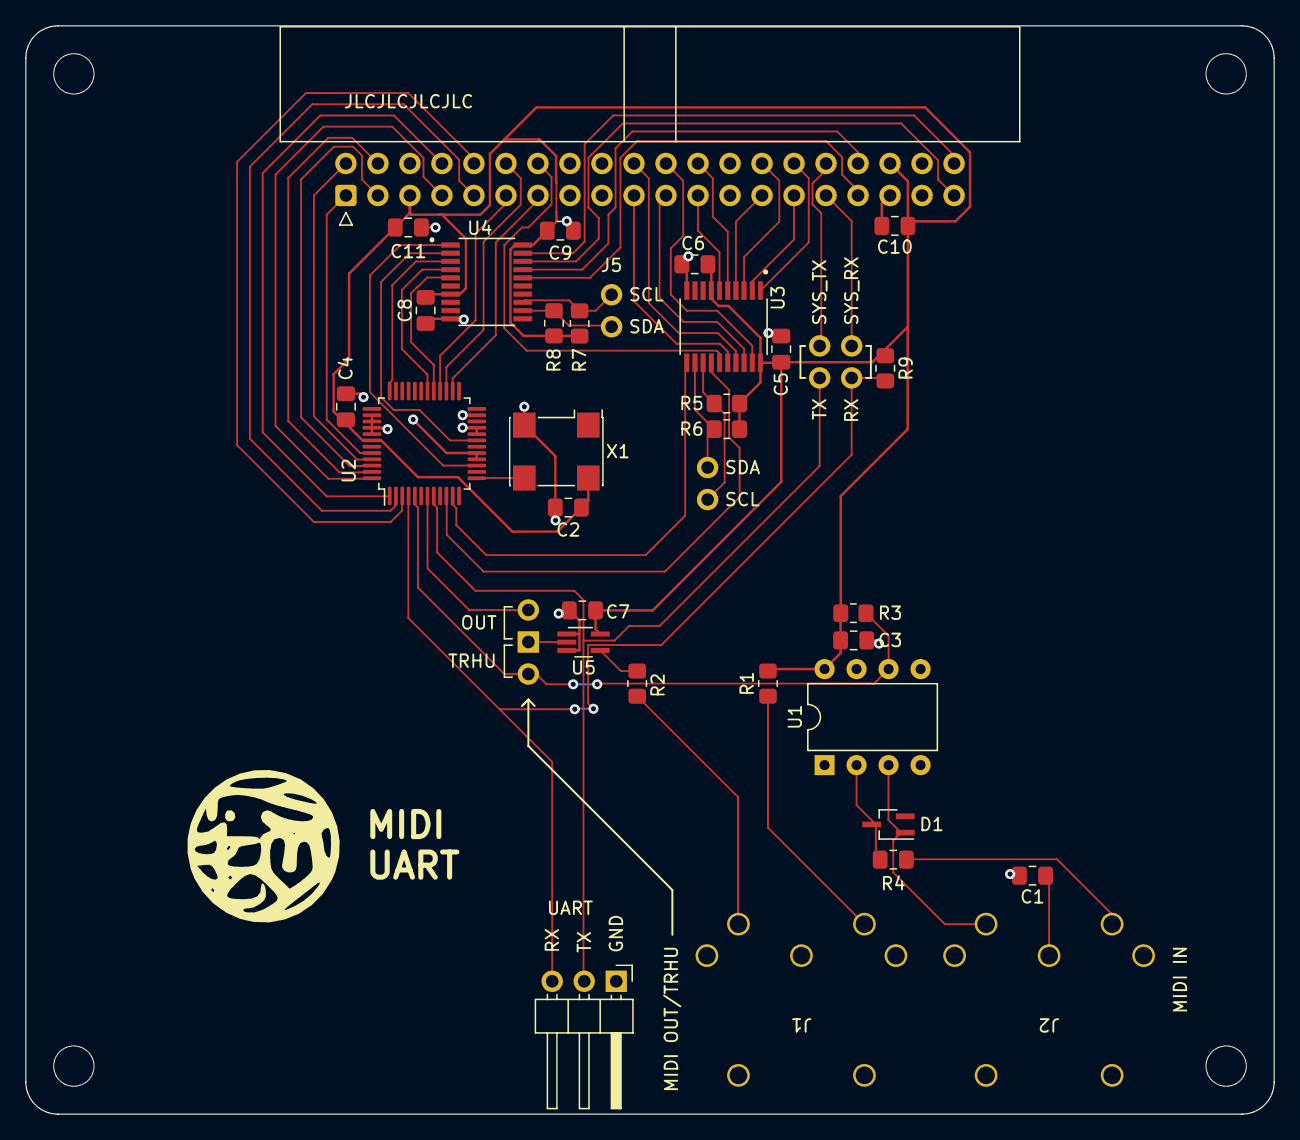
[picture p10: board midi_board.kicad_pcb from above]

Board: 2 copper layers, 99.1 x 86.4 mm, 36 parts (0 on the bottom side), 54 nets.

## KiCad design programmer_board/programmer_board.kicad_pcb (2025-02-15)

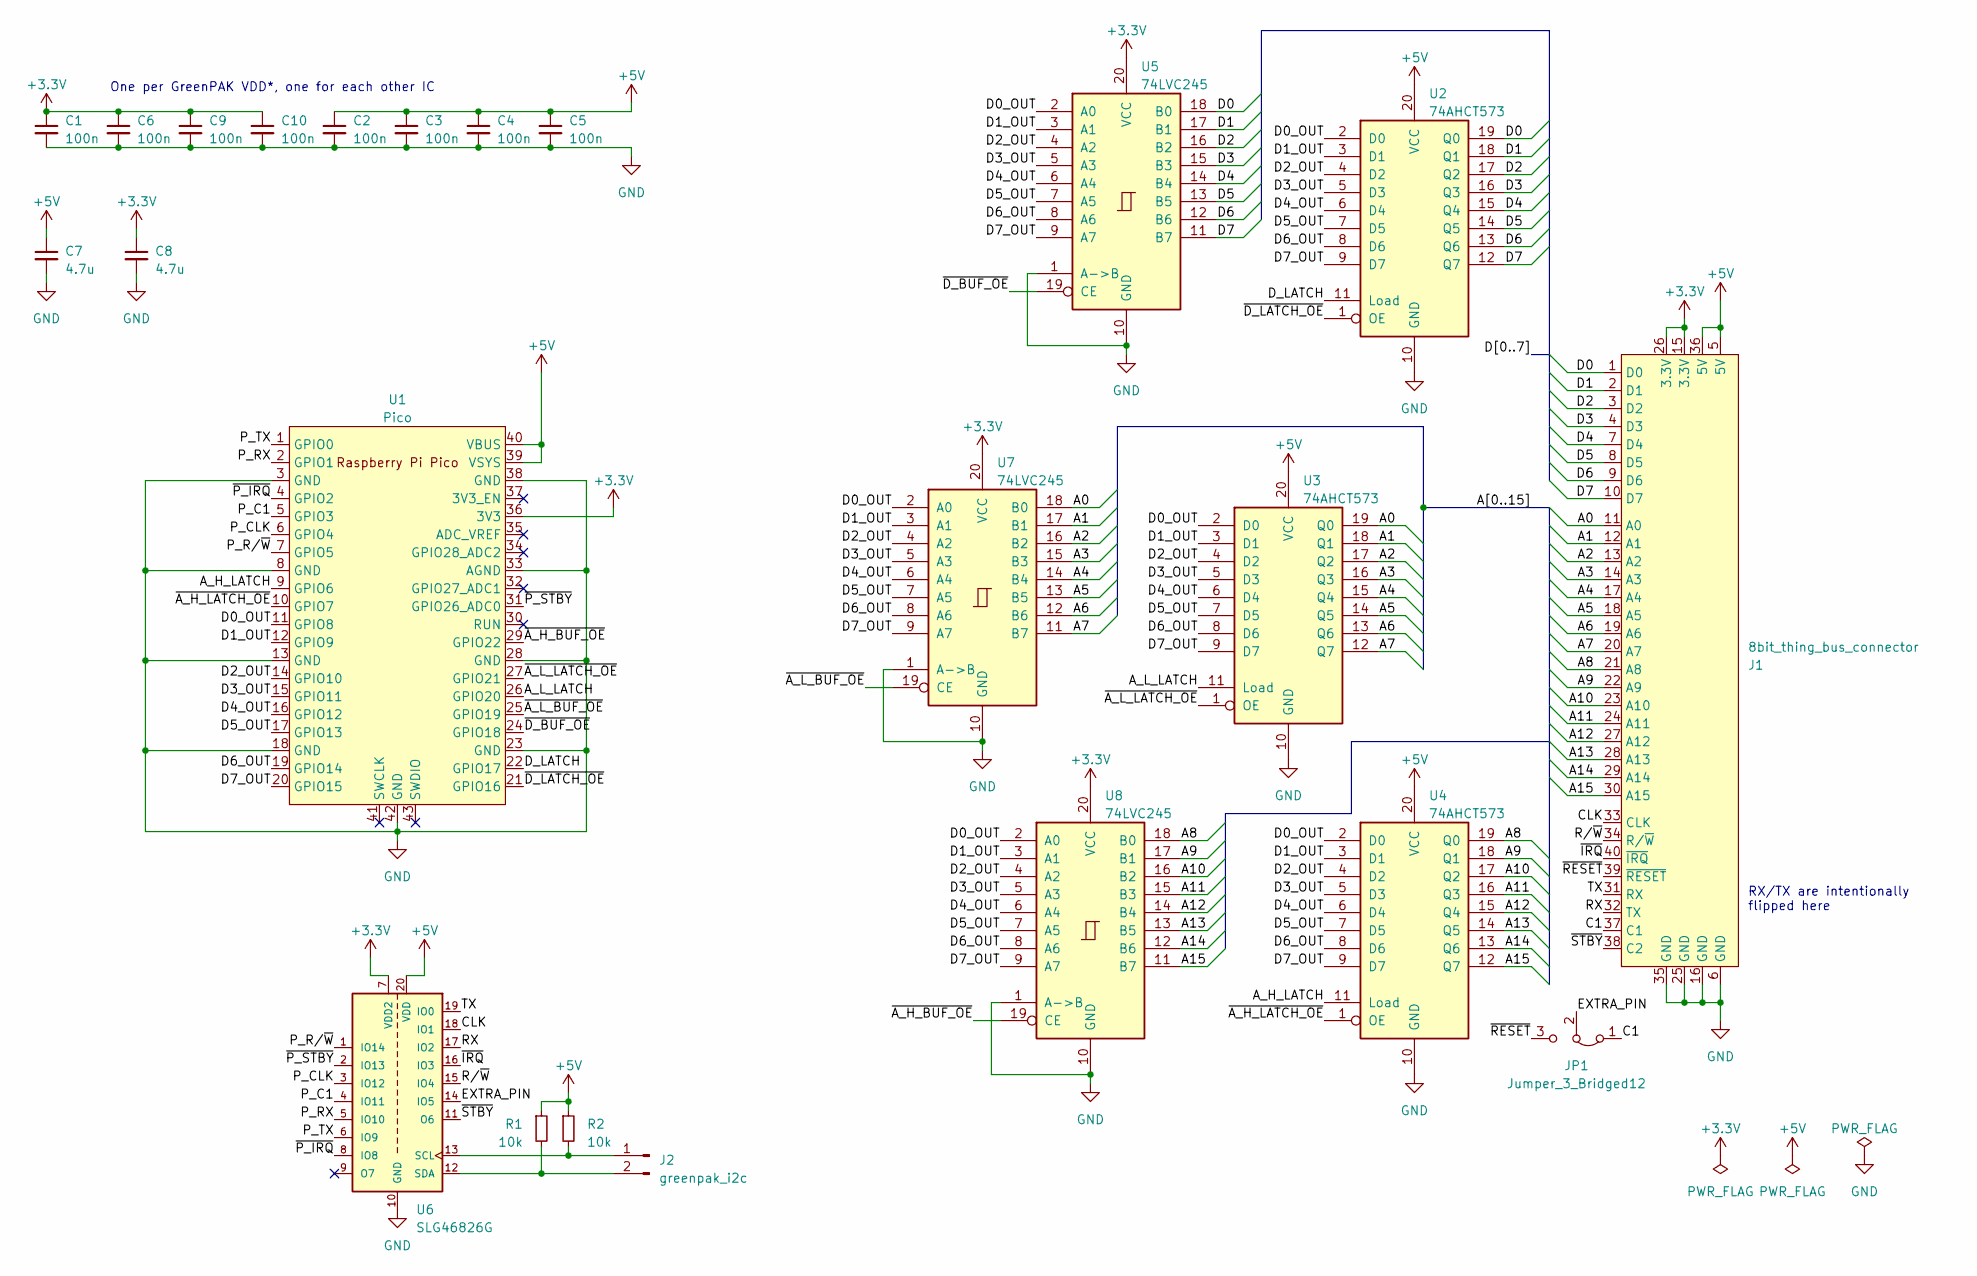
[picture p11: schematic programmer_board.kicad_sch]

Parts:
C1, C2, C3, C4, C5, C6, C9, C10: 100n; C_0805_2012Metric_Pad1.18x1.45mm_HandSolder
C7, C8: 4.7u; C_0805_2012Metric_Pad1.18x1.45mm_HandSolder
J1: 8bit_thing_bus_connector; IDC-Header_2x20_P2.54mm_Horizontal
J2: greenpak_i2c; PinHeader_1x02_P2.54mm_Vertical_minimal
JP1: Jumper_3_Bridged12; PinHeader_1x03_P2.54mm_Vertical
R1, R2: 10k; R_0805_2012Metric_Pad1.20x1.40mm_HandSolder
U1: Pico; RPi_Pico_SMD_TH
U2, U3, U4: 74AHCT573; SSOP-20_5.3x7.2mm_P0.65mm
U5, U7, U8: 74LVC245; TSSOP-20_4.4x6.5mm_P0.65mm
U6: SLG46826G; SOP65P640X120-20N; PARTREV 3.10

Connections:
+3.3V: C1.1, C6.1, C8.1, C9.1, C10.1, J1.15 (3.3V), J1.26 (3.3V), U1.36 (3V3), U5.20 (VCC), U6.7 (VDD2), U7.20 (VCC), U8.20 (VCC)
+5V: C2.1, C3.1, C4.1, C5.1, C7.1, J1.5 (5V), J1.36 (5V), R1.1, R2.1, U1.39 (VSYS), U1.40 (VBUS), U2.20 (VCC), U3.20 (VCC), U4.20 (VCC), U6.20 (VDD)
/A0: J1.11 (A0), U3.19 (Q0), U7.18 (B0)
/A1: J1.12 (A1), U3.18 (Q1), U7.17 (B1)
/A2: J1.13 (A2), U3.17 (Q2), U7.16 (B2)
/A3: J1.14 (A3), U3.16 (Q3), U7.15 (B3)
/A4: J1.17 (A4), U3.15 (Q4), U7.14 (B4)
/A5: J1.18 (A5), U3.14 (Q5), U7.13 (B5)
/A6: J1.19 (A6), U3.13 (Q6), U7.12 (B6)
/A7: J1.20 (A7), U3.12 (Q7), U7.11 (B7)
/A8: J1.21 (A8), U4.19 (Q0), U8.18 (B0)
/A9: J1.22 (A9), U4.18 (Q1), U8.17 (B1)
/A10: J1.23 (A10), U4.17 (Q2), U8.16 (B2)
/A11: J1.24 (A11), U4.16 (Q3), U8.15 (B3)
/A12: J1.27 (A12), U4.15 (Q4), U8.14 (B4)
/A13: J1.28 (A13), U4.14 (Q5), U8.13 (B5)
/A14: J1.29 (A14), U4.13 (Q6), U8.12 (B6)
/A15: J1.30 (A15), U4.12 (Q7), U8.11 (B7)
/A_H_LATCH: U1.9 (GPIO6), U4.11 (Load)
/A_L_LATCH: U1.26 (GPIO20), U3.11 (Load)
/C1: J1.37 (C1), JP1.1 (A)
/CLK: J1.33 (CLK), U6.18 (IO1)
/D0: J1.1 (D0), U2.19 (Q0), U5.18 (B0)
/D0_OUT: U1.11 (GPIO8), U2.2 (D0), U3.2 (D0), U4.2 (D0), U5.2 (A0), U7.2 (A0), U8.2 (A0)
/D1: J1.2 (D1), U2.18 (Q1), U5.17 (B1)
/D1_OUT: U1.12 (GPIO9), U2.3 (D1), U3.3 (D1), U4.3 (D1), U5.3 (A1), U7.3 (A1), U8.3 (A1)
/D2: J1.3 (D2), U2.17 (Q2), U5.16 (B2)
/D2_OUT: U1.14 (GPIO10), U2.4 (D2), U3.4 (D2), U4.4 (D2), U5.4 (A2), U7.4 (A2), U8.4 (A2)
/D3: J1.4 (D3), U2.16 (Q3), U5.15 (B3)
/D3_OUT: U1.15 (GPIO11), U2.5 (D3), U3.5 (D3), U4.5 (D3), U5.5 (A3), U7.5 (A3), U8.5 (A3)
/D4: J1.7 (D4), U2.15 (Q4), U5.14 (B4)
/D4_OUT: U1.16 (GPIO12), U2.6 (D4), U3.6 (D4), U4.6 (D4), U5.6 (A4), U7.6 (A4), U8.6 (A4)
/D5: J1.8 (D5), U2.14 (Q5), U5.13 (B5)
/D5_OUT: U1.17 (GPIO13), U2.7 (D5), U3.7 (D5), U4.7 (D5), U5.7 (A5), U7.7 (A5), U8.7 (A5)
/D6: J1.9 (D6), U2.13 (Q6), U5.12 (B6)
/D6_OUT: U1.19 (GPIO14), U2.8 (D6), U3.8 (D6), U4.8 (D6), U5.8 (A6), U7.8 (A6), U8.8 (A6)
/D7: J1.10 (D7), U2.12 (Q7), U5.11 (B7)
/D7_OUT: U1.20 (GPIO15), U2.9 (D7), U3.9 (D7), U4.9 (D7), U5.9 (A7), U7.9 (A7), U8.9 (A7)
/D_LATCH: U1.22 (GPIO17), U2.11 (Load)
/EXTRA_PIN: JP1.2 (C), U6.14 (IO5)
/P_C1: U1.5 (GPIO3), U6.4 (IO11)
/P_CLK: U1.6 (GPIO4), U6.3 (IO12)
/P_RX: U1.2 (GPIO1), U6.5 (IO10)
/P_R/~W: U1.7 (GPIO5), U6.1 (IO14)
/P_TX: U1.1 (GPIO0), U6.6 (IO9)
/RX: J1.32 (TX), U6.17 (IO2)
/R/~W: J1.34 (R/~W), U6.15 (IO4)
/TX: J1.31 (RX), U6.19 (IO0)
/~A_H_BUF_OE: U1.29 (GPIO22), U8.19 (CE)
/~A_H_LATCH_OE: U1.10 (GPIO7), U4.1 (OE)
/~A_L_BUF_OE: U1.25 (GPIO19), U7.19 (CE)
/~A_L_LATCH_OE: U1.27 (GPIO21), U3.1 (OE)
/~D_BUF_OE: U1.24 (GPIO18), U5.19 (CE)
/~D_LATCH_OE: U1.21 (GPIO16), U2.1 (OE)
/~IRQ: J1.40 (~IRQ), U6.16 (IO3)
/~P_IRQ: U1.4 (GPIO2), U6.8 (IO8)
/~P_STBY: U1.31 (GPIO26_ADC0), U6.2 (IO13)
/~RESET: J1.39 (~RESET), JP1.3 (B)
/~STBY: J1.38 (C2), U6.11 (O6)
GND: C1.2, C2.2, C3.2, C4.2, C5.2, C6.2, C7.2, C8.2, C9.2, C10.2, J1.6 (GND), J1.16 (GND), J1.25 (GND), J1.35 (GND), U1.3 (GND), U1.8 (GND), U1.13 (GND), U1.18 (GND), U1.23 (GND), U1.28 (GND), U1.33 (AGND), U1.38 (GND), U1.42 (GND), U2.10 (GND), U3.10 (GND), U4.10 (GND), U5.1 (A->B), U5.10 (GND), U6.10 (GND), U7.1 (A->B), U7.10 (GND), U8.1 (A->B), U8.10 (GND)
unnamed: J2.1, R2.2, U6.13 (SCL)
unnamed: J2.2, R1.2, U6.12 (SDA)

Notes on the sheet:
RX/TX are intentionally flipped here
One per GreenPAK VDD*, one for each other IC

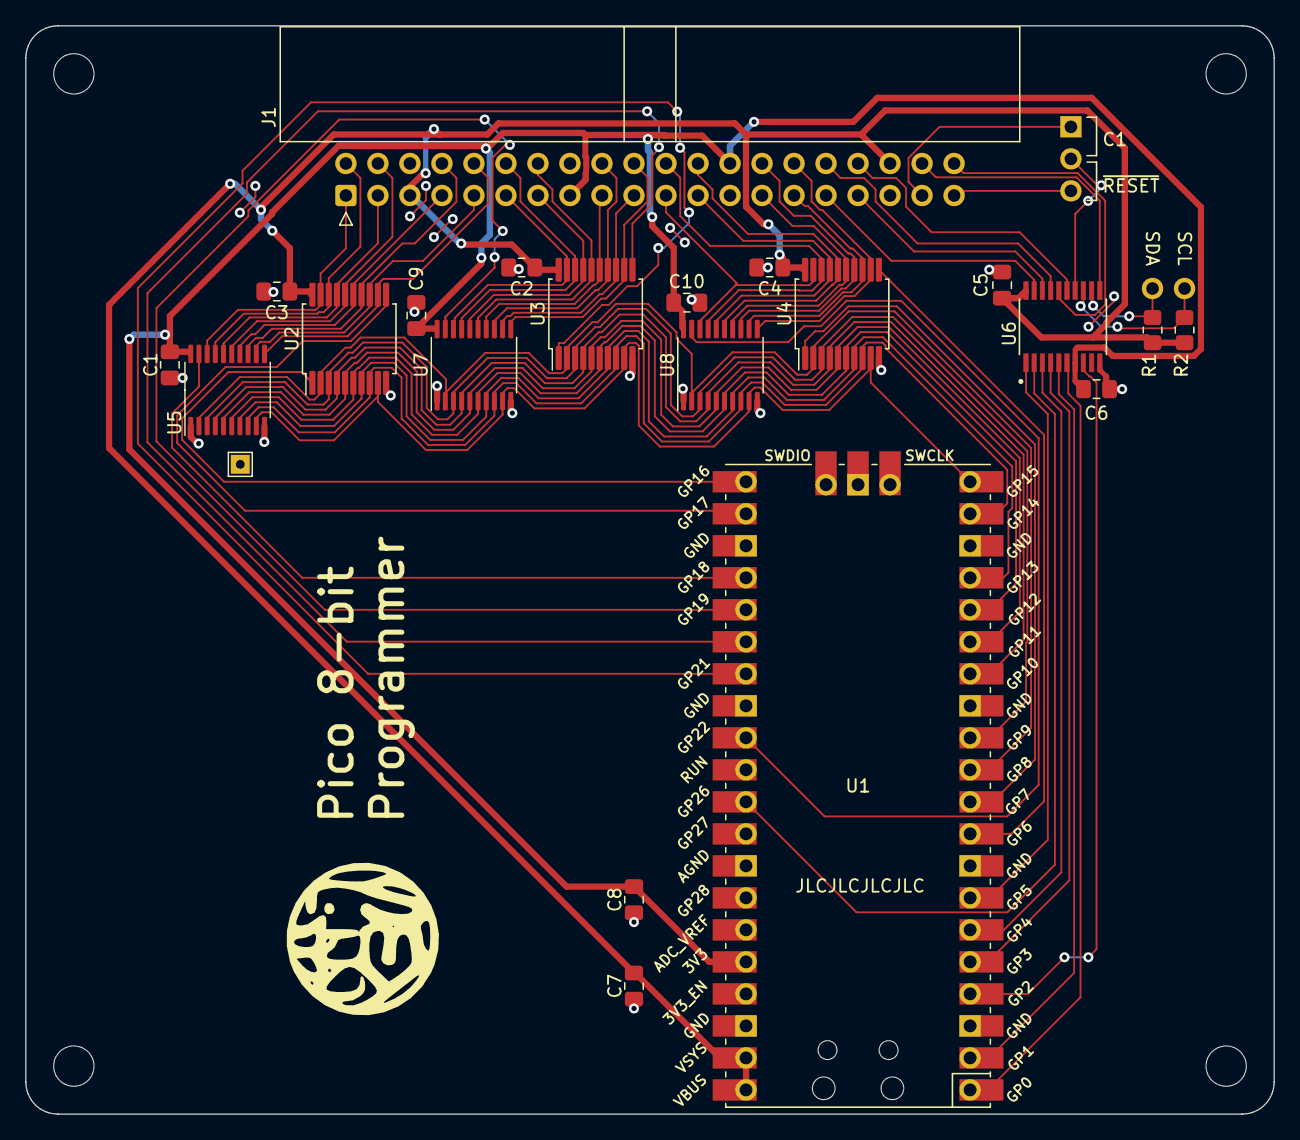
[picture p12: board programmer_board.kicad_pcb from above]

Board: 2 copper layers, 99.1 x 86.4 mm, 23 parts (0 on the bottom side), 62 nets.

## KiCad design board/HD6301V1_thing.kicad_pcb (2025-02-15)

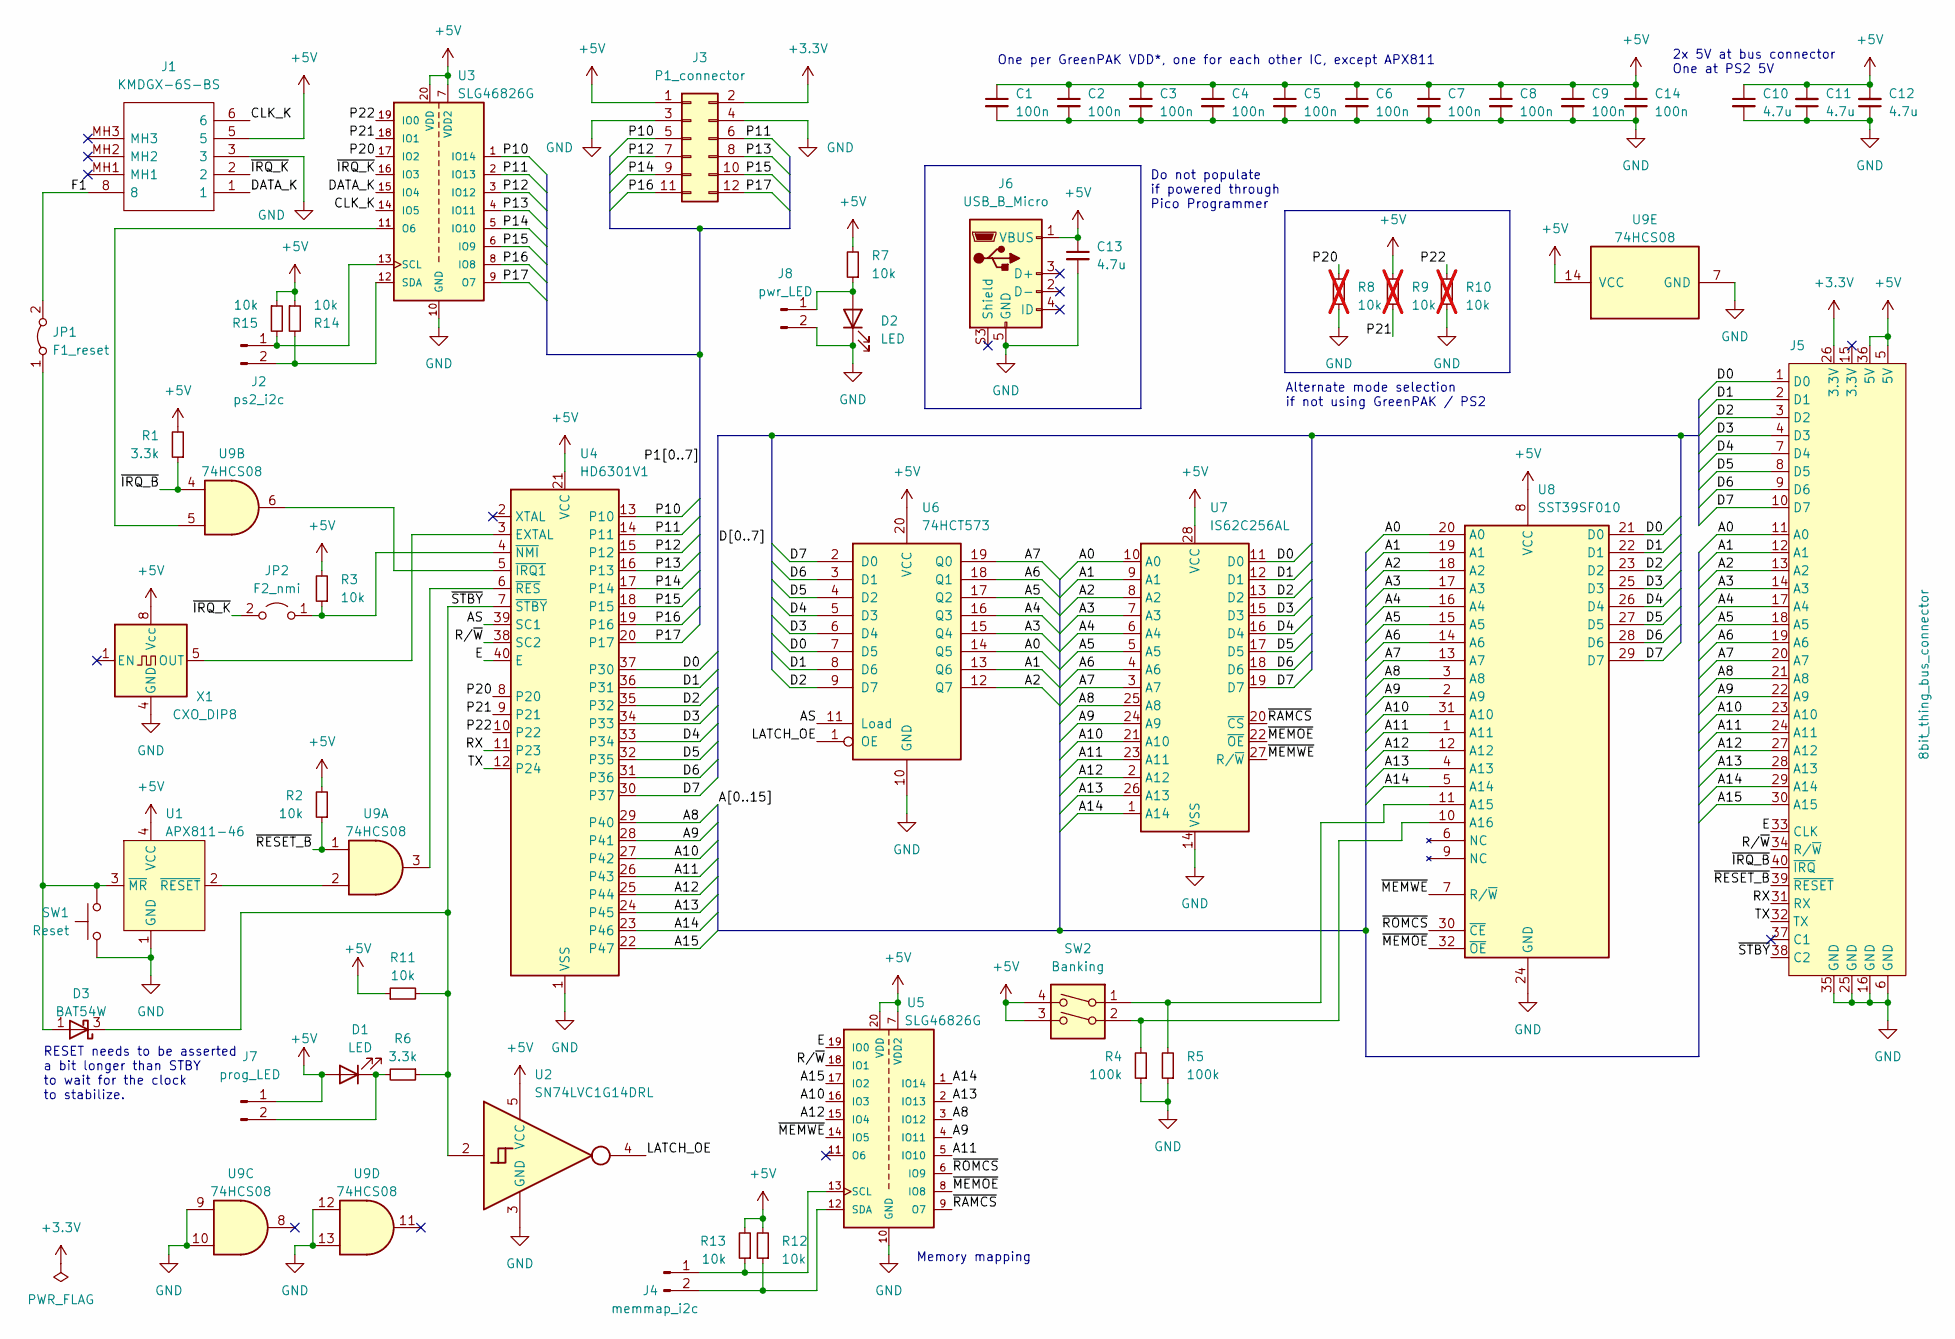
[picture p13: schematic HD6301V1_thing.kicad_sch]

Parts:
C1, C2, C3, C4, C5, C6, C7, C8, C9, C14: 100n; C_0805_2012Metric_Pad1.18x1.45mm_HandSolder
C10, C11, C12, C13: 4.7u; C_0805_2012Metric_Pad1.18x1.45mm_HandSolder
D1, D2: LED; LED_0805_2012Metric_Pad1.15x1.40mm_HandSolder
D3: BAT54W; SOT-323_SC-70_Handsoldering
J1: KMDGX-6S-BS; KMDGX6SBS; Manufacturer_Part_Number KMDGX-6S-BS; Mouser Part Number 806-KMDGX-6S-BS
J2: ps2_i2c; PinHeader_1x02_P2.54mm_Vertical_minimal
J3: P1_connector; PinHeader_2x06_P2.54mm_Horizontal_no_graphics
J4: memmap_i2c; PinHeader_1x02_P2.54mm_Vertical_minimal
J5: 8bit_thing_bus_connector; IDC-Header_2x20_P2.54mm_Horizontal
J6: USB_B_Micro; AMPHENOL_10118194-0001LF_MICRO_USB_improved
J7: prog_LED; PinHeader_1x02_P2.54mm_Vertical_minimal
J8: pwr_LED; PinHeader_1x02_P2.54mm_Vertical_minimal
JP1: F1_reset; PinHeader_1x02_P2.54mm_Vertical_minimal
JP2: F2_nmi; PinHeader_1x02_P2.54mm_Vertical_minimal
R1, R6: 3.3k; R_0805_2012Metric_Pad1.20x1.40mm_HandSolder
R2, R3, R7, R11, R12, R13, R14, R15: 10k; R_0805_2012Metric_Pad1.20x1.40mm_HandSolder
R4, R5: 100k; R_0805_2012Metric_Pad1.20x1.40mm_HandSolder
R8, R9, R10: 10k; R_0805_2012Metric_Pad1.20x1.40mm_HandSolder; not fitted
SW1: Reset; SW_SPST_TL3305A
SW2: Banking; SW_DS04-254-1L-02BK
U1: APX811-46; SOT-143_Handsoldering
U2: SN74LVC1G14DRL; SOT-353_SC-70-5_Handsoldering
U3, U5: SLG46826G; SOP65P640X120-20N; PARTREV 3.10
U4: HD6301V1; DIP-40_W15.24mm_Socket
U6: 74HCT573; SOIC-20W_7.5x12.8mm_P1.27mm
U7: IS62C256AL; SOIC127P1210X305-28N
U8: SST39SF010; TSOP-I-32_12.4x8mm_P0.5mm
U9: 74HCS08; TSSOP-14_4.4x5mm_P0.65mm
X1: CXO_DIP8; Oscillator_DIP-8

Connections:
+3.3V: J3.2, J5.26 (3.3V)
+5V: C1.1, C2.1, C3.1, C4.1, C5.1, C6.1, C7.1, C8.1, C9.1, C10.1, C11.2, C12.2, C13.1, C14.1, D1.2 (A), J1.5, J3.1, J5.5 (5V), J5.36 (5V), J6.1 (VBUS), J7.1, R1.2, R2.2, R3.2, R7.2, R9.2, R11.1, R12.2, R13.2, R14.1, R15.1, SW2.3, SW2.4, U1.4 (VCC), U2.5 (VCC), U3.7 (VDD2), U3.20 (VDD), U4.21 (VCC), U5.7 (VDD2), U5.20 (VDD), U6.20 (VCC), U7.28 (VCC), U8.8 (VCC), U9.14 (VCC), X1.8 (Vcc)
/A0: J5.11 (A0), U6.14 (Q5), U7.10 (A0), U8.20 (A0)
/A1: J5.12 (A1), U6.13 (Q6), U7.9 (A1), U8.19 (A1)
/A2: J5.13 (A2), U6.12 (Q7), U7.8 (A2), U8.18 (A2)
/A3: J5.14 (A3), U6.15 (Q4), U7.7 (A3), U8.17 (A3)
/A4: J5.17 (A4), U6.16 (Q3), U7.6 (A4), U8.16 (A4)
/A5: J5.18 (A5), U6.17 (Q2), U7.5 (A5), U8.15 (A5)
/A6: J5.19 (A6), U6.18 (Q1), U7.4 (A6), U8.14 (A6)
/A7: J5.20 (A7), U6.19 (Q0), U7.3 (A7), U8.13 (A7)
/A8: J5.21 (A8), U4.29 (P40), U5.3 (IO12), U7.25 (A8), U8.3 (A8)
/A9: J5.22 (A9), U4.28 (P41), U5.4 (IO11), U7.24 (A9), U8.2 (A9)
/A10: J5.23 (A10), U4.27 (P42), U5.16 (IO3), U7.21 (A10), U8.31 (A10)
/A11: J5.24 (A11), U4.26 (P43), U5.5 (IO10), U7.23 (A11), U8.1 (A11)
/A12: J5.27 (A12), U4.25 (P44), U5.15 (IO4), U7.2 (A12), U8.12 (A12)
/A13: J5.28 (A13), U4.24 (P45), U5.2 (IO13), U7.26 (A13), U8.4 (A13)
/A14: J5.29 (A14), U4.23 (P46), U5.1 (IO14), U7.1 (A14), U8.5 (A14)
/A15: J5.30 (A15), U4.22 (P47), U5.17 (IO2)
/AS: U4.39 (SC1), U6.11 (Load)
/CLK_K: J1.6, U3.14 (IO5)
/D0: J5.1 (D0), U4.37 (P30), U6.7 (D5), U7.11 (D0), U8.21 (D0)
/D1: J5.2 (D1), U4.36 (P31), U6.8 (D6), U7.12 (D1), U8.22 (D1)
/D2: J5.3 (D2), U4.35 (P32), U6.9 (D7), U7.13 (D2), U8.23 (D2)
/D3: J5.4 (D3), U4.34 (P33), U6.6 (D4), U7.15 (D3), U8.25 (D3)
/D4: J5.7 (D4), U4.33 (P34), U6.5 (D3), U7.16 (D4), U8.26 (D4)
/D5: J5.8 (D5), U4.32 (P35), U6.4 (D2), U7.17 (D5), U8.27 (D5)
/D6: J5.9 (D6), U4.31 (P36), U6.3 (D1), U7.18 (D6), U8.28 (D6)
/D7: J5.10 (D7), U4.30 (P37), U6.2 (D0), U7.19 (D7), U8.29 (D7)
/DATA_K: J1.1, U3.15 (IO4)
/E: J5.33 (CLK), U4.40 (E), U5.19 (IO0)
/F1: J1.8, JP1.2 (B)
/LATCH_OE: U2.4, U6.1 (OE)
/P10: J3.5, U3.1 (IO14), U4.13 (P10)
/P11: J3.6, U3.2 (IO13), U4.14 (P11)
/P12: J3.7, U3.3 (IO12), U4.15 (P12)
/P13: J3.8, U3.4 (IO11), U4.16 (P13)
/P14: J3.9, U3.5 (IO10), U4.17 (P14)
/P15: J3.10, U3.6 (IO9), U4.18 (P15)
/P16: J3.11, U3.8 (IO8), U4.19 (P16)
/P17: J3.12, U3.9 (O7), U4.20 (P17)
/P20: R8.2, U3.17 (IO2), U4.8 (P20)
/P21: R9.1, U3.18 (IO1), U4.9 (P21)
/P22: R10.2, U3.19 (IO0), U4.10 (P22)
/RX: J5.31 (RX), U4.11 (P23)
/R/~W: J5.34 (R/~W), U4.38 (SC2), U5.18 (IO1)
/TX: J5.32 (TX), U4.12 (P24)
/~IRQ_B: J5.40 (~IRQ), R1.1, U9.4
/~IRQ_K: J1.2, JP2.2 (B), U3.16 (IO3)
/~MEMOE: U5.8 (IO8), U7.22 (~OE), U8.32 (~OE)
/~MEMWE: U5.14 (IO5), U7.27 (R/~W), U8.7 (R/~W)
/~RAMCS: U5.9 (O7), U7.20 (~CS)
/~RESET_B: J5.39 (~RESET), R2.1, U9.1
/~ROMCS: U5.6 (IO9), U8.30 (~CE)
/~STBY: D3.3 (K), J5.38 (C2), R6.1, R11.2, U2.2, U4.7 (~STBY)
GND: C1.2, C2.2, C3.2, C4.2, C5.2, C6.2, C7.2, C8.2, C9.2, C10.2, C11.1, C12.1, C13.2, C14.2, D2.1 (K), J1.3, J3.3, J3.4, J5.6 (GND), J5.16 (GND), J5.25 (GND), J5.35 (GND), J6.5 (GND), J8.2, R4.1, R5.1, R8.1, R10.1, SW1.1, U1.1 (GND), U2.3 (GND), U3.10 (GND), U4.1 (VSS), U5.10 (GND), U6.10 (GND), U7.14 (VSS), U8.24 (GND), U9.7 (GND), U9.9, U9.10, U9.12, U9.13, X1.4 (GND)
unnamed: D1.1 (K), J7.2, R6.2
unnamed: D2.2 (A), J8.1, R7.1
unnamed: D3.1 (A), JP1.1 (A), SW1.2, U1.3 (~MR)
unnamed: J2.1, R15.2, U3.13 (SCL)
unnamed: J2.2, R14.2, U3.12 (SDA)
unnamed: J4.1, R13.1, U5.13 (SCL)
unnamed: J4.2, R12.1, U5.12 (SDA)
unnamed: JP2.1 (A), R3.1, U4.4 (~NMI)
unnamed: U1.2 (~RESET), U9.2
unnamed: U3.11 (O6), U9.5
unnamed: U4.3 (EXTAL), X1.5 (OUT)
unnamed: U4.5 (~IRQ1), U9.6
unnamed: U4.6 (~RES), U9.3
unnamed: R5.2, SW2.1, U8.11 (A15)
unnamed: R4.2, SW2.2, U8.10 (A16)

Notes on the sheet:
RESET needs to be asserted a bit longer than STBY to wait for the clock to stabilize.
Memory mapping
Alternate mode selection if not using GreenPAK / PS2
Do not populate if powered through Pico Programmer
2x 5V at bus connector One at PS2 5V
One per GreenPAK VDD*, one for each other IC, except APX811

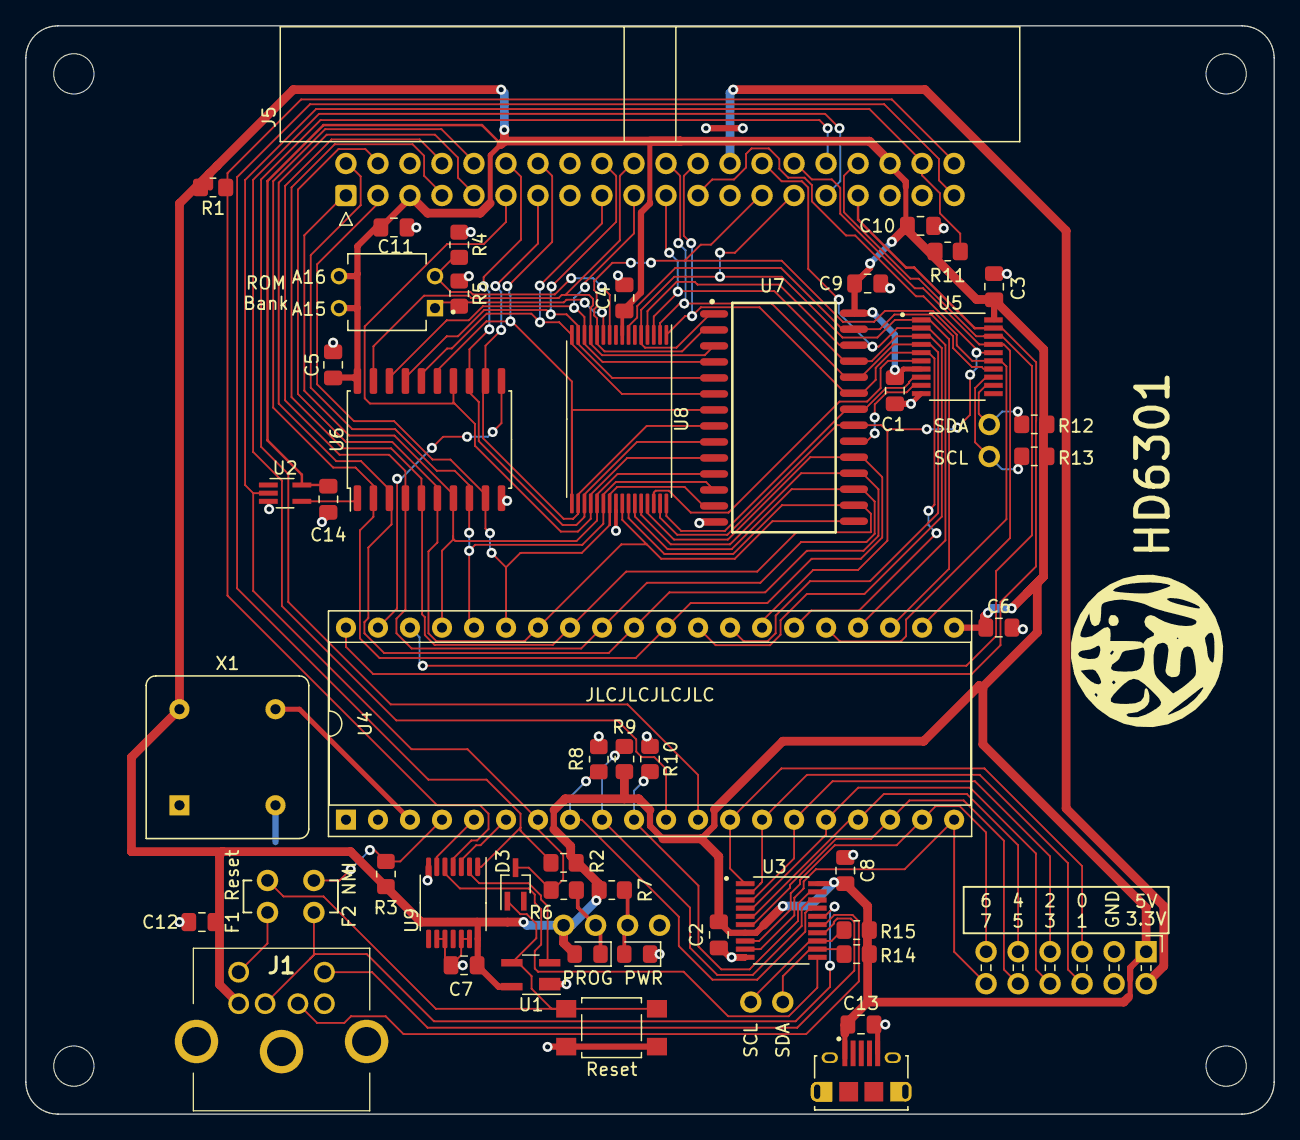
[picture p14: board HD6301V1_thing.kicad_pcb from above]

Board: 2 copper layers, 99.1 x 86.4 mm, 54 parts (0 on the bottom side), 70 nets.

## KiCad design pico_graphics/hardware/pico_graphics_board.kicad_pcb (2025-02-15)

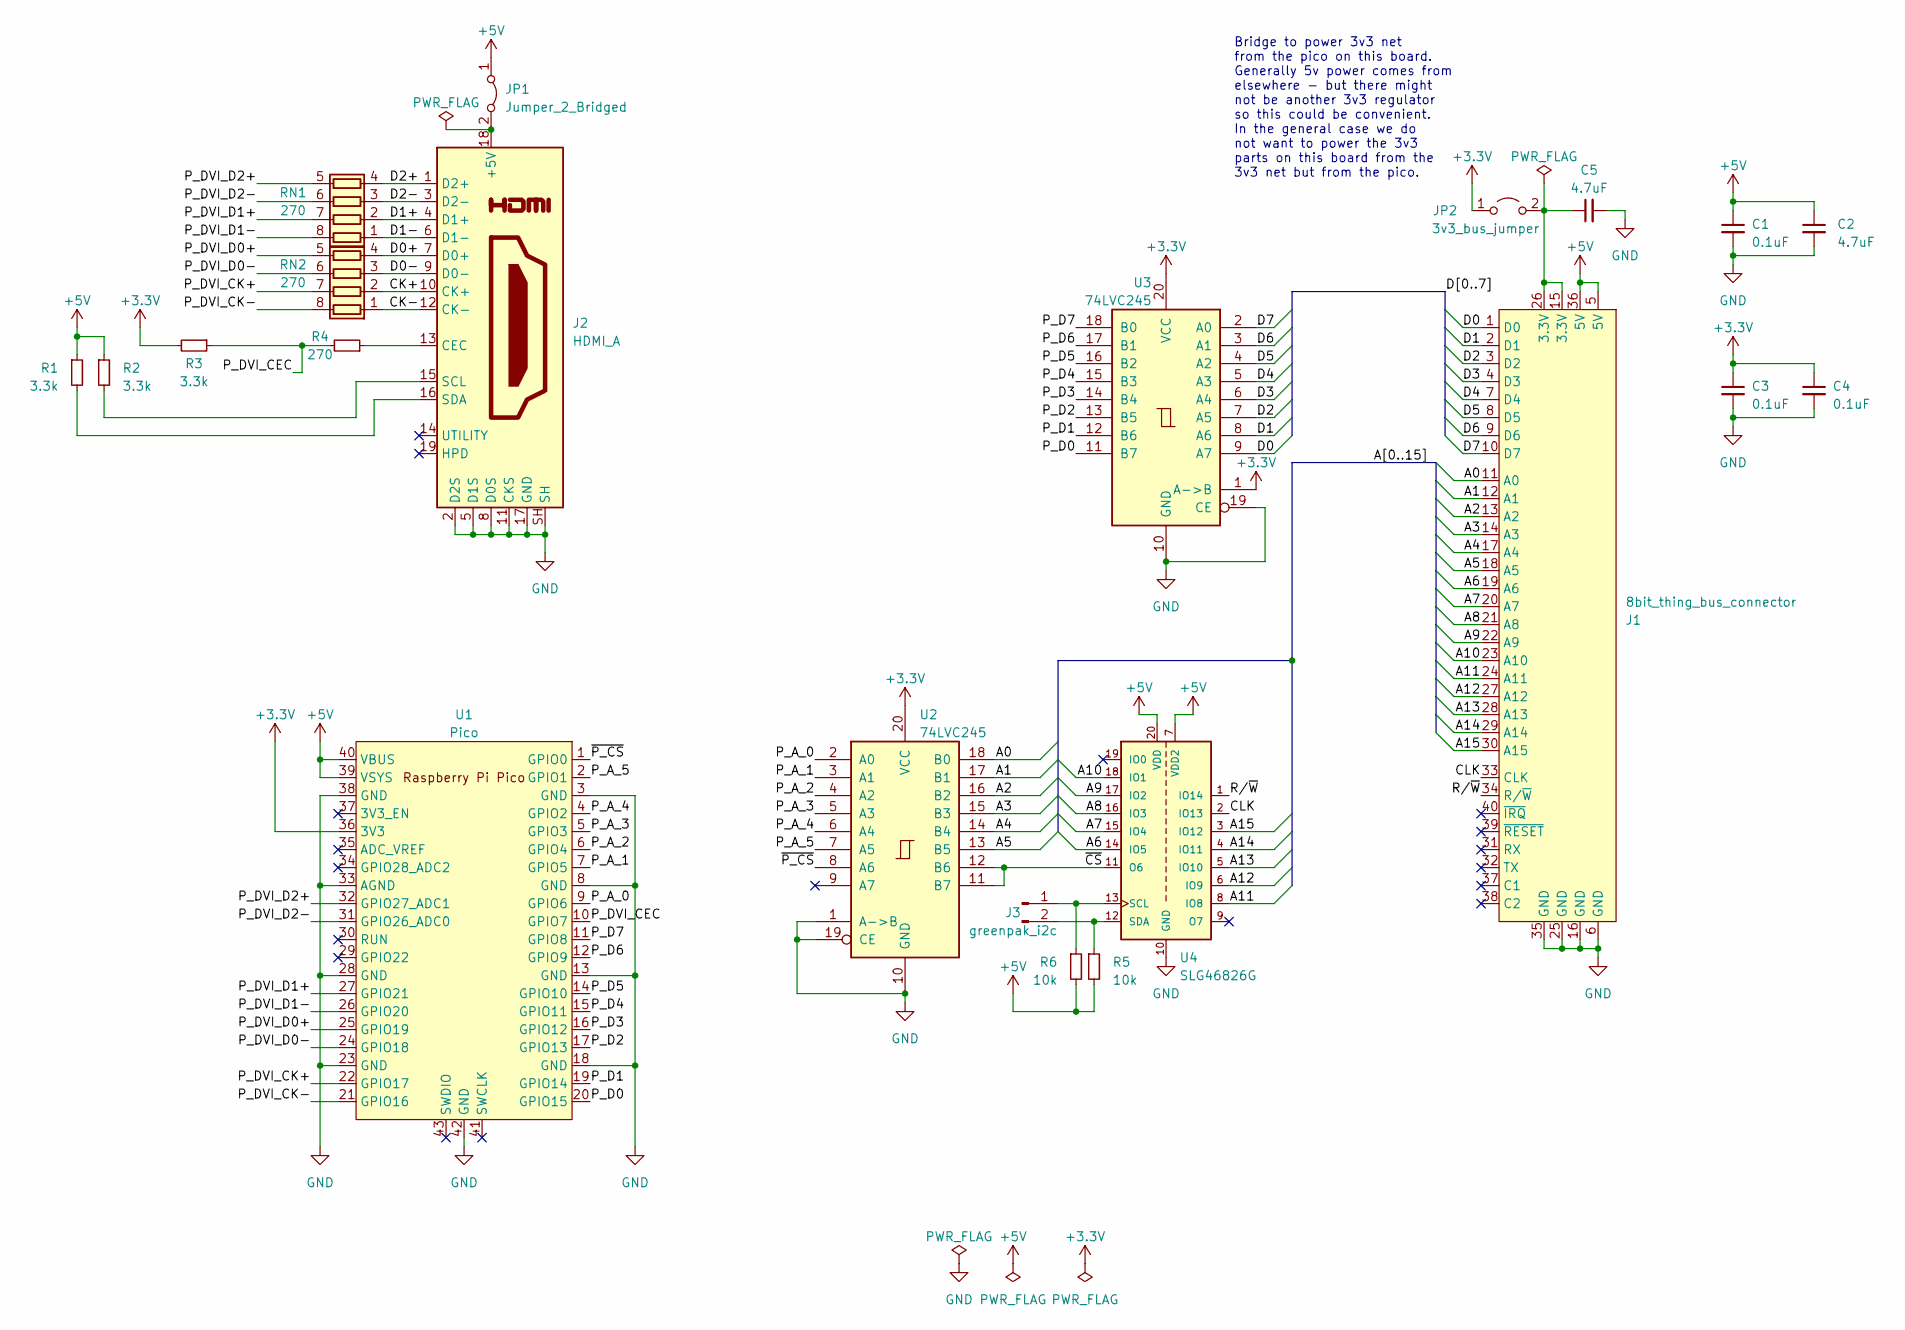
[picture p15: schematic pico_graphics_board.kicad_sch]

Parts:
C1, C3, C4: 0.1uF; C_0805_2012Metric_Pad1.18x1.45mm_HandSolder
C2, C5: 4.7uF; C_0805_2012Metric_Pad1.18x1.45mm_HandSolder
J1: 8bit_thing_bus_connector; IDC-Header_2x20_P2.54mm_Horizontal
J2: HDMI_A; HDMI_A_Amphenol_10029449-x01xLF_Horizontal
J3: greenpak_i2c; PinHeader_1x02_P2.54mm_Vertical_minimal
JP1: Jumper_2_Bridged; R_0805_2012Metric_Pad1.20x1.40mm_HandSolder
JP2: 3v3_bus_jumper; PinHeader_1x02_P2.54mm_Vertical_minimal
R1, R2, R3: 3.3k; R_0805_2012Metric_Pad1.20x1.40mm_HandSolder
R4: 270; R_0805_2012Metric_Pad1.20x1.40mm_HandSolder
R5, R6: 10k; R_0805_2012Metric_Pad1.20x1.40mm_HandSolder
RN1, RN2: 270; R_Array_Concave_4x0603
U1: Pico; RPi_Pico_SMD_TH
U2, U3: 74LVC245; TSSOP-20_4.4x6.5mm_P0.65mm
U4: SLG46826G; TSSOP-20_4.4x6.5mm_P0.65mm; PARTREV 3.10

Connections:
+3.3V: C3.1, C4.1, JP2.1 (A), R3.2, U1.36 (3V3), U2.20 (VCC), U3.1 (A->B), U3.20 (VCC)
+5V: C1.1, C2.1, J1.5 (5V), J1.36 (5V), JP1.1 (A), R1.1, R2.1, R5.2, R6.2, U1.39 (VSYS), U1.40 (VBUS), U4.7 (VDD2), U4.20 (VDD)
/A0: J1.11 (A0), U2.18 (B0)
/A1: J1.12 (A1), U2.17 (B1)
/A2: J1.13 (A2), U2.16 (B2)
/A3: J1.14 (A3), U2.15 (B3)
/A4: J1.17 (A4), U2.14 (B4)
/A5: J1.18 (A5), U2.13 (B5)
/A6: J1.19 (A6), U4.14 (IO5)
/A7: J1.20 (A7), U4.15 (IO4)
/A8: J1.21 (A8), U4.16 (IO3)
/A9: J1.22 (A9), U4.17 (IO2)
/A10: J1.23 (A10), U4.18 (IO1)
/A11: J1.24 (A11), U4.8 (IO8)
/A12: J1.27 (A12), U4.6 (IO9)
/A13: J1.28 (A13), U4.5 (IO10)
/A14: J1.29 (A14), U4.4 (IO11)
/A15: J1.30 (A15), U4.3 (IO12)
/CK+: J2.10 (CK+), RN2.2 (R2.1)
/CK-: J2.12 (CK-), RN2.1 (R1.1)
/CLK: J1.33 (CLK), U4.2 (IO13)
/D0: J1.1 (D0), U3.9 (A7)
/D0+: J2.7 (D0+), RN2.4 (R4.1)
/D0-: J2.9 (D0-), RN2.3 (R3.1)
/D1: J1.2 (D1), U3.8 (A6)
/D1+: J2.4 (D1+), RN1.2 (R2.1)
/D1-: J2.6 (D1-), RN1.1 (R1.1)
/D2: J1.3 (D2), U3.7 (A5)
/D2+: J2.1 (D2+), RN1.4 (R4.1)
/D2-: J2.3 (D2-), RN1.3 (R3.1)
/D3: J1.4 (D3), U3.6 (A4)
/D4: J1.7 (D4), U3.5 (A3)
/D5: J1.8 (D5), U3.4 (A2)
/D6: J1.9 (D6), U3.3 (A1)
/D7: J1.10 (D7), U3.2 (A0)
/P_A_0: U1.9 (GPIO6), U2.2 (A0)
/P_A_1: U1.7 (GPIO5), U2.3 (A1)
/P_A_2: U1.6 (GPIO4), U2.4 (A2)
/P_A_3: U1.5 (GPIO3), U2.5 (A3)
/P_A_4: U1.4 (GPIO2), U2.6 (A4)
/P_A_5: U1.2 (GPIO1), U2.7 (A5)
/P_D0: U1.20 (GPIO15), U3.11 (B7)
/P_D1: U1.19 (GPIO14), U3.12 (B6)
/P_D2: U1.17 (GPIO13), U3.13 (B5)
/P_D3: U1.16 (GPIO12), U3.14 (B4)
/P_D4: U1.15 (GPIO11), U3.15 (B3)
/P_D5: U1.14 (GPIO10), U3.16 (B2)
/P_D6: U1.12 (GPIO9), U3.17 (B1)
/P_D7: U1.11 (GPIO8), U3.18 (B0)
/P_DVI_CEC: R3.1, R4.2, U1.10 (GPIO7)
/P_DVI_CK+: RN2.7 (R2.2), U1.22 (GPIO17)
/P_DVI_CK-: RN2.8 (R1.2), U1.21 (GPIO16)
/P_DVI_D0+: RN2.5 (R4.2), U1.25 (GPIO19)
/P_DVI_D0-: RN2.6 (R3.2), U1.24 (GPIO18)
/P_DVI_D1+: RN1.7 (R2.2), U1.27 (GPIO21)
/P_DVI_D1-: RN1.8 (R1.2), U1.26 (GPIO20)
/P_DVI_D2+: RN1.5 (R4.2), U1.32 (GPIO27_ADC1)
/P_DVI_D2-: RN1.6 (R3.2), U1.31 (GPIO26_ADC0)
/R/~W: J1.34 (R/~W), U4.1 (IO14)
/~CS: U2.11 (B7), U2.12 (B6), U4.11 (O6)
/~P_CS: U1.1 (GPIO0), U2.8 (A6)
GND: C1.2, C2.2, C3.2, C4.2, C5.2, J1.6 (GND), J1.16 (GND), J1.25 (GND), J1.35 (GND), J2.2 (D2S), J2.5 (D1S), J2.8 (D0S), J2.11 (CKS), J2.17 (GND), J2.SH, U1.3 (GND), U1.8 (GND), U1.13 (GND), U1.18 (GND), U1.23 (GND), U1.28 (GND), U1.33 (AGND), U1.38 (GND), U1.42 (GND), U2.1 (A->B), U2.10 (GND), U2.19 (CE), U3.10 (GND), U3.19 (CE), U4.10 (GND)
unnamed: J2.18 (+5V), JP1.2 (B)
unnamed: J2.13 (CEC), R4.1
unnamed: J2.15 (SCL), R2.2
unnamed: J2.16 (SDA), R1.2
unnamed: J3.1, R6.1, U4.13 (SCL)
unnamed: J3.2, R5.1, U4.12 (SDA)
unnamed: C5.1, J1.15 (3.3V), J1.26 (3.3V), JP2.2 (B)

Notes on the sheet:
Bridge to power 3v3 net from the pico on this board. Generally 5v power comes from elsewhere - but there might not be another 3v3 regulator so this could be convenient. In the general case we do not want to power the 3v3 parts on this board from the 3v3 net but from the pico.

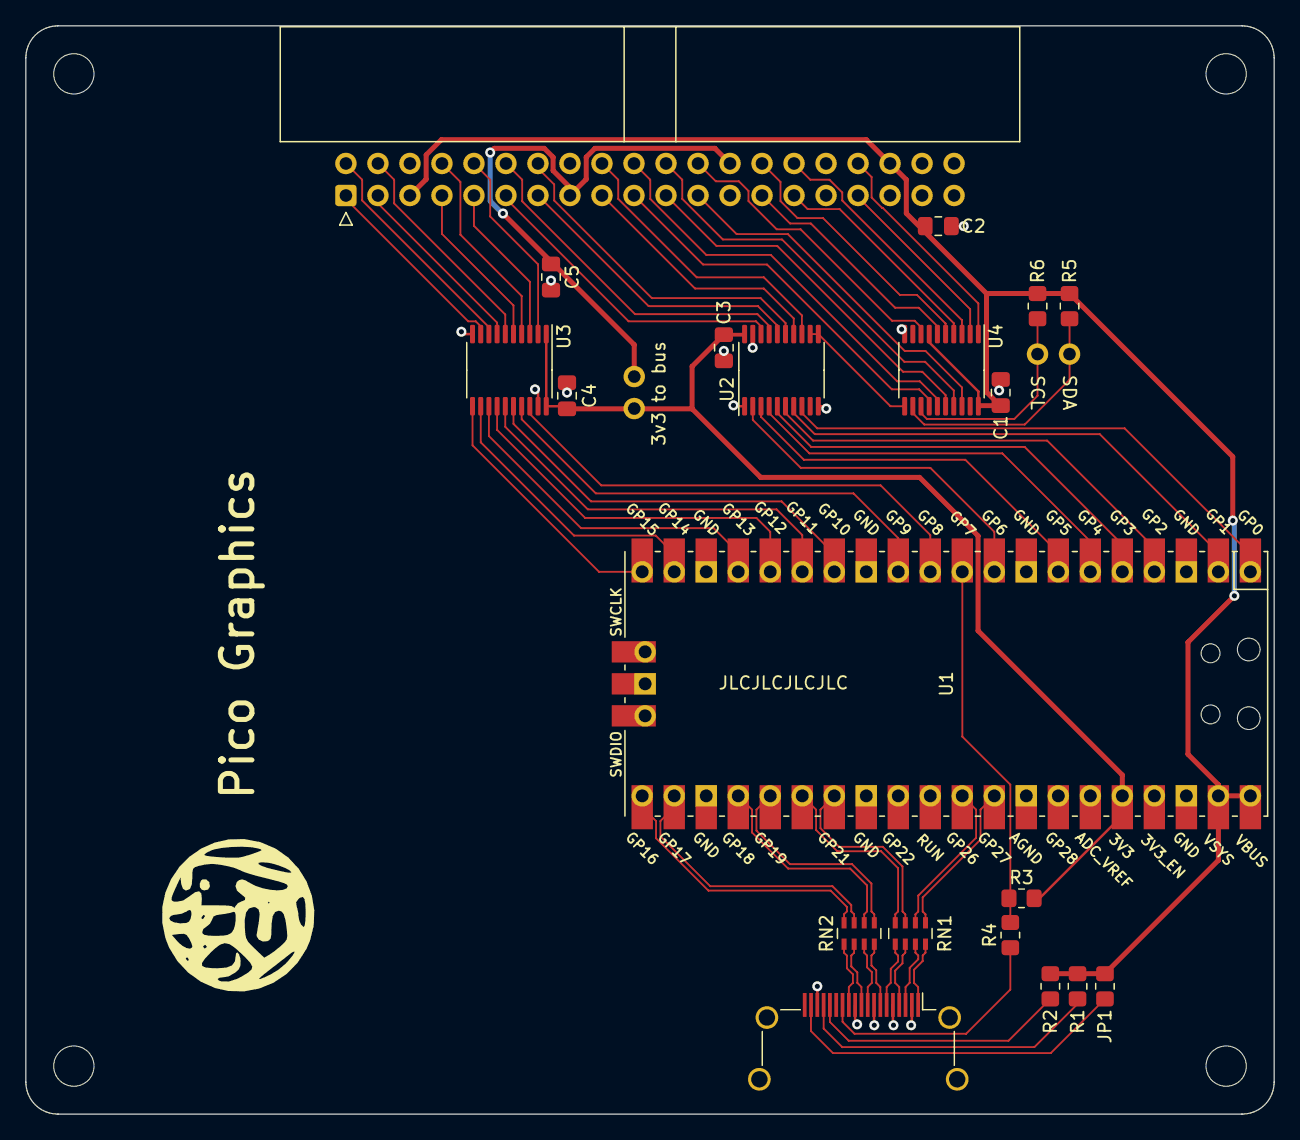
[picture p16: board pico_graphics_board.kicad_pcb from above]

Board: 2 copper layers, 99.1 x 86.4 mm, 22 parts (0 on the bottom side), 69 nets.

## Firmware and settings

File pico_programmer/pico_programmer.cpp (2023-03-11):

#include <cstdint>
#include <cstdio>

#include "hardware/gpio.h"
#include "hardware/uart.h"
#include "pico/binary_info.h"
#include "pico/stdlib.h"
#include "tusb.h"

const uint8_t PROGRAM_CDC = 0;
const uint8_t UART_CDC = 1;

const uint UART0_TX_PIN = 0;
const uint UART0_RX_PIN = 1;

const uint IRQ_PIN = 2;
const uint C1_PIN = 3;
const uint CLK_PIN = 4;
const uint RW_PIN = 5;
const uint STBY_PIN = 26;

const uint ADDR_H_LATCH_PIN = 6;
const uint ADDR_H_LATCH_OE_PIN = 7;
const uint DATA_LATCH_OE_PIN = 16;
const uint DATA_LATCH_PIN = 17;
const uint DATA_BUF_OE_PIN = 18;
const uint ADDR_L_BUF_OE_PIN = 19;
const uint ADDR_L_LATCH_PIN = 20;
const uint ADDR_L_LATCH_OE_PIN = 21;
const uint ADDR_H_BUF_OE_PIN = 22;

// D0...D7 are assumed contiguous in pin numbers, so D0=8...D7=15
const uint DATA_PIN_0 = 8;

const uint LED_PIN = 25;

const uint PIN_MASK_DATA = 0xff << DATA_PIN_0;

const uint PIN_MASK_LATCH_OE = 1 << DATA_LATCH_OE_PIN |
                               1 << ADDR_L_LATCH_OE_PIN |
                               1 << ADDR_H_LATCH_OE_PIN;

const uint PIN_MASK_BUF_OE =
    1 << DATA_BUF_OE_PIN | 1 << ADDR_L_BUF_OE_PIN | 1 << ADDR_H_BUF_OE_PIN;

const uint PIN_MASK_OE = PIN_MASK_LATCH_OE | PIN_MASK_BUF_OE;

const uint PIN_MASK_LATCH =
    1 << DATA_LATCH_PIN | 1 << ADDR_L_LATCH_PIN | 1 << ADDR_H_LATCH_PIN;



const uint PIN_MASK_BUS = 1 << CLK_PIN | 1 << RW_PIN;

const uint PIN_MASK_LED = 1 << LED_PIN;
const uint PIN_MASK_STBY = 1 << STBY_PIN;
const uint PIN_MASK_C1 = 1 << C1_PIN;
const uint PIN_MASK_IRQ = 1 << IRQ_PIN;

const uint PIN_MASK_ALL = PIN_MASK_DATA | PIN_MASK_OE | PIN_MASK_LATCH |
                          PIN_MASK_BUS | PIN_MASK_LED | PIN_MASK_STBY |
                          PIN_MASK_C1 | PIN_MASK_IRQ;

void enter_stby() {
  gpio_put(LED_PIN, 1);
  // Make sure input buffers aren't driving pico D* pins just in case.
  gpio_set_mask(PIN_MASK_BUF_OE);
  // Enter standby.
  gpio_put(STBY_PIN, 0);
  // Data, address latches drive system bus
  gpio_clr_mask(PIN_MASK_LATCH_OE);
}

void exit_stby() {
  gpio_put(LED_PIN, 0);
  // Stop driving bus from pico.
  gpio_set_mask(PIN_MASK_LATCH_OE);
  gpio_put(STBY_PIN, 1);
}

// Turn 8 data bits into a pin bitfield setting the right D* pin values.
uint data_to_mask(uint8_t bits) { return (uint)bits << DATA_PIN_0; }

// Turn a pin bitfield into data bits
uint8_t mask_to_data(uint bitfield) { return (uint8_t)(bitfield >> DATA_PIN_0); }

void set_latch(uint8_t data, uint latch_pin) {
  gpio_put_masked(PIN_MASK_DATA, data_to_mask(data));
  gpio_put(latch_pin, 1);
  busy_wait_us_32(1);
  gpio_put(latch_pin, 0);
}

void set_data(uint8_t data) {
  set_latch(data, DATA_LATCH_PIN);
}

void set_address_low(uint8_t data) {
  set_latch(data, ADDR_L_LATCH_PIN);
}

void set_address_high(uint8_t data) {
  set_latch(data, ADDR_H_LATCH_PIN);
}

void set_address(uint16_t address) {
  set_address_low(address & 0xff);
  set_address_high(address >> 8);
}

uint8_t read_cycle() {
  // Set RW to read
  gpio_put(RW_PIN, 1);
  busy_wait_us_32(1);

  // Pico data pins to input
  gpio_set_dir_in_masked(PIN_MASK_DATA);
  // Disable driving bus data pins from data latch
  gpio_put(DATA_LATCH_OE_PIN, 1);
  // Enable reading from bus data and writing to Pico data pins
  gpio_put(DATA_BUF_OE_PIN, 0);
  // Clock pin high: OE on RAM/ROM gets enabled
  gpio_put(CLK_PIN, 1);
  busy_wait_us_32(1);
  uint8_t data = mask_to_data(gpio_get_all());

  // The same procedure in reverse
  gpio_put(CLK_PIN, 0);
  gpio_put(DATA_BUF_OE_PIN, 1);
  gpio_put(DATA_LATCH_OE_PIN, 0);
  gpio_set_dir_out_masked(PIN_MASK_DATA);

  return data;
}

void write_cycle() {
  gpio_put(RW_PIN, 0);
  busy_wait_us_32(1);
  gpio_put(CLK_PIN, 1);
  busy_wait_us_32(1);
  gpio_put(CLK_PIN, 0);
  gpio_put(RW_PIN, 1);
  busy_wait_us_32(20);
}

void read_data(uint16_t start, uint16_t end) {
  for (uint16_t i = start; i != (uint16_t)(end + 1); ++i) {
    set_address(i);
    putchar(read_cycle());
  }
}

void init_pins() {
  gpio_set_function(UART0_TX_PIN, GPIO_FUNC_UART);
  gpio_set_function(UART0_RX_PIN, GPIO_FUNC_UART);

  // Set to input, clear any output value
  gpio_init_mask(PIN_MASK_ALL);

  // Set every OE pin, STBY, RW high, all others stay clear
  gpio_set_mask(PIN_MASK_OE | PIN_MASK_STBY | 1 << RW_PIN);

  // PIN_MASK_C1 | PIN_MASK_IRQ stay as input. CLK and RW are put into high
  // impedance by the GreenPAK chip depending on STBY state - we can always
  // drive them here.
  gpio_set_dir_out_masked(PIN_MASK_DATA | PIN_MASK_OE | PIN_MASK_LATCH |
                          PIN_MASK_LED | PIN_MASK_STBY | PIN_MASK_BUS);

  // Set STBY, LED values
  exit_stby();
}

void cdc_to_uart_task() {
  if (tud_cdc_n_available(UART_CDC)) {
    uint8_t buf[64];
    uint32_t count = tud_cdc_n_read(UART_CDC, buf, sizeof(buf));
    uart_write_blocking(uart0, buf, count);
  }
}

void uart_to_cdc_task() {
  uint8_t count = 0;
  while (uart_is_readable(uart0) && count < 32) {
    char c = uart_getc(uart0);
    tud_cdc_n_write_char(UART_CDC, c);
    count += 1;
  }
  tud_cdc_n_write_flush(UART_CDC);
}

void programmer_task() {
  int c = getchar_timeout_us(1);
  if (c == PICO_ERROR_TIMEOUT) {
    return;
  }
  switch (c) {
    case 's':
      enter_stby();
      break;
    case 'x':
      exit_stby();
      break;
    case 'd':
      // Set data bits
      c = getchar_timeout_us(10000);
      if (c == PICO_ERROR_TIMEOUT) {
        putchar('e');
        break;
      }
      set_data(c);
      break;
    case 'l':
      // Set low address bits
      c = getchar_timeout_us(10000);
      if (c == PICO_ERROR_TIMEOUT) {
        putchar('e');
        break;
      }
      set_address_low(c);
      break;
    case 'h':
      // Set high address bits
      c = getchar_timeout_us(10000);
      if (c == PICO_ERROR_TIMEOUT) {
        putchar('e');
        break;
      }
      set_address_high(c);
      break;
    case 'w':
      write_cycle();
      break;
    case 'r': {
      int addr_start_l = getchar_timeout_us(10000);
      int addr_start_h = getchar_timeout_us(10000);
      int addr_end_l = getchar_timeout_us(10000);
      int addr_end_h = getchar_timeout_us(10000);
      if (addr_start_l == PICO_ERROR_TIMEOUT ||
          addr_start_h == PICO_ERROR_TIMEOUT ||
          addr_end_l == PICO_ERROR_TIMEOUT ||
          addr_end_h == PICO_ERROR_TIMEOUT) {
        putchar('e');
        break;
      } else {
        putchar('r');
      }
      uint16_t addr_start = addr_start_l + (addr_start_h << 8);
      uint16_t addr_end = addr_end_l + (addr_end_h << 8);
      read_data(addr_start, addr_end);
      break;
    }
    default:
      break;
  }
}

int main(int argc, char* argv[]) {
  bi_decl(bi_program_description("HD6301 programmer."));

  tusb_init();
  // pico_stdio takes over the first CDC
  stdio_init_all();
  // We're transferring binary data. Without this we get extra unwanted bytes.
  stdio_set_translate_crlf(&stdio_usb, false);
  uart_init(uart0, 62500);
  uart_set_translate_crlf(uart0, false);

  init_pins();

  while (true) {
    tud_task();
    cdc_to_uart_task();
    uart_to_cdc_task();
    programmer_task();
  }
  return 0;
}

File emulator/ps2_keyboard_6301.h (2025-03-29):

#ifndef EIGHT_BIT_PS2_KEYBOARD_6301_H
#define EIGHT_BIT_PS2_KEYBOARD_6301_H

#include <SDL3/SDL.h>

#include <queue>

#include "absl/base/thread_annotations.h"
#include "absl/synchronization/mutex.h"
#include "interrupt.h"
#include "ioport.h"

namespace eight_bit {

// Emulates a PS/2 keyboard connected to an 8-bit I/O port for parallel data
// communication (some other hardware converts the serial data to parallel) and
// another I/O port for interrupt handling (data present bit, and a clear signal
// for that bit). Thread safe. This represents the setup for the PS2 port on the
// 6301 CPU board, where the data pins are on one of the 8-bit ports and the IRQ
// logic on port 2.
class PS2Keyboard6301 {
 public:
  PS2Keyboard6301(Interrupt* irq, IOPort* data_port, IOPort* irq_status_port);
  ~PS2Keyboard6301() = default;

  void handle_keyboard_event(SDL_KeyboardEvent event);

  const uint8_t kIrqClearPin = 0;
  const uint8_t kIrqClearMask = 1 << kIrqClearPin;
  const uint8_t kIrqStatusPin = 1;
  const uint8_t kIrqStatusMask = 1 << kIrqStatusPin;

 private:
  Interrupt* irq_ = nullptr;
  IOPort* data_port_ = nullptr;
  IOPort* irq_status_port_ = nullptr;

  absl::Mutex mutex_;
  std::queue<uint8_t> data_ ABSL_GUARDED_BY(mutex_);
  uint8_t interrupt_clear_ ABSL_GUARDED_BY(mutex_) = 0;
  int interrupt_id_ ABSL_GUARDED_BY(mutex_) = 0;
};

}  // namespace eight_bit

#endif  // EIGHT_BIT_PS2_KEYBOARD_6301_H

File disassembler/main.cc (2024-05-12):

#include <cstdint>
#include <fstream>

#include "absl/flags/flag.h"
#include "absl/flags/parse.h"
#include "absl/log/check.h"
#include "absl/log/initialize.h"
#include "absl/log/log.h"
#include "disassembler.h"
#include "instructions6301.h"

ABSL_FLAG(std::string, rom_file, "", "Path to the ROM file to disassemble");

int main(int argc, char* argv[]) {
  absl::ParseCommandLine(argc, argv);
  absl::InitializeLog();

  QCHECK(!absl::GetFlag(FLAGS_rom_file).empty()) << "No ROM file specified.";
  const std::string rom_file_name = absl::GetFlag(FLAGS_rom_file);
  std::ifstream rom_file(rom_file_name, std::ios::binary);
  QCHECK(rom_file.is_open()) << "Failed to open file: " << rom_file_name;
  std::vector<uint8_t> rom_data(std::istreambuf_iterator<char>(rom_file), {});

  eight_bit::Disassembler disassembler;
  QCHECK_OK(disassembler.set_data(0x10000 - rom_data.size(), rom_data));
  QCHECK_OK(disassembler.disassemble());
  std::cout << disassembler.print();

  return 0;
}

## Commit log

2022-10-02 Initial schematic to get an HD6301V1 working on e.g. a breadboard
    [HD6301V1_thing.kicad_pcb, HD6301V1_thing.kicad_sch]
2022-10-08 Update the schematic to use mode 2 and multiplexed P3
    [HD6301V1_thing.kicad_sch]
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2022-11-06 A blink program that gets its parameters from RAM
    This reads the number of delay cycles from 0x0300 which is in RAM. It's useful to test in-circuit memory writing: change 0x0300, see the blinking get faster/slower.
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2022-11-10 Remove CBUS commands from RAM/flash writes
    These are no longer needed now that the FT231X decoder generates standby and
    counter resets from WR strobes.
    [programmer.py]
2022-11-10 Workaround for pyftdi bug that leaves the serial interface with high latency
    On close pyftdi sets the latency to the max value of 255 instead of the default
    16. This leaves the serial port in a super annoying state.
    [programmer.py]
2022-12-04 Fix race condition on entering STBY
    The MCU latches STBY with E, which means it can take a bit over one E cycle to
    fully enter standby. The current decoder code tries to drive AS immediately
    after it pulls STBY low - and it can't move it vs the MCU. Programming on the
    first command only works if 'AS' just so happens to be at the right level
    already.
    This code makes the first WR strobe (after a 250ms cooldown) affect the STBY pin
    only. We need a tiny bit of extra code to enter STBY now, but on the plus side
    this should also allow implementing a 'reset' command withing driving the bus in
    any way.
    [programmer.py]
2022-12-04 Add a reset command to the programmer
    [programmer.py]
2022-12-21 Add USB and P2.0-P2.2 setup
    [HD6301V1_thing.kicad_sch]
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2023-01-28 GreenPAK project and nvram for the pico programmer helper
    The greenpak chip does 3.3/5V conversion and tri-states various shared signal
    lines.
2023-01-28 Mostly finished schematic and fully routed board - a few TODOs remaining
    [HD6301V1_thing.kicad_pcb, HD6301V1_thing.kicad_sch]
2023-01-29 Add a TODO for i2c pullups in board schematic
    [HD6301V1_thing.kicad_sch]
2023-01-31 Add the ability to reset the chip to greenpak programmer
    [greenpak_programmer.py]
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2023-02-13 Finished HD6301 board
    [HD6301V1_thing.kicad_pcb, HD6301V1_thing.kicad_sch]
2023-02-14 Update board files to Kicad 7.0
    [HD6301V1_thing.kicad_pcb, HD6301V1_thing.kicad_sch]
2023-02-17 Update schematic for new Greenpak symbol and some small changes to the PCB
    [HD6301V1_thing.kicad_pcb, HD6301V1_thing.kicad_sch]
2023-02-17 Flip two pico programmer pins - makes routing the programmer board easier
    [pico_programmer.cpp]
2023-02-17 pico programmer board schematic and PCB
    [programmer_board.kicad_pcb, programmer_board.kicad_sch]
2023-02-17 Some small improvements to HD6301 PCB
    [HD6301V1_thing.kicad_pcb, HD6301V1_thing.kicad_sch]
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2023-02-19 Replace IRQ/RESET AND IC with a Schmitt-trigger one
    [HD6301V1_thing.kicad_pcb, HD6301V1_thing.kicad_sch]
2023-02-19 Pico programmer: remove some redundant traces and fix 3d model
    [programmer_board.kicad_pcb]
2023-02-19 Fix missing pullup on STBYB
    [HD6301V1_thing.kicad_pcb, HD6301V1_thing.kicad_sch]
2023-02-19 HD6301 board: small routing improvements
    [HD6301V1_thing.kicad_pcb]
2023-02-19 pico board: add more bypass caps, add JLCPCB string
    [programmer_board.kicad_pcb, programmer_board.kicad_sch]
2023-02-19 HD6301 board: add GreenPAK i2c pullups
    [HD6301V1_thing.kicad_pcb, HD6301V1_thing.kicad_sch]
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2023-02-19 Pico board: add i2c pullups
    [programmer_board.kicad_pcb, programmer_board.kicad_sch]
2023-02-20 pico board: low address latch needs independent OE to not conflict with latch on HD6301 board
    [programmer_board.kicad_pcb, programmer_board.kicad_sch]
2023-02-21 HD6301 board: tie address latch OE to standby
    This makes the address latch let go of the bus on standby which simplifies the
    pico programmer.
    [HD6301V1_thing.kicad_pcb, HD6301V1_thing.kicad_sch]
2023-02-23 Final version of HD6301V1 v1 board
    [HD6301V1_thing.kicad_pcb, HD6301V1_thing.kicad_sch]
2023-02-23 Completely reworked Pico programmer v1 board - final version
    [programmer_board.kicad_pcb, programmer_board.kicad_sch]
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2023-03-11 HD6301 board: fix swapped SC1/SC2 pins
    [HD6301V1_thing.kicad_pcb, HD6301V1_thing.kicad_sch]
2023-03-11 Pico programmer: fix read sequence
    [pico_programmer.cpp]
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2023-03-11 HD6301 board: remove v1 gerber as it's buggy
    The file can always be recovered from the history but this avoids accidentally
    ordering a version with bugs.
2023-03-11 Add a warning to pico board about missing pullups
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2023-03-26 Initial schematic for the pico graphics board
    Needs a lot of cleanup, but it's working on a breadboard.
    [pico_graphics_board.kicad_pcb, pico_graphics_board.kicad_sch]
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2023-04-07 Schematic and routed board for pico graphics
    The board is looking good, but we moved quite a few pins around to make routing
    easier. This needs testing before sending it to be manufactured.
    [pico_graphics_board.kicad_pcb, pico_graphics_board.kicad_sch]
2023-04-07 Fix resistor network footprint size
    Kicad footprints are confusingly labeled by the individual resistor size as
    opposed to the size of the full package - so 4x1206 means 'as big as 4x 1206
    resistors' not as big as one 1206 as is used in manufacturers' datasheets.
    [pico_graphics_board.kicad_pcb, pico_graphics_board.kicad_sch]
2023-04-15 Final pico graphics v1.0 board
    [pico_graphics_board.kicad_pcb, pico_graphics_board.kicad_sch]
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2023-04-17 Improve pico graphics software
    - updated pins to match pico graphics v1.0 board
    - added various clear and send raw commands
    - display the cursor position with inverted colors
    [pico_graphics.cpp]
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2023-04-30 Make zp_var avoid monitor variables in user programs
    This puts zp_var_addr offsets into monitor.inc and adjusts the macro to take
    this into account when it's assembled as part of user programs.
2023-04-30 The beginnings of a 'snake' clone
    Right now this draws a map, a snake, and allows moving the snake around with
    arrow keys. It does collision detection against self and walls.
    It's missing food, game ticks from a timer, scoring, and some polish.
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2023-06-04 Beginnings of an OPL3-based sound card
    - GreenPAK design for memory decoding and turning R/W into separate read/write
    signals.
    - A basic initial schematic that works on a breadboard. It's missing the
    amplifier section, but that's basically 1:1 from the LM386 datasheet.
    - An opl3.py program with a simple serial protocol to send data to the OPL3. It
    can act as a bare-bones VGM player.
    [opl3_sound.kicad_pcb, opl3_sound.kicad_sch]
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2023-07-02 ASM: functions to play/stop a given MIDI note on a given channel
    The main trick here are lookup tables for FNUM/BLOCK to avoid having to calculate what these would be on the fly. The tables are tuned so MIDI 69 = A4 = 440Hz comes out correctly when using the 13MHz crystal that's on my breadboard right now. This will need fixing when using an up-to-spec 14.32 MHz crystal.
2023-07-02 opl3.py: fix an off-by-one-octave bug
    [opl3.py]
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2023-07-15 ASM graphics: fix a cursor hide bug on init
    The clear takes long enough that the pico misses the subsequent cursor show
    command. Flipping the order fixes that.
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2023-07-16 ASM: fix a corner case where graphics_putchar would clobber A
2023-08-01 OPL3: Add LM386-based audio amplifier section to the schematic
    We could use something more modern - but why not go with late 70's tech for
    amplifiers too? (Ignoring the mid-90s FM chip!).
    [opl3_sound.kicad_sch]
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2023-10-24 Schematic / PCB / Gerbers for v2 of the OPL3 board
    [opl3_sound.kicad_pcb, opl3_sound.kicad_sch]
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2023-12-10 First draft schematic for a MIDI board
    [midi_board.kicad_pcb, midi_board.kicad_sch]
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2023-12-28 MIDI board v1 schematic & PCB
    [midi_board.kicad_pcb, midi_board.kicad_sch]
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2023-12-29 Final v1 version of the MIDI/UART board
    - Tightened the layout a bit
    - Added jumpers to select whether the second MIDI port is OUT or THRU
    - Moved jumpers for system RX/TX connection to a better place
    - Added labels for everything on the silkscreen
    [midi_board.kicad_pcb, midi_board.kicad_sch]
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2024-01-03 MIDI board: remove outdated comment from schematic
    [midi_board.kicad_sch]
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2024-01-06 Fix reset issue for the MIDI board
    There are some reset issues with the TL16C2550. This change makes it so that the
    RESET line is held high for a few ms after power-on before going low. That seems
    to get rid of some weirdness. There is some speculation online that the chip
    needs to see a low-to-high transition to properly reset - that might be a future
    improvement if this ends up being flaky. None of this is documented in the
    datasheet.
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2024-02-17 MIDI synth: intial MIDI velocity implementation
    The volume algorithm doesn't sound great yet, it gets soft a bit too fast.
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2024-02-24 Update OPL3 board schematics for lower amplification settings
    The 5x for both speaker and headphones is too much. It's now 1.3 and no
    amplification at all.
    [opl3_sound.kicad_sch]
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2024-03-29 Fix emulator cpu tick() to actually fetch new opcodes
    [cpu6301.cc]
2024-03-31 Cpu6301: fix 'tim' instruction implementation
    [cpu6301.cc]
2024-03-31 Emulator: replace printfs by absl logging, and add some more vlogs
    [cpu6301.cc]
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2024-03-31 Fix assignment bug in Cpu6301::add() function
    [cpu6301.cc]
2024-04-01 Emulator: stop timer before shutdown
    The separate timer thread causes deinitialization order issues on shutdown.
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2024-04-02 Emulator: define 0 as an invalid interrupt id
    This avoids the need to track the interrupt status separately.
    [ps2_keyboard.h]
2024-04-02 Fix incorrect parameter order in ABA instruction
    [cpu6301.cc]
2024-04-02 Emulator: reset CPU on invalid instruction
    This makes bad instructions much more evident and mimics the actual CPU behavior more closely (almost - there is a separate reset vector for that).
    [cpu6301.cc]
2024-04-02 Fix addition bug in Cpu6301::addd() method
    [cpu6301.cc]
2024-04-02 Fix STX opcode mnemonic in Cpu6301
    [cpu6301.cc]
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2024-04-12 Emulator: enable warnings and fix all issues they flagged
    [cpu6301.cc]
2024-04-12 Emulator: enable many clang-tidy checks and fix the findings
    [cpu6301.cc]
2024-04-12 Emulator: refactor AddressSpace to use absl::Status for error handling
    This is step 1 to making everyone do proper error checking and propagation.
    [cpu6301.cc]
2024-04-13 Refactor Cpu6301 class to use factory function and absl::StatusOr for error handling
    [cpu6301.cc]
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2024-04-13 Emulator: fix bugs in 'lsrd' and 'asld' instructions
    [cpu6301.cc]
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2024-04-14 Asm: fix small bugs in snake.s
    - One is a write into randomness due to a clobbered X register
    - The other is undefined behavior. 'inc' does a read before incrementing, but the graphics registers can't be read. Most of the time a random value will work correctly (the pico code accepts any non-zero value as 'hidden') - but if it happens to be 255 the cursor doesn't get hidden.
2024-04-14 Emulator: use poll() in TL16C2550 read thread to avoid busy-looping
2024-04-14 Emulator: use poll() and a read thread for the HD6301Serial class
    Checking for read() once per tick is expensive, this avoids that cost.
2024-04-14 Emulator: fixes to make the code compile with clang++ and strict warnings as errors
    Turns out clang is a bit more aggressive about undefined variables. There is also some weirdness about undefined references to operator<< on LOG()s with uint8/16_t that needs to be worked around.
    [cpu6301.cc]
2024-04-15 Emulator: switch to Abseil as a submodule
    This allows building Abseil with TSan support for example and avoids an extra
    dependency which might not be very common.
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2024-04-24 Add top-level CMakeLists.txt as well as one for disassembler/
    This is needed to avoid having two copies of Abseil. It also makes switching directory easier.
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2024-05-01 Emulator: add SDCardSPI class for SD card SPI emulation
    This contains enough code to get through SD card initialization. It doesn't yet have any actual data read or write support.
    [sd_card_spi.cc]
2024-05-02 Emulator: correctly return 'illegal' for unknown SD commands
    [sd_card_spi.cc]
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2024-05-12 Emulator: small readability fixes in SD Card emulation
    [sd_card_spi.cc]
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2024-05-12 Disassembler: fix off-by-one in printing of aim/oim/eim/..
2024-05-12 Disassembler: fix small spacing issue when printing data
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2024-06-02 Emulator: fix 'subd' not setting status register correctly
    [cpu6301.cc]
2024-06-02 Monitor: speed up 'cat' and support reads over 512 bytes
    - The printing code is a few cycles per byte faster as it avoids cpx in favor of
    using B as a loop counter.
    - Use 'file_at_eof' to check if further 'file_read' calls are needed.
    (file_read can't actually do reads past 512 yet and returns an error, but if it
    did, cat would work)
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2024-07-07 Monitor: fix a stack memory leak in 'continue'
    Fixes a bug where interrupting and continuing a program leaves an unused return
    address out of continue on the monitor stack.
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2024-11-08 Add timer functionality to W65C22 emulation
    This adds much of the pure timing functionality of timer1 / timer2. It doesn't
    do any of the I/O related stuff like pulse counting.
    [cpu6301.cc, w65c22.h]
2024-11-08 ASM: Fix read of the last sector for files of size k*512 bytes
    If the last sector was exactly 512 bytes the current code returned a size 0 read
    instead of 512.
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2024-11-09 Fix TSAN builds
    For TSAN to see absl::Mutex annotations, Absl needs to be built with
    -fsanitize=trhead too. This used to be the case when Abseil was nested in the
    emulator folder, but got broken when moving to the separate 'dependencies' one.
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2024-11-09 Fix a few clang-tidy warnings
    [cpu6301.cc, spi.cc]
2024-11-09 Emulator: increase preformance by avoiding some expensive locking
    A good 25% of emulator time is spent just locking locks on each tick to find out
    whether we have interrupts or whether there is serial data waiting. These
    conditions are almost always false and we can drastically improve performance by
    replacing them with an atomic flag that is much cheaper to test in the false
    case.
2024-11-09 Emulator: improve performance by avoiding redundant lookups
    Before this we looked up each instruction 4 times: twice each in tick() and
    execute(). In each of these we did a contains() to figure out if the instruction
    is valid, followed by a lookup of the actual instruction. Replacing them with
    one find() and some const references gets rid of 3 lookups and two Instruction
    creation/destructions too.
    [cpu6301.cc]
2024-11-09 Emulator: improve performance by removing instruction map
    The instruction lookups in std::map made up ~35% of the cost of tick(). This
    removes the map in favor of an std::array. The implementation now looks a bit
    wonky as we still initialize a map just to copy it all over into an array. To be
    fixed at some point in the future.
    [cpu6301.cc]
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2024-11-23 Initial schematic for an SD Card interface board
    [io_board.kicad_pcb, io_board.kicad_sch]
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2024-12-20 Update schematic for IO board
    [io_board.kicad_sch]
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2024-12-21 ASM io: fix handling of timer1 interrupts and improve init code
    - Fix a bne where a beq should have been in IRQ handling. The datasheet isn't
    - super clear on the state of the ACR/PCR registers after a reset. These changes
    makes sure that they are in a known state.
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2024-12-22 Update IO board schematic and check in the necessary GreenPAK files
    The io_spi_delay is built for a breadboard version using a '595 instead of a
    '164, see the note in the schematic. It has an additional (further) delayed
    clock line for the '595 register clock so we can shift and present the data in
    the same PHI2 cycle.
    [io_board.kicad_sch]
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2024-12-27 W65C22 emulation: fix shift register, add IRQs
    [w65c22.h]
2024-12-27 Fix 65C22 tests after timer precision changes
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2025-01-02 Fix W65C22 emulation: the shift register is MSB- not LSB-first
    This also adds separate constants for pin numbers vs port masks to avoid
    confusion.
    [w65c22.h]
2025-01-02 Add emulation for the 65C22 shift register to SPI adapter logic
    This implements emulation for:
    - inverting and delaying the shift register clock
    - MISO-to-parallel conversion clocked by that same clock
    [w65c22_to_spi_glue.h]
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2025-01-19 IO board: update the schematic to use '595 for SD Card --> 65C22 comms
    [io_board.kicad_sch]
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2025-01-26 Emulator: Make the IOPort API more explicit and more complete
    The current API makes a mess of read/write and input/output. After this rename
    it should be clearer how one has to interact with a port.
    The current API also doesn't offer a way to drive input pin changes nor register
    interest in those input changes. This is now addressed too.
    [cpu6301.cc, spi.cc, spi_test.cc]
2025-01-26 IOPort: Add a mask parameter to provide_inputs()
    This makes it easier to implement situations with multiple devices on the same
    port. Without this, anyone with access to the port and using provide_inputs()
    would have to coordinate somehow to avoid trampling on each-other's bits.
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2025-02-13 I/O Board: update schematic to add PS2 keyboard interface
    This is very likely not the final pin assignment, but it's a base to start
    breadboarding.
    [io_board.kicad_sch]
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2025-02-15 Update all Kicad files to the Kicad8 format
    This was done by opening each file and saving it without any changes.
    [HD6301V1_thing.kicad_pcb, HD6301V1_thing.kicad_sch, midi_board.kicad_pcb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]
2025-03-08 ASM: Add support for a PS2 keyboard sharing I/O on the 65C22 with the SD card
    This isn't quite working yet. For some reason the keyboard stops working after a
    bit because the 65C22 stops creating interrupts despite seeing CA1
    transitions. Not clear if it's a software or hardware issue.
2025-03-08 Update IO board schematic
    [io_board.kicad_sch]
2025-03-29 Update IO Board schematic to Kicad 9 format
    [io_board.kicad_sch]
2025-04-12 Ensure the data present bit is always cleared in 6301 keyboard emulation
    In the current code this can get stuck on. It used to be cleared because the
    6301 keyboard always got data when the IRQ code fired. That's not longer the
    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
2025-04-12 65c22 emulation: fix non-firing CA1 interrupts
2025-04-24 Add a KiCad template for a new board
    [board_template.kicad_pcb, board_template.kicad_sch]
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2025-04-26 Mostly routed IO board
    It's still missing:
    - An i2c timer
    - All the sanity checks
    - Making all GreenPAK code match the schematic. Many pins were moved for easier
    routing.
    - Aligning the PS2 port with other ports on other boards.
    [io_board.kicad_pcb, io_board.kicad_sch]
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2025-07-07 Fix BITB instruction and add tests
    Corrects the BITB instruction implementation to use accumulator B instead of A. Adds unit tests for the AND and BIT instructions to verify their functionality and cover different addressing modes.
    AI-generated
    [cpu6301.cc]
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2026-03-22 Fix unreadable test names in CTest output
    Add PrintTo(InstructionTestCase) so GoogleTest prints 'file/name'
    instead of dumping 240 raw struct bytes for each parameterized test.
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2026-04-03 Implement missing CPU instructions: daa, slp, wai, swi
    - daa: decimal adjust A using H and C flags per 6801 spec
    - slp: halt CPU until unmasked interrupt; tick loop advances peripherals
    - wai: pre-stack all registers then halt; interrupt entry skips re-stacking
    - swi: stack all registers, set I, jump via SWI vector at 0xFFFA
    Add declarative instruction tests for all four.
2026-04-03 Modernize build system and C++ style
    - Bump cmake_minimum_required to 3.20 across all subprojects
    - Remove stale SDL2_INCLUDE_DIRS; imgui now links SDL3::SDL3 properly
    - Replace add_definitions with target_compile_definitions (scoped)
    - gperftools: find_library with FATAL_ERROR if not found when enabled
    - Replace typedef with using in address_space.h, ioport.h, spi.h
    - Fix README.md SDL2→SDL3
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2026-04-04 Add rtc.inc: MCP7940N library
    Provides rtc_init (enables oscillator and VBATEN) and rtc_get_time
    (reads BCD sec/min/hour into rtc_seconds/rtc_minutes/rtc_hours in
    system memory) using the i2c_* primitives exported from the monitor.
2026-04-04 Add clock program
    Press 't' to print the current time as HH:MM:SS (BCD from the RTC,
    displayed correctly via putchar_hex). Press 'q' to exit.
2026-04-05 MCP7940N: fix SDA release timing for LSB; add unit tests
    The slave was releasing SDA on the rising edge of the 8th bit clock,
    which meant the master could no longer sample the LSB reliably — by the
    time SCL rose, SDA had already been released (floating high). Fix: hold
    SDA until the *falling* edge of the master's ACK/NACK clock (kMasterAcking
    falling), which is when the master is about to drive its own ACK/NACK.
    13 new unit tests cover the full I2C read/write flow including multi-byte
    sequential reads and the exact LSB timing that triggered this bug.
2026-04-05 i2c: fix ACK/NACK detection clobbered by i2c_scl_low
    i2c_read_byte saved the ACK/NACK flag on the stack, ran the 8-bit receive
    loop (which exits with Z=1 from the final DEX), then called i2c_scl_low to
    lower SCL before testing the flag.
    i2c_scl_low expands to "ora b,#I2C_SCL; stb IO_DDRA". STB sets condition
    codes based on B (non-zero), clearing Z to 0. Since PULA does not restore
    condition codes on the HD6301, the subsequent BNE always branched to the
    NACK path regardless of the saved flag value — so every i2c_read_byte call
    with ACK (A=0) was sending NACK instead, terminating the sequential read
    after the first byte.
    Fix: add TST A after PULA to update CC from A's actual value.
    Co-A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
2026-04-06 asm/tests: add FAT16 filesystem unit test suite (65 tests)
    Tests call HD6301 assembly subroutines directly via the C++ emulator:
    the ROM binary is loaded into a flat address space, a sentinel return
    address is pushed onto the stack, and the CPU is ticked until it lands
    there. The SD card read stub is patched to CLRA+RTS so tests can
    pre-populate buffers without touching the block layer.
    Coverage across 9 test fixtures:
    ValidateNameTest — length limits, null termination, empty string
    FileInitTest — BPB parsing, spc-mask computation, error paths
    FindDirEntryTest — exact/prefix match, attr mask, deleted entries
    FileOpenTest — FD allocation, not-found error, bot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
